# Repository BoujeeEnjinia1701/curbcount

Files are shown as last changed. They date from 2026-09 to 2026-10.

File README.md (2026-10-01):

# CurbCount

     

**Area:** Smart Cities · **TRL:** 3 of 9 (proof of concept on paper) · **Value-engineering target:** about $275 USD · **Difficulty:** 3 of 5

A privacy-safe counter for people, bicycles and vehicles at street level that uses on-device detection and sends only counts, never images.

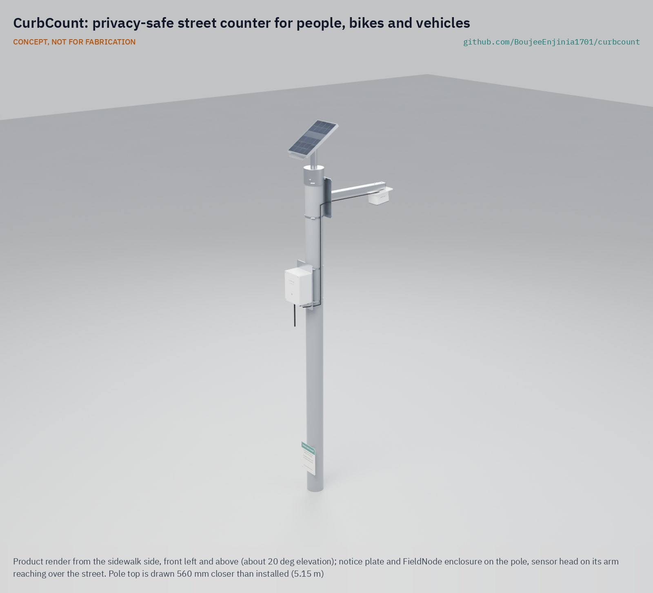
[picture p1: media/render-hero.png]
CurbCount: privacy-safe street counter for people, bikes and vehicles, product render


[Exploded render](media/render-exploded.png) · [Detail render](media/render-detail.png) · [Interactive 3D model](media/viewer.html) · [Concept blueprint (PDF)](media/concept-blueprint.pdf) · [General arrangement (PDF)](cad/drawings/CBC-DWG-001.pdf) · [Prototype build plan](docs/05-build-plan.md) · [Design decisions](docs/06-design-decisions.md) · [Calculations](docs/04-calcs/01-sizing.md) · [Review note](docs/REVIEW.md)

## Concept rationale

Counts without images give planners evidence while respecting residents. CurbCount uses a 32 x 24 pixel thermal array instead of a camera: from 4.3 m up it images a person's head at about 7.6 pixels per meter (8.5 for a 2 m person) and a number plate at under 2 pixels, so the sensor cannot capture a face or a plate even if its firmware were changed. The FieldNode core's own processor turns heat blobs into counts of people, cyclists and vehicles by direction, and only 15-minute counts leave the device.

It is open and garage-buildable because trust is the point. A city, a residents' group or a researcher can read the firmware, inspect the hardware and build their own from off-the-shelf parts, clamped to an existing pole on the lab's shared FieldNode power and radio core.

## Burning platform

Street redesign decisions are contested, and counts of people walking and cycling are usually missing. Road crashes kill about 1.19 million people a year, and more than half are pedestrians, cyclists and motorcyclists; pedestrians alone are 23 % and cyclists 6 % ([WHO, 2023](https://www.who.int/news/item/13-12-2023-despite-notable-progress-road-safety-remains-urgent-global-issue)). WHO also reports that 80 % of the world's roads fail to meet pedestrian safety standards (same source), and 92 % of road deaths occur in low- and middle-income countries ([WHO fact sheet](https://www.who.int/news-room/fact-sheets/detail/road-traffic-injuries)).

Fixing streets for people on foot and on bicycles needs evidence of how many use them, before and after a change. Motor traffic is counted routinely; walking and cycling rarely are, and the camera systems that could count them raise privacy concerns that stall deployment. The global goal of at least halving road deaths and injuries by 2030 ([WHO Global status report on road safety 2023](https://www.who.int/publications/i/item/9789240086517)) leaves little time.

## Where it could be used

### By industry

| Industry | Use |
| --- | --- |
| Municipal transport planning | Before and after counts for new bike lanes, wider sidewalks and school streets |
| Road safety engineering | Pedestrian and cyclist exposure at crossings, to turn crash counts into risk rates (with CrossSafe) |
| Retail and business districts | Footfall by hour and day on high streets and markets |
| Parks, trails and tourism | Use of promenades, greenways and trail heads without cameras |
| Transit operators | Walking and cycling flows on station access routes |
| Research and education | Open, reproducible active travel counts for universities and schools |

### By country or region

| Country or region | Why it matters there |
| --- | --- |
| Sub-Saharan Africa | More than a billion people in Africa walk or cycle every day, about 56 minutes a day against a global average of about 44 minutes, yet most countries lack policies and budgets for them ([UNEP](https://www.unep.org/resources/report/walking-and-cycling-africa-evidence-and-good-practice-inspire-action)) |
| India | Road crashes took about 300,000 lives in 2016, and most of those dying are pedestrians, cyclists and motorcyclists ([WHO India](https://www.who.int/india/health-topics/road-safety)) |
| Latin America and the Caribbean | In the Americas, motorcyclists, pedestrians and cyclists rose from 39 % to 47 % of road deaths between 2009 and 2021 ([PAHO](https://www.paho.org/en/topics/road-safety)) |
| United States | 7,522 pedestrians were killed in 2022, 18 % of all traffic deaths ([NHTSA](https://crashstats.nhtsa.dot.gov/Api/Public/ViewPublication/813590)) |
| England | Walking is 29 % of all trips and cycling 2 % ([Department for Transport, 2024](https://www.gov.uk/government/statistics/walking-and-cycling-statistics-england-2023)); councils need counts to justify active travel schemes |
| European Union | Data protection by design is a legal duty ([Regulation (EU) 2016/679, Article 25](https://eur-lex.europa.eu/eli/reg/2016/679/oj); [text of Article 25](https://gdpr-info.eu/art-25-gdpr/)), which favors counters that cannot capture personal data at all |

## What sparked the idea

The idea traces back to Toronto's Quayside waterfront project. In October 2018 Ann Cavoukian, the former Ontario privacy commissioner who wrote the privacy-by-design framework the project had adopted, resigned as its adviser because the proposed data trust could approve collection of data that was not de-identified at source. In her resignation letter she warned that such data would create "another central database of personal information (controlled by whom?)" ([The Globe and Mail, 2018](https://www.theglobeandmail.com/business/article-privacy-expert-ann-cavoukian-resigns-from-sidewalk-toronto-smart-city/)). CurbCount takes the lesson literally: de-identification at source should be a property of the sensor, not a policy promise, so it uses a sensor too coarse to capture a face in the first place.

## Problem

Cities plan streets with little data on walking and cycling, and camera-based counting raises privacy concerns.

## Concept

A privacy-safe counter for people, bicycles and vehicles at street level that uses on-device detection and sends only counts, never images.

A thermal array on a short arm looks down over the sidewalk, bike lane and nearest traffic lane; a standard FieldNode core (one LiFePO4 cell, 6 W panel) reads the array, tracks heat blobs in fixed-point firmware on its STM32WL, counts them by class and direction, and sends a 10-byte record every 15 minutes over LoRaWAN to TwinKit or any LoRaWAN server. The TRL 3 calculations ([CBC-CAL-001](docs/04-calcs/01-sizing.md)) give 0.10 W average from the cell, 6.2 days of counting without sun, a footprint 12.8 m across the street and 6 to 7 m along it, which covers a 3 m sidewalk, a 2 m bike lane and the nearest lane, 5.3 kg on the pole and an estimated $274.00 in parts against the $275 value-engineering target. No requirement is unmet on paper; three are at risk: counting fast cars (4.2 frames at 50 km/h), people walking close together, and counting on sunlit pavement. The thermal build is for temperate sites; a hot-climate city would use a radar variant. See the [requirements](docs/03-requirements.md) and the [decision record](docs/decisions/0002-recommendations-accepted.md).

Full design precis: [docs/02-concept.md](docs/02-concept.md)

## Key components

- Low-resolution thermal array (32 x 24 px, 110 x 75° lens, wide axis across the street) behind an HDPE window; mmWave radar as the hot-climate variant
- FieldNode power and radio core, standard: one LiFePO4 cell, 6 W panel, STM32WL running the tracker (an ESP32-S3 head is kept on paper as a fallback)
- Aluminum sensor arm, pole-top panel mount and stainless band clamps
- Public notice plate on the pole

The priced bill of materials is in [bom/bom.csv](bom/bom.csv); the parametric model is [cad/src/model.py](cad/src/model.py).

## Building the prototype

The [prototype build plan](docs/05-build-plan.md) shows how to build the first CurbCount, component by component, with a making sketch for each made part and a picture for every assembly step. Nothing is welded: the saddle plates seat on the pole through bent V-saddles and are held by band clamps, the arm and the pole-top mount are bolted from aluminium sheet, angle, bar and tube, and the sensor head and its window frame are 3D printed. The FieldNode core is built to FieldNode's own plan. Decisions still open are listed in the [design decisions register](docs/06-design-decisions.md).

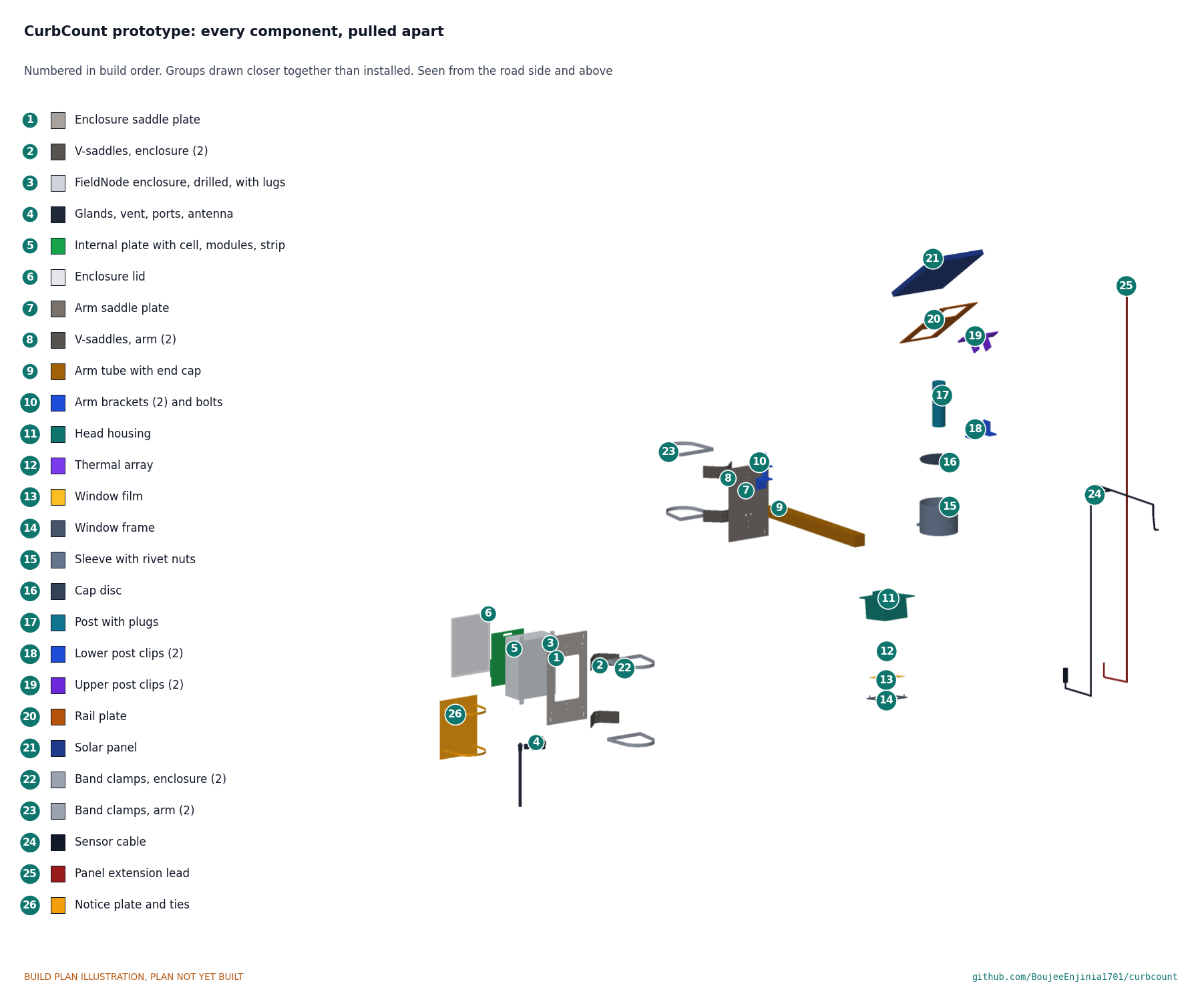
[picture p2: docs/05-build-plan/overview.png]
CurbCount prototype: every component, pulled apart and numbered in build order


## Safety

> Privacy by design: no images, audio recordings or personal identifiers leave the device; only aggregate counts or levels are stored. Check local data protection law before any deployment. Street furniture and pole mounts must be installed only with the asset owner's permission, by trained crews, with fall protection and traffic management as local rules require.
>
> The node contains a LiFePO4 cell: keep it fused and charge only within the cell maker's temperature limits. Fit safety lanyards to the panel and sensor head so nothing can fall on people below.

## Repository layout

| Folder | Contents |
| --- | --- |
| `docs/` | Problem, concept, requirements, calculations and design decisions |
| `cad/src/` | build123d Python source, the source of truth for all geometry |
| `cad/step/`, `cad/stl/` | Exported models for FreeCAD, other CAD tools and printing |
| `cad/drawings/` | 2D sketches and dimensioned drawings |
| `bom/` | Bill of materials |
| `electronics/` | KiCad schematics and PCB layouts |
| `firmware/` | Microcontroller code |
| `media/` | Renders, perspectives and photos |
| `build-log/` | Dated prototyping notes |

## Documentation

Controlled documents follow the portfolio [documentation standard](.kit/STANDARDS.md). Each carries a document ID (CBC-PRC-001 for the precis), a version and a revision history. Branded PDFs are built with `python .kit/render.py` and attached to GitHub Releases when a document is tagged, for example `CBC-PRC-001/v1.0`.

## Credits

Designed by Amish Chadha. See [CONTRIBUTORS.md](CONTRIBUTORS.md) for roles. To cite this design, use [CITATION.cff](CITATION.cff) (GitHub shows it as "Cite this repository").

AI assistance (Claude) was used to accelerate concept renders, prototype documentation and first-pass sizing calculations. Design direction and all decisions are Amish Chadha's, recorded in this repository's decision records (`docs/decisions/`).

## Licenses

- **Hardware** (CAD, drawings, BOM, electronics): [CERN-OHL-S v2](LICENSE)
- **Software** (firmware, scripts, notebooks): [MIT](LICENSE-SOFTWARE)

A project of the [Design Molecule](https://designmolecule.com) lab.

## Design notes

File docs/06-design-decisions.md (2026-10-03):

---
doc_id: CBC-DEC-001
title: CurbCount design decisions register
project: CurbCount
doc_type: Design decisions register
version: "0.4"
status: Draft
date: '2026-10-02'
author: Amish Chadha
license: CERN-OHL-S-2.0
revisions:
- version: "0.1"
  date: '2026-09-30'
  author: Amish Chadha
  change: Register opened with the build plan; open decisions gathered from the review note and the decision records
- version: "0.2"
  date: '2026-10-01'
  author: Amish Chadha
  change: Budget treated as a value-engineering target
- version: "0.3"
  date: '2026-10-02'
  author: Amish Chadha
  change: "Amish approved the recommendations for all nine open decisions on 2026-10-02 (CBC-DDR-003 accepted); moved to decisions made"
- version: "0.4"
  date: '2026-10-02'
  author: Amish Chadha
  change: Decisions 5 to 9 carried into model.py, the appearance model and the BOM
---

# CurbCount design decisions register

Every design decision still to be made, and every decision made, in one place. Each decision is argued in full in its decision record under `docs/decisions/` or in the review note; this register is the index Amish works from. The build plan (`docs/05-build-plan.md`, CBC-BLD-001) describes the design as it stands and does not list open decisions.

## Open decisions

None. All open decisions were decided on 2026-10-02.

## To confirm when parts are bought

*Table 2. Things to check against the real part before it is used.*

| # | What to confirm | Why it matters | Source |
| --- | --- | --- | --- |
| 1 | The solar panel's frame has a flat back lip at least 12 mm wide at its short ends | The rail plate bolts through it; without it the panel cannot be fixed as drawn | CBC-DDR-003, P5 |
| 2 | The enclosure model, its boss spacing (110 x 160 mm assumed) and its lug kit | They set the internal plate holes and the lug screw holes in the saddle plate | FND-DDR-003; CBC-DDR-003, P2 |
| 3 | Band clamps that close on the loop for the site pole: about 470 mm on a 114 mm pole (330 mm on 60 mm, 545 mm on 140 mm) | A worm-drive band has a limited range; the wrong size will not tighten | CBC-DDR-003, P1 |
| 4 | The sleeve tube's bore is at least 122 mm, and the cap disc fits it closely | The sleeve must clear a 114.3 mm pole by 3 to 4 mm all round | CBC-DDR-003, P5 |
| 5 | The band torque that gives 1,000 N of preload | The twist calculation assumes that preload | CBC-CAL-001 [H3] |
| 6 | The sensor cable has five cores of about 0.25 mm², a moulded M12 A-coded plug and an open end | The open end goes through the head gland to the breakout | CBC-DDR-003, P6 |
| 7 | Prices of every BOM line | The estimate is $1.00 under the $275 value-engineering target | CBC-CAL-001 [J1] |

## Value engineering

Value-engineering target: USD 275 (a hypothetical control target, not a limit). Estimated cost of the constructable design: USD 274.00 (USD 1.00 under the target). The estimate rests on indicative prices.

Main cost drivers: the FieldNode share (lines 1 to 3, 14 and part of line 13) at USD 105.00, FieldNode's own panel (line 4) at USD 14, and the parts added for construction together with FieldNode's repricing of its core, which took the total from USD 253.00 to USD 274.00. The ESP32-S3 fallback head would cost about USD 311.00, over the target.

Savings worth trying: leaving port B out of CurbCount's core (about USD 6 less, departing from the standard FieldNode core), and confirming prices when parts are bought.

## Decisions made

*Table 3. Decisions made, with the words recorded.*

| Date | Decision | Decided by | Record |
| --- | --- | --- | --- |
| 2026-09-25 | Batch taken through TRL 3, nothing past it | Amish: "you know the drill, nothing gets past TRL 3" | REVIEW 2026-09-25 (TRL 3) |
| 2026-09-25 | TRL 2 items D1 to D7: $275 value-engineering target, thermal array first with radar as the hot-climate variant, FieldNode high-load variant raised with FieldNode, processor study, 15-minute bins and three classes, jumper-only calibration, public notice plate | Amish: "i accept all your recommendations, go with them across all repos." | CBC-DDR-001, CBC-DDR-002 |
| 2026-09-25 | Tracking on FieldNode's STM32WL as the baseline with the ESP32-S3 head as fallback; one cell and the 6 W panel; R4 restated in px/m; R7 for temperate sites; R11 kept at 6 kg; 10-byte record | Amish, same instruction | CBC-DDR-002, items 3 to 8 |
| 2026-09-30 | Build plan format approved for all repos; outstanding decisions kept out of the build plan, in this register | Amish: "this is the correct build plan ... this is a good quality document format. Extend this across all the other repos" | This register; CBC-BLD-001 |
| 2026-09-30 | Make the design physically buildable while drawing the build plan | Amish: "If you are realising that the design cannot be built as per concept - fix the design assumptions to match and be physically feasible as you draw the illustrations." | CBC-DDR-003 (changes made under this instruction; accepted on 2026-10-02, below) |
| 2026-10-02 | Design for construction accepted as a whole: the changes P1 to P7 of CBC-DDR-003 and their knock-on changes, as made | Amish: "i approve your recommendations for all 555 open decisions." | CBC-DDR-003, A2 |
| 2026-10-02 | First co-design partner: a city transport department that already runs manual or loop counts on a street with a bike lane and poles of 60 to 140 mm, with the first trial in a season with air under 20 °C. First candidate to approach: the City of Toronto's transportation services, which publishes its traffic count data | Amish: "i approve your recommendations for all 555 open decisions." | CBC-DDR-002, O1 |
| 2026-10-02 | Sensor port: CurbCount's position to agree with FieldNode is one common pin order for both ports (supply, ground, I2C data, I2C clock, spare), each port's supply voltage set by a per-project supply module (switched 3.3 V on port A for CurbCount), and the calibration jumper sensed on FieldNode's service header | Amish: "i approve your recommendations for all 555 open decisions." | REVIEW 2026-09-25 cross-repo actions; FND-DDR-001, O2 |
| 2026-10-02 | Pole top drawn 560 mm lower in the photoreal renders accepted as a render-only layout; the caption says it is drawn closer than installed | Amish: "i approve your recommendations for all 555 open decisions." | REVIEW 2026-09-26, item 1 |
| 2026-10-02 | Notice plate rendered at its installed 2.6 m, not 4.15 m | Amish: "i approve your recommendations for all 555 open decisions." | REVIEW 2026-09-26, item 2 |
| 2026-10-02 | Notice plate wording adopted with one fix: "No images are stored or sent; only counts leave the device" replaces "No images are taken or stored"; the rest and the repository link are kept | Amish: "i approve your recommendations for all 555 open decisions." | REVIEW 2026-09-26, item 3 |
| 2026-10-02 | Status light on the sensor head dropped | Amish: "i approve your recommendations for all 555 open decisions." | REVIEW 2026-09-26, item 4 |
| 2026-10-02 | "COUNTS ONLY" plaque embossed into the printed head housing (BOM line 8); the enclosure label is part of BOM line 1 | Amish: "i approve your recommendations for all 555 open decisions." | REVIEW 2026-09-26, item 5 |
| 2026-10-02 | Head window bezel and head bolts of the appearance model closed as superseded by the window frame and M5 bolts of CBC-DDR-003, P4; the appearance model was updated to match on 2026-10-02 | Amish: "i approve your recommendations for all 555 open decisions." | REVIEW 2026-09-26, item 6; CBC-DDR-003, P4 |

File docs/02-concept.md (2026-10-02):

---
doc_id: CBC-PRC-001
title: CurbCount design precis
project: CurbCount
doc_type: Design precis
version: "0.7"
status: Draft
date: '2026-10-02'
author: Amish Chadha
license: CERN-OHL-S-2.0
revisions:
- version: "0.1"
  date: '2026-09-25'
  author: Amish Chadha
  change: Initial scaffold
- version: "0.2"
  date: '2026-09-25'
  author: Amish Chadha
  change: Populate to TRL 2 (architecture, first-order numbers, safety, media)
- version: "0.3"
  date: '2026-09-25'
  author: Amish Chadha
  change: TRL 3 update from CBC-CAL-001 and CBC-DDR-001 (array turned 90 degrees, aluminium panel mount, FieldNode TRL 3 enclosure, notice plate, numbers replaced by calculated values, design choices adopted for TRL 3)
- version: "0.4"
  date: '2026-09-25'
  author: Amish Chadha
  change: Recommendations accepted by Amish (DDR-002)
- version: "0.5"
  date: '2026-09-30'
  author: Amish Chadha
  change: "Design for construction (CBC-DDR-003): saddles, arm brackets, head fixing and a bolted pole-top mount; mass, cost and wind figures from CBC-CAL-001 v0.3"
- version: "0.6"
  date: '2026-10-01'
  author: Amish Chadha
  change: Budget treated as a value-engineering target
- version: "0.7"
  date: '2026-10-02'
  author: Amish Chadha
  change: "Decisions of 2026-10-02: CurbCount's sensor port position for FieldNode, first candidate partner, notice plate privacy wording"
---

# CurbCount design precis

CurbCount is a clamp-on street pole counter. A 32 x 24 pixel thermal array looks down from 4.3 m over the sidewalk, bike lane and nearest traffic lane; FieldNode's STM32WL turns the heat blobs into counts of people, cyclists and vehicles by direction and sends only 15-minute counts over LoRaWAN. The sensor images a person's head at 7.6 px/m (8.5 px/m for a 2.0 m person), far below what is needed to recognize anyone, so privacy does not depend on the firmware. The calculations in CBC-CAL-001 v0.4 show that on standard FieldNode power (one cell, 6 W panel) it can count for 6.2 days without sun and stay energy neutral in winter, weighs 5.26 kg on the pole and costs an estimated $274.00 in parts against the $275 value-engineering target. A thermal-only counter goes blind for much of a hot day, so this build is for temperate sites; hot-climate sites use the radar variant (CBC-DDR-002).

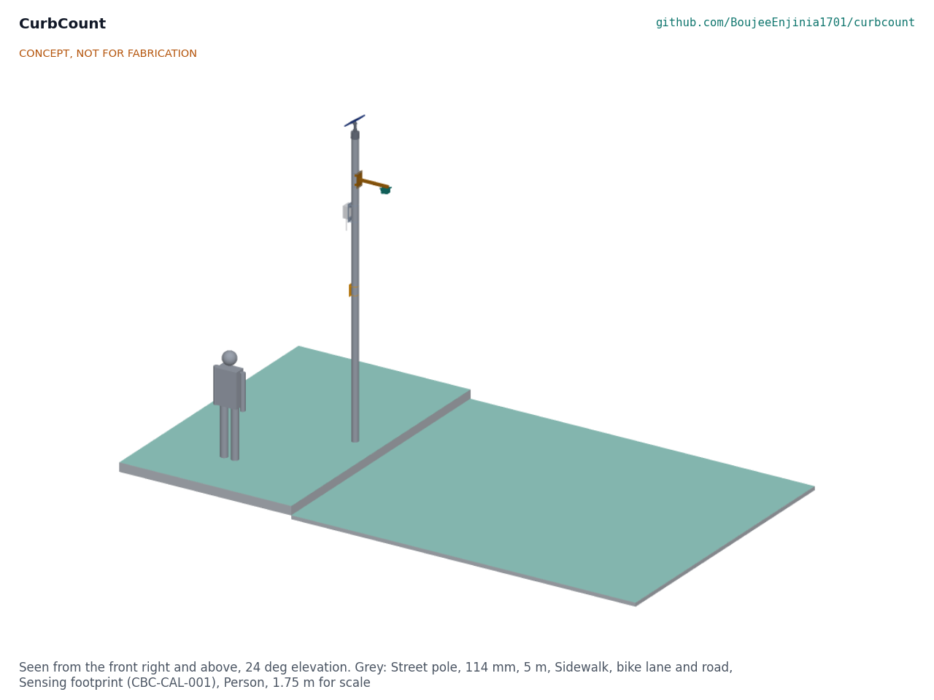
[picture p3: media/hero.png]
Figure 1. CurbCount on a street pole with a 1.75 m person for scale; the teal area is the calculated sensing footprint


## How it works

1. **Sense.** The thermal array reads 32 x 24 temperatures in two chess-pattern subpages, 16 a second, giving 8 full frames a second. Its 110 degree axis spans the street. People, cyclists and engines stand out from the pavement as warm (or, on hot pavement, cool) blobs.
2. **Track.** FieldNode's STM32WL reads the array over I²C through the M12 cable and, in fixed-point firmware, keeps a slowly updated background, subtracts it, finds blobs and follows each blob across frames. Frames live only in RAM and are overwritten every 125 ms.
3. **Classify.** Each finished track is classed as pedestrian, cyclist (including e-scooters and other micromobility) or motor vehicle from its size, speed and zone (sidewalk, bike lane or nearest lane), and given a direction along the street. The far part of the road is masked.
4. **Count.** Tracks increment six counters (three classes by two directions); the track data is then deleted. Every 15 minutes the counters close as one 10-byte record (six 12-bit counters and a status byte), small enough for US915 DR0.
5. **Send.** The FieldNode core sends each record over LoRaWAN to the lab's TwinKit gateway, a city server or The Things Network, with a daily health message (battery, temperature, frame errors).

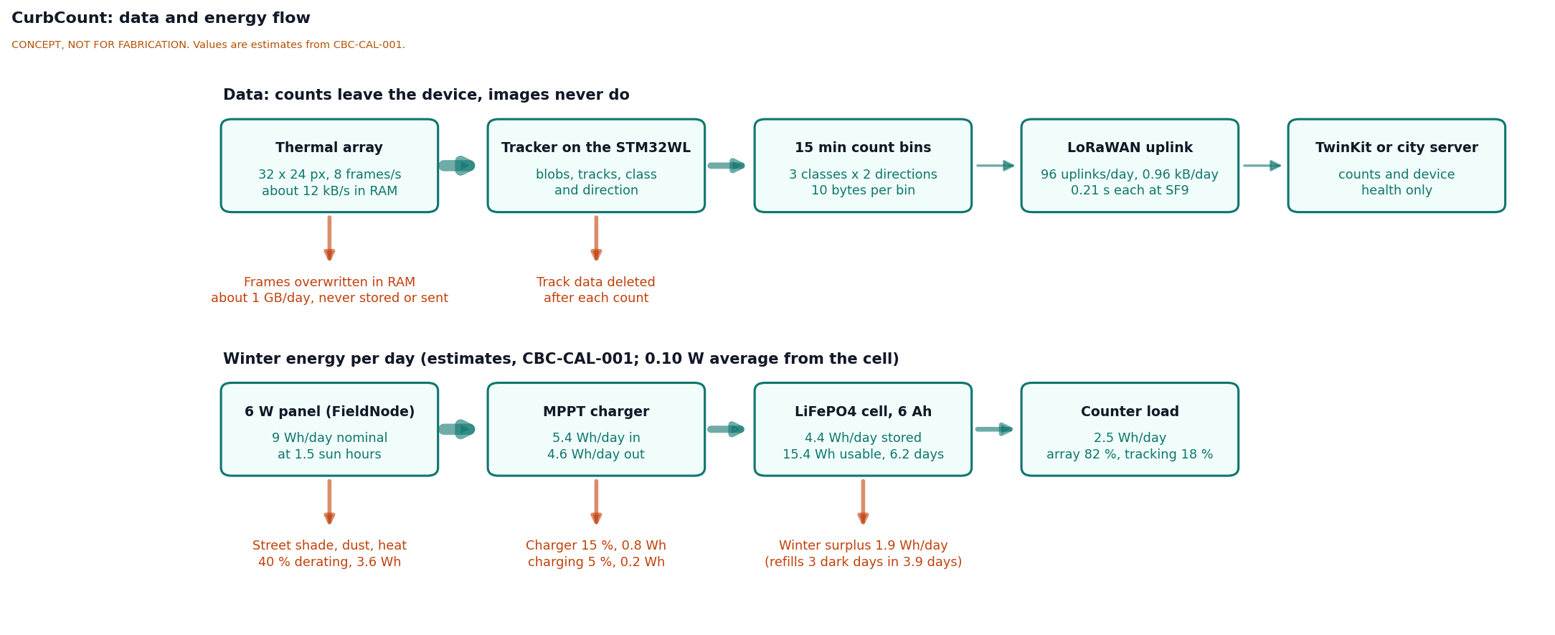
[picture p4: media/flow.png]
Figure 2. Data and energy flow (estimates from CBC-CAL-001)


## Main components

Table 1. Main components. Numbers match the exploded view (Figure 3), `bom/bom.csv` and `cad/src/model.py`.

| # | Component | Choice | Notes |
| --- | --- | --- | --- |
| 1 | FieldNode enclosure with ports and antenna | IP65 polycarbonate, 150 x 90 x 200 mm on four lugs, two M12 5-pin ports, two glands, vent and the whip in two rows on the bottom face | FieldNode's constructable core (FND-DDR-003), unchanged |
| 2 | FieldNode power and radio board | MPPT charger with cold-charge lockout, STM32WL-class LoRaWAN module, switched sensor rails; also runs the tracker | From FieldNode, standard charger setting (DDR-002) |
| 3 | LiFePO4 cell | One 3.2 V 6 Ah cell, FieldNode standard | Standard FieldNode power (DDR-002) |
| 4 | Solar panel | 6 W, 290 x 200 mm, 9 V class, FieldNode standard | Standard FieldNode power (DDR-002) |
| 5 | Panel pole-top mount | Aluminium sleeve with set screws over the pole top, cap disc, 42.4 mm post on angle clips, rail plate 290 x 150 mm at 35 degrees; all bolted | Panel bolted through its frame lip (CBC-DDR-003) |
| 6 | Band clamps and enclosure saddle | Four 12 mm stainless bands through slots in the saddle plates, aluminium saddle plate on two bent V-saddles, for 60 to 140 mm poles | No drilling; FieldNode's V-blocks fit only 40 to 60 mm poles |
| 7 | Sensor arm | 40 x 40 x 2 mm aluminium tube, 498 mm, bolted to a saddle plate on V-saddles by two angle brackets; head 530 mm from the pole axis | Keeps the head clear of the pole |
| 8 | Sensor head housing | 3D-printed ASA, 110 x 90 x 70 mm, with a sun hood | View tilted 7.5 degrees toward the road |
| 9 | Window | 0.5 mm HDPE film, about 0.75 transmission at 8 to 14 µm (estimate) | Far cheaper than germanium; to be measured |
| 10 | Thermal array | MLX90640 class, 32 x 24 px, 110 x 75 degree lens, 110 degree axis across the street; read over I²C by the STM32WL | DDR-001 D2; radar is the hot-climate variant (DDR-002) |
| 11 | Sensor cable | M12 5-pin, about 2 m, to a FieldNode sensor port carrying I²C and 3.3 V | Pinout to agree with FieldNode |
| 12 | Public notice plate | 150 x 200 mm aluminium plate at 2.6 m | DDR-001 D7 |

The separate ESP32-S3 edge processor of v0.3 is removed (DDR-002). It stays on paper as a fallback, with FieldNode's high-load power variant (a second cell and a 20 W panel), if bench profiling at TRL 4 shows the STM32WL cannot run the tracker. The calibration jumper (DDR-001 D6) moves to FieldNode's service header; its link is in the hardware set, BOM line 13.

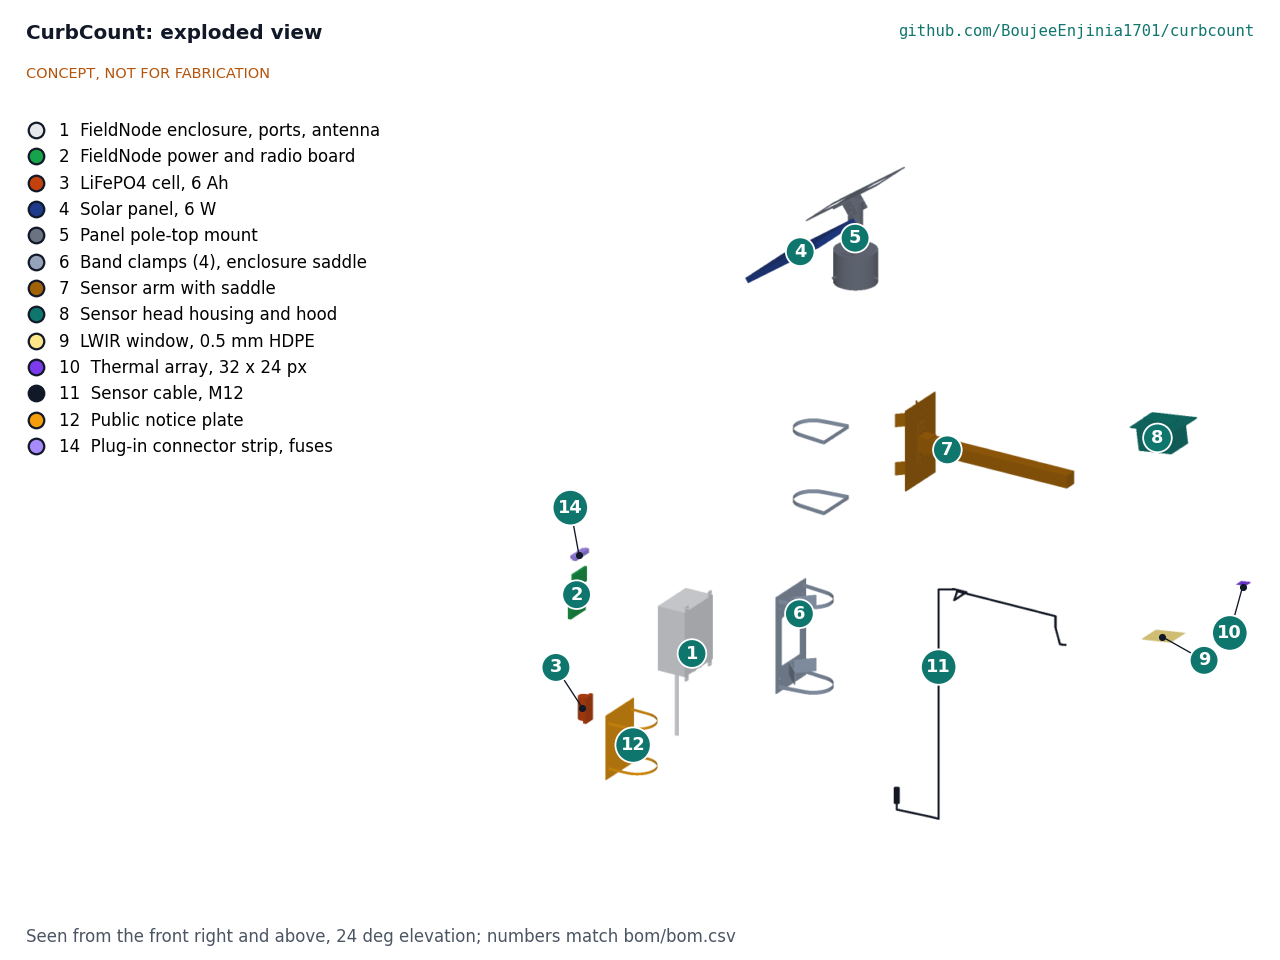
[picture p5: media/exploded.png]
Figure 3. Exploded view with BOM numbers


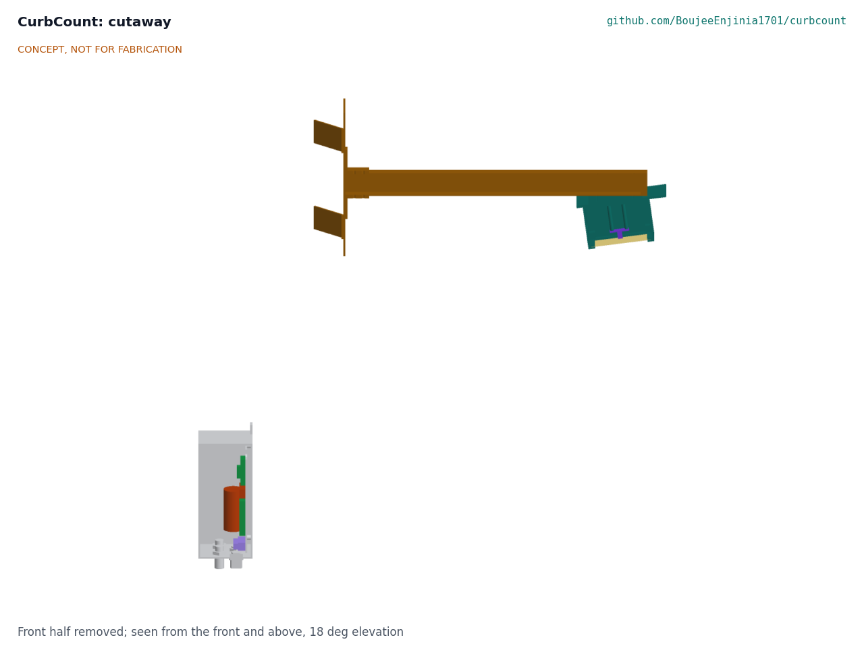
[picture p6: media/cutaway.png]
Figure 4. Cutaway: sensor head with array and window (top right); FieldNode enclosure with cell and board (bottom left)


The parametric model is `cad/src/model.py` (STEP and STL in `cad/step/` and `cad/stl/`), and the general arrangement is drawing [CBC-DWG-001](../cad/drawings/CBC-DWG-001.pdf). Every part can be made in a small workshop and every joint is bolted (design for construction, CBC-DDR-003); the illustrated [prototype build plan](05-build-plan.md) (CBC-BLD-001) shows how, and open decisions are in the [design decisions register](06-design-decisions.md).

## Key numbers

Table 2. Key numbers from CBC-CAL-001 v0.4. Tags refer to lines of `docs/04-calcs/sizing.py` output.

| Quantity | Value | Requirement |
| --- | --- | --- |
| Footprint across the street | 4.45 m behind the curb to 8.34 m into the road [A2] | R6 met on paper |
| Footprint along the street | 5.71 to 7.28 m [A5] | |
| Resolution at head height | 7.6 px/m (1.75 m person), 8.5 px/m (2.0 m) [B2] | R4 met on paper |
| Frames per crossing | 30 for pedestrians, 7.7 for cyclists at 25 km/h, 4.2 for cars at 50 km/h [C1] | R1 at risk |
| Hours below detection contrast, mild day | 10.2 h sunlit, 3.2 h with track averaging, 0 h shaded [D5] | R7 at risk (temperate sites) |
| Load from the cell | 103 mW average, 2.47 Wh/day [E1] | 92 % of FieldNode's proposed 100 mW allowance |
| Autonomy | 6.22 days; 4.36 days at -20 °C [E2] | R8 met on paper |
| Winter harvest, 6 W | 4.4 Wh/day, 1.77 times the draw [E3] | R9 met on paper |
| Uplink | 10 bytes per 15 min; 206 ms at SF9, 0.82 s/h; 371 ms at US915 DR0 [G1, G2] | R5 met; R15 met on paper |
| Wind on panel | 52 N at 35 m/s; post factor 55 [H1] | R12 |
| Mass on the pole | 5.26 kg [H5] | R11 met on paper |
| Parts cost | $274.00 estimated against the $275 value-engineering target [J1] | R13 within the value-engineering target ($1.00 under) |

Counts will still run low where parked vans, trees and awnings hide the footprint, and where people walk side by side.

## Key design choices

All choices below were decided by Amish on 2026-09-25 (CBC-DDR-001 and CBC-DDR-002).

- **Thermal array rather than a camera.** At 32 x 24 pixels the sensor cannot capture an identifiable image at the mounting height used here, so privacy does not depend on trusting the firmware.
- **Thermal build for temperate sites, 60 GHz radar for hot climates.** Without the radar variant the counter does not work in hot weather (CBC-CAL-001 section D). The radar variant is brought forward for any hot partner city; no partner city has been chosen.
- **Array turned so its wide axis spans the street.** It covers the full design case (R6) at the cost of fewer frames per fast vehicle (R1).
- **Frames never leave RAM.** The firmware has no code path that writes or sends a frame. A calibration mode shows frames on a laptop only through a physical jumper on FieldNode's service header, never over the radio.
- **Tracking on FieldNode's STM32WL, on standard FieldNode power.** Fixed-point tracking brings the head to 92 mW, inside FieldNode's allowance, so one cell and the 6 W panel suffice. The ESP32-S3 head on FieldNode's high-load variant is the fallback.
- **15-minute bins, three classes by two directions, in a 10-byte record.**
- **Public notice plate on every pole.**

## Safety

> **Safety:** Installing on a street pole is work at height next to traffic. Install only with the pole owner's permission, by trained crews, with fall protection and traffic management as local rules require. Keep clear of overhead power lines and street-light wiring, and never open a pole's electrical hatch. The pole owner must check that the pole can carry the extra 52 N wind load at 5.3 m.

> **Safety:** The node contains one LiFePO4 cell, about 19 Wh. Keep its fuse, charge only within the cell maker's temperature limits (FieldNode's cold- and hot-charge lockout applies), and do not install a node with a swollen or damaged cell. The ESP32-S3 fallback would add a second cell and a 20 W panel that can deliver 5 A; that variant needs its own fusing and charger setting.

> **Safety:** A falling part from 4 to 5.5 m can injure people below. Use a secondary safety lanyard on the panel and the sensor head, torque the sleeve set screws and bands, and check clamps after the first storm.

**Privacy.** No images, audio recordings or personal identifiers leave the device; only aggregate counts are stored or sent. Any change to a higher-resolution sensor needs a fresh privacy review. Check local data protection law before any deployment, and fit the notice plate saying what is counted, that no images are stored or sent and only counts leave the device, and where the design is documented.

## Open questions

- Measure HDPE window transmission at 8 to 14 µm and the MLX90640 noise at 16 Hz (TRL 4, on hold).
- Profile the fixed-point tracker on the STM32WL and check I²C over the 2 m cable on a street pole (TRL 4, on hold).
- Define the tracker for merged blobs (groups, parents with strollers) and the target accuracy per class.
- Agree the M12 pinout, the calibration jumper and the 60 to 140 mm pole saddle with the FieldNode project. CurbCount's position, decided by Amish on 2026-10-02 (CBC-DEC-001, item 3): one common pin order for both ports (supply, ground, I2C data, I2C clock, spare), each port's supply set by a per-project supply module (switched 3.3 V on port A here), and the jumper sensed on FieldNode's service header.
- Find a side-arm panel mount for poles whose top carries a lantern (suggestion).
- First co-design partner (decided by Amish, 2026-10-02): a city transport department that already runs counts on a street with a bike lane, first trial in a season with air under 20 °C; the first candidate to approach is the City of Toronto's transportation services. A hot partner city or a summer pilot would bring the radar variant forward.

Concept media: [blueprint sheet](../media/concept-blueprint.pdf), [interactive 3D model](../media/viewer.html).

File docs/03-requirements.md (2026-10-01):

---
doc_id: CBC-REQ-001
title: CurbCount requirements
project: CurbCount
doc_type: Requirements
version: "0.6"
status: Draft
date: '2026-10-01'
author: Amish Chadha
license: CERN-OHL-S-2.0
revisions:
- version: "0.1"
  date: '2026-09-25'
  author: Amish Chadha
  change: Initial scaffold
- version: "0.2"
  date: '2026-09-25'
  author: Amish Chadha
  change: Populate to TRL 2 (numbered, measurable requirements with targets and concept status)
- version: "0.3"
  date: '2026-09-25'
  author: Amish Chadha
  change: TRL 3 status from CBC-CAL-001; design case bike lane 2.0 m to match R6; decisions from CBC-DDR-001 reflected; proposed restatements of R4 and R11 noted
- version: "0.4"
  date: '2026-09-25'
  author: Amish Chadha
  change: Recommendations accepted by Amish (DDR-002)
- version: "0.5"
  date: '2026-09-30'
  author: Amish Chadha
  change: Status figures from CBC-CAL-001 v0.3 after the design for construction (CBC-DDR-003); no status changed
- version: "0.6"
  date: '2026-10-01'
  author: Amish Chadha
  change: Budget treated as a value-engineering target
---

# CurbCount requirements

These requirements are targets for concept review and must be revised with a co-design partner before the design is frozen. The design choices behind them (thermal array, tracking on FieldNode's STM32WL with standard FieldNode power, 15-minute bins and three classes in a 10-byte record, jumper-only calibration, public notice) were decided by Amish on 2026-09-25 (CBC-DDR-001 and CBC-DDR-002). Version 0.4 applies his decisions: R4 is restated in pixels per meter at head height, R7 is restated for temperate sites, R13 follows the new $275 value-engineering target, and R11 stays at 6 kg. Version 0.5 takes its figures from CBC-CAL-001 v0.4, after the design for construction (CBC-DDR-003); no status changed. Status is taken from the calculation note CBC-CAL-001 v0.4; "met on paper" means met by calculation only. No requirement is **not met**. Three are at risk (R1, R2, R7) and four cannot be shown at TRL 3 (R3, R10, R12, R14).

Design case: one counter on a 114 mm pole 0.45 m behind the curb, sensor window 4.3 m above the road, a 3 m sidewalk, a 2.0 m bike lane and one 3.5 m traffic lane.

Table 1. Requirements.

| ID | Requirement | Target | Verification | Status (CBC-CAL-001 v0.4) |
| --- | --- | --- | --- | --- |
| R1 | Count pedestrians, cyclists (including micromobility) and motor vehicles in the nearest lane, by direction along the street | 3 classes x 2 directions | Test against manual counts | At risk: 4.2 frames for a car at 50 km/h, 4 assumed needed |
| R2 | Count accuracy for pedestrians and cyclists | Within ±10 % of manual counts per hour at flows up to 600 per hour per direction | Field comparison with manual counts | At risk: random merging alone loses 6.5 %; groups add more |
| R3 | Count accuracy for motor vehicles in the nearest lane | Within ±15 % of manual counts per hour | Field comparison | Not verifiable at TRL 3 (4.2 frames, 3.4 px smear) |
| R4 | Privacy: no image, audio or identifier leaves the device; frames held only in RAM; sensor unable to resolve faces or plates | 8 px/m or less at head height for a 1.75 m person, below the IEC 62676-4 detection level of 25 px/m (restated in v0.4; was a ground pixel of 0.25 m or larger) | Design review, firmware audit, geometry | Met on paper: 7.6 px/m (8.5 px/m for a 2.0 m person) |
| R5 | Output format | 15-minute counts per class and direction in an open, documented 10-byte record (six 12-bit counters and a status byte) over LoRaWAN | Design review | Met by design |
| R6 | Coverage from one pole | Full width of a 3 m sidewalk, a 2 m bike lane and the nearest lane | Geometry, field check | Met on paper with the array turned 90 degrees: -4.45 to 8.34 m across |
| R7 | Operating range | Survive -20 °C to +50 °C; count at temperate sites (design days with air up to 20 °C). Hot-climate sites use the mmWave radar variant (restated in v0.4; was counting with air up to 35 °C) | Thermal chamber, seasonal field test | At risk: on the mild design day sunlit pavement hides pedestrians for 10.2 h with single frames, 3.2 h with track averaging; shaded 0 h |
| R8 | Autonomy without sun | 3 days of continuous counting | Energy budget, bench test | Met on paper: 6.22 days on one cell (4.36 at -20 °C) |
| R9 | Energy neutral in winter | At 1.5 peak sun hours with street shading derating | Energy budget, field log | Met on paper: FieldNode's 6 W panel stores 4.4 Wh/day against 2.47 Wh/day |
| R10 | Ingress protection | IP65 for the enclosure and the sensor head | Spray test | Not verifiable at TRL 3 |
| R11 | Mass on the pole | 6 kg or less | Weighing | Met on paper: 5.26 kg with the parts added for construction (4.44 kg in v0.4; 6.02 kg with the 20 W panel) |
| R12 | Installation | Two trained people, 60 min, no drilling, welding or pole wiring; withstands 35 m/s gusts | Timed trial, bracket calculation | Not verifiable at TRL 3: 59 min estimate; wind and fit met on paper |
| R13 | Parts cost | $275 or less per counter (value-engineering target, `budget_usd`; was $150) | Priced BOM | Within the value-engineering target: $274.00 ($1.00 under) |
| R14 | Service life | 5 years outdoors with one battery change | Design review, UV-stable materials | Not verifiable at TRL 3 |
| R15 | Radio use | Within EU868 1 % duty cycle and the US915 dwell limits | Airtime calculation | Met on paper: 0.82 s/h at SF9; 371 ms at US915 DR0 |

Table 2. Assumptions behind the targets.

| Assumption | Value | Source or basis |
| --- | --- | --- |
| Walking speed | 1.0 to 1.5 m/s | Typical design range (estimate) |
| Cyclist speed | up to 25 km/h | Typical urban maximum (estimate) |
| Vehicle speed in the nearest lane | up to 50 km/h | Common urban limit (estimate) |
| Peak sun hours, winter design case | 1.5 h | Mid-latitude winter (estimate) |
| Street shading and dust derating | 40 % | Estimate, to be checked on real poles |
| Temperate design day | Air 10 to 20 °C | CBC-CAL-001 section D |

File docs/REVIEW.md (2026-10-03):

# Review note: CurbCount

## Session 2026-10-02: open decisions decided by Amish

Amish wrote on 2026-10-02: "i approve your recommendations for all 555 open decisions." Every open decision in this repo's register was decided as recommended and moved to "Decisions made" in `docs/06-design-decisions.md`, dated 2026-10-02.

### Decisions recorded

9 decisions recorded (register items 1 to 9). The register's "Open decisions" section now reads: "None. All open decisions were decided on 2026-10-02."

### Documents changed

- `docs/06-design-decisions.md` v0.3
- `docs/decisions/0003-design-for-construction.md` v0.3
- `docs/decisions/0001-trl2-review-decisions.md` v0.3
- `docs/decisions/0002-recommendations-accepted.md` v0.2
- `docs/01-problem.md` v0.8
- `docs/02-concept.md` v0.7
- `docs/05-build-plan.md` v0.3 (CBC-DDR-003 recorded as accepted)

PDFs re-rendered with `python3 .kit/render.py`. The CAD model, BOM quantities and prices, and pictures were not changed.

### Follow-up actions to carry approved decisions into the design

1. Decision 3 (documents): Raise the common pin order, per-project port supply module and service-header jumper with the FieldNode project so FND-DDR-001 O2 can be decided there; AirStreet needs 5 V on its port A. FieldNode was not edited.
2. Decision 3 (BOM): Once FieldNode agrees the pin order, replace "(to agree with FieldNode)" in the BOM line 11 description with the agreed pin order.
3. Decision 4 (build plan pictures and renders): Check that the hero render caption says the pole top is drawn 560 mm closer than installed (5.15 m).
4. Decision 5 (build plan pictures and renders): Set the notice plate to its installed 2.6 m (`NOTICE_Z`) in `cad/src/product_model.py` and re-render on Amish's Mac.
5. Decision 6 (build plan pictures and renders): Change the plate's raised text in `cad/src/product_model.py` to "No images are stored or sent; only counts leave the device" and re-render; use the same wording on the printed plate face.
6. Decision 7 (build plan pictures and renders): Remove the status light from the sensor head in `cad/src/product_model.py` and re-render.
7. Decision 8 (model): Add the embossed "COUNTS ONLY" plaque to the printed head housing in `cad/src/model.py` and its print file, and note it in the BOM line 8 description (no price change).
8. Decision 9 (build plan pictures and renders): Update the appearance model to the window frame and M5 head bolts of CBC-DDR-003 P4 (with the other P1 to P7 fixings) and regenerate `media/render-*.png`, `media/card.png` and `media/social-preview.png` on Amish's Mac.

### Points found in the review

- Cross-repo conflict: CurbCount's build plan already replaces FieldNode's port A boost converter with a 3.3 V load switch, while AirStreet's build plan uses port A at 5 V for its particle sensor. FieldNode's pinout decision (FND-DDR-001, O2) is still open, so this build plan change runs ahead of FieldNode's agreement.
- The notice plate wording 'No images are taken or stored' is not strictly accurate: the thermal array captures frames that are processed on the device and can be viewed through the calibration jumper.
- Item 1's source is 'CBC-DDR-003, A2', but CBC-DDR-003 Table 3 has no A1; the numbering looks like a leftover.

TRL 4 remains on hold by Amish's instruction.

## Session 2026-09-25: /populate to a strong TRL 2

### What was done

- `docs/01-problem.md` (CBC-PRB-001 v0.2): problem, users, operating context, constraints, prior work with cited sources, out of scope, open questions; co-design checklist kept.
- `docs/02-concept.md` (CBC-PRC-001 v0.2): how it works, 12 numbered components, first-order numbers with assumptions, key design choices, safety and privacy, open questions.
- `docs/03-requirements.md` (CBC-REQ-001 v0.2): 15 measurable requirements (R1 to R15) with targets, verification and concept status, plus a design case and assumptions.
- `cad/src/concept_media.py`: massing model of the counter (FieldNode enclosure, board, cells, 20 W panel and bracket, clamps, arm, sensor head, window, thermal array, processor, cable), each part with a BOM number; street pole, sidewalk, road, sensing footprint and a 1.75 m person as grey context. Also draws a custom two-row data and energy flow diagram, because the kit's flow function takes only numeric losses.
- `media/`: `hero.png`, `concept-blueprint.png`, `.pdf` and `.svg`, `model.glb` and `viewer.html`, `exploded.png` (callouts 1 to 12 match the BOM), `cutaway.png` (enclosure and sensor head sectioned), `flow.png` (estimates labeled). Temporary `media/_views*` folders removed.
- `bom/bom.csv`: 13 lines with indicative USD prices; `bom/bom-notes.md` updated.
- `README.md`: hero image and links line, then the required sections (Concept rationale, Burning platform, Where it could be used with industry and country tables, What sparked the idea) expanded with cited figures; Concept, Key components and Safety updated to match.
- `project.yaml`: unchanged (pitch and problem remain correct).

### Key results (estimates, to be checked at TRL 3)

| Quantity | Estimate | Requirement |
| --- | --- | --- |
| Sensing footprint | about 12 m along x 6.9 m across (2.1 m behind curb to 4.8 m into the road) | R6 not met for a 3 m sidewalk |
| Ground pixel size | about 0.3 to 0.4 m | R4 met by design |
| Continuous load | about 0.30 W, 7.2 Wh/day | 2.4 times FieldNode's sensor budget |
| Autonomy | about 4.3 days (two cells); 2.1 days (one cell) | R8 met only with two cells |
| Winter harvest, 20 W panel | about 16 Wh/day | R9 met; not met with 6 W (about 4.9 Wh/day) |
| Uplink | 14 bytes per 15 min, about 0.8 s/h airtime | R5, R15 met |
| Mass on pole | about 4.2 kg | R11 met |
| Parts cost | about $271 | R13 not met ($150 budget) |

Requirements not met or at risk:

- **R13 (cost) not met:** about $271 against $150.
- **R6 (coverage) not met** for sidewalks wider than about 2 m from a pole at the curb.
- **R8 and R9 not met** with the standard FieldNode power parts (one cell, 6 W panel); met only with the proposed upgrade.
- **R2 (accuracy) at risk:** people walking side by side merge into one blob.
- **R7 (hot weather) at risk:** little thermal contrast when pavement and air are near body temperature.

### Proposed, awaiting Amish (items 1 to 7 now Decided by Amish, 2026-09-25: go with recommendation; item 8 still awaiting Amish; see CBC-DDR-002)

1. **Budget.** Options: (a) raise `budget_usd` to $275; (b) keep $150 and cost the FieldNode core (about $95 of the $271) under FieldNode, leaving about $176 for CurbCount parts, still over; (c) cut cost with an 8 x 8 thermal array and no separate processor, which weakens R1 and R2. Recommendation: (a). Decided by Amish, 2026-09-25: go with recommendation (`budget_usd` now $275, see the TRL 3 session item 2).
2. **Sensor.** Option A: 32 x 24 thermal array (cheap, low power, privacy by physics). Option B: 60 GHz mmWave radar (works in heat and darkness, costs and draws more). Recommendation: A for the first build, B studied as a hot-climate variant. Decided by Amish, 2026-09-25: go with recommendation.
3. **Power.** The counter needs a FieldNode "high-load" variant (20 W panel, second cell). Recommendation: raise this with the FieldNode project rather than changing FieldNode here. Decided by Amish, 2026-09-25: go with recommendation.
4. **Processor.** ESP32-S3 in the sensor head, or tracking on FieldNode's STM32WL alone. Recommendation: ESP32-S3 first; STM32WL-only as a TRL 3 study. Decided by Amish, 2026-09-25: go with recommendation.
5. **Count interval** of 15 minutes, and three classes (pedestrian, cyclist or micromobility, motor vehicle). Recommendation: adopt both. Decided by Amish, 2026-09-25: go with recommendation.
6. **Calibration mode** that shows frames on a laptop through a physical jumper only. Recommendation: allow it, never over the radio. Decided by Amish, 2026-09-25: go with recommendation.
7. **Public notice** on each pole linking to this repository. Recommendation: yes. Decided by Amish, 2026-09-25: go with recommendation.
8. **First partner and street** for co-design. No recommendation; Proposed, awaiting Amish.

### Safety concerns

- Work at height beside traffic when installing; pole owner's permission, trained crews, traffic management.
- Falling parts from 4 to 5 m: safety lanyards on panel and head; about 170 N wind load on the panel to check.
- Two LiFePO4 cells (about 38 Wh): fusing and cold-charge lockout.
- Privacy: the design must stay unable to capture identifiable images; any future sensor change (for example to a higher-resolution array) needs a fresh privacy review.

### Notes and gaps

- The kit's `flow_diagram` accepts only numeric losses, so `flow.png` is drawn by a small function in `concept_media.py` in the kit's style.
- In the exploded view the tiny parts (thermal array, cells) are partly hidden by their callout circles at this scale, and callout 6 sits between the four clamps.
- The split of FieldNode's about $126 cost across BOM lines 1, 2, 3 and 5 is an estimate; the FieldNode BOM is the reference.
- Some candidate sources (Telraam, Eco-Counter product pages, FHWA Traffic Monitoring Guide) could not be fetched and were left out.
- The legacy `cad/src/model.py` placeholder is untouched (TRL 3 work).

### Recommended next step

Review this note and the media, then decide items 1 to 3. If approved, run `/advance-trl3` to check footprint, thermal contrast, window transmission, power and wind load by calculation, and to produce the parametric model and drawing sheet.

## Session 2026-09-25: TRL 3

On 2026-09-25 Amish asked for this batch of repos to be taken through the usual process with the instruction "you know the drill, nothing gets past TRL 3". He has not reviewed this repo's TRL 2 items one by one, so every item that carried a recommendation is adopted as recommended for TRL 3 under Amish's 2026-09-25 instruction, open for his review. This session ran `/advance-trl3` on that basis and stopped at TRL 3.

### What was done

- `docs/decisions/0001-trl2-review-decisions.md` (CBC-DDR-001 v0.1, status proposed): seven items adopted as recommended for TRL 3, open for Amish's review (D1 to D7), and two left open (O1, O2).
- `docs/04-calcs/01-sizing.md` (CBC-CAL-001 v0.1) and `docs/04-calcs/sizing.py`: coverage and occlusion, pixel size and privacy, frames per crossing, merging, window transmission and thermal contrast on three design days, energy and panel sizing, charger current, heat, a processor study (STM32WL alone), radio airtime and US915 limits, wind and mounting, mass, installation time, service life and cost, with a status for every requirement. The script imports the model's parameters and camera model, reads the BOM and `project.yaml`, prints every number the note quotes and writes `docs/04-calcs/results.csv`.
- `cad/src/model.py`: parametric build123d model (FieldNode enclosure with ports and antenna, board, two cells, 20 W panel, aluminium pole-top mount, bands and saddle plates, sensor arm, head with hood, window, array and processor, M12 cable, notice plate) with the sensor's camera model. Exports `cad/step/` and `cad/stl/` for `curbcount-assembly`, `sensor-head` and `power-core`.
- `cad/src/sheets.py` and `cad/drawings/CBC-DWG-001.svg`, `.pdf`, `.png`: general arrangement at Rev P1, 1:20, marked "CONCEPT, NOT FOR FABRICATION" and "PRELIMINARY, NOT FOR FABRICATION". CBC-DWG-001 was free because the concept blueprint is CBC-DWG-010. The sheet shows a pole stub only; heights above the road are labeled.
- `bom/bom.csv` (14 lines, all priced with a supplier or supplier type, $290.00) and `bom/bom-notes.md`. FieldNode lines are repriced to FieldNode's TRL 3 BOM; the public notice plate is new (line 13).
- `cad/src/concept_media.py` now builds from the model; all of `media/` was re-rendered (blueprint now Rev P2) and every image checked; temporary `_views` folders deleted.
- CBC-PRB-001, CBC-PRC-001 and CBC-REQ-001 revised to v0.3; `README.md` (TRL badge and line, links, Concept rationale figure, Concept numbers, key components) and `project.yaml` (`trl: 3`, `trl_target: 3`, evidence list) updated. PDFs rebuilt in `docs/pdf/`.

### Requirement status (CBC-CAL-001, Table 5)

3 not met, 4 at risk, 4 not verifiable at TRL 3, 3 met on paper, 1 met by design.

| ID | Status | Key number |
| --- | --- | --- |
| R13 Cost | **Not met** | $290.00 against $150, and $15 over the recommended $275 |
| R7 Hot weather | **Not met** on paper | Hot design day: pedestrian contrast below the 5.3 K threshold for 14.2 h (sunlit) and 24 h (shaded); 11.2 h even with track averaging |
| R4 Privacy as written | **Not met** as written | Smallest ground pixel 0.22 m against 0.25 m; privacy aim met at 8.5 px/m at head height against 250 px/m to identify |
| R1 Classes and directions | At risk | 4.2 frames for a car at 50 km/h (4 assumed needed) |
| R2 Pedestrian accuracy | At risk | Random merging alone loses 6.5 % at 600/h |
| R11 Mass | At risk | 6.02 kg against 6 kg (TRL 2 said 4.2 kg) |
| R15 Radio | At risk | 0.91 s/h at SF9 is fine; the 14-byte record does not fit US915 DR0 (11 bytes) |
| R3, R10, R12, R14 | Not verifiable at TRL 3 | R12: 59 min install estimate; panel 170 N, post factor 9, twist factor 3.2 |
| R6, R8, R9 | Met on paper | Footprint -4.45 to 8.34 m; 4.78 days without sun; 14.5 Wh/day stored against 6.43 Wh/day |
| R5 | Met by design | 14 bytes per 15 min bin |

Key numbers: 268 mW average from the cells (2.1 times FieldNode's 115 mW allowance); 5.0 A peak charge current from the 20 W panel; HDPE window transmission about 0.75 (estimate).

Design changes made from the calculations, open for Amish's review with the rest (now Decided by Amish, 2026-09-25: go with recommendation, CBC-DDR-002): the array is turned 90 degrees (110 degree axis across the street, 7.5 degree tilt), which moves R6 from not met to met on paper; the pole-top mount is aluminium (the steel one weighed 5.7 kg); the FieldNode enclosure takes its TRL 3 size (150 x 90 x 200 mm) on a CurbCount saddle plate.

### Decisions recorded (CBC-DDR-001)

Adopted as recommended for TRL 3 under Amish's 2026-09-25 instruction, open for his review (now all Decided by Amish, 2026-09-25: go with recommendation, CBC-DDR-002): D1 budget option (a), $275, recorded only, `budget_usd` unchanged at $150; D2 thermal array first, radar as a hot-climate variant; D3 FieldNode high-load variant, raised with FieldNode rather than changed there; D4 ESP32-S3 first, STM32WL-only studied (done, CBC-CAL-001 section F); D5 15-minute bins and three classes; D6 jumper-only calibration mode; D7 public notice plate. No reworded pitch or problem was recommended, so `project.yaml` and `README.md` keep the existing wording.

### Still awaiting Amish (items 2 to 8 now Decided by Amish, 2026-09-25: go with recommendation, CBC-DDR-002; item 1 still awaiting Amish)

1. **O1, first co-design partner and street.** No recommendation was made.
2. **O2, budget.** `budget_usd` stays $150. The recommended $275 is itself $15 short of the $290.00 BOM. Options: (a) $300; (b) $275 with the STM32WL-only variant (about $253); (c) keep $150 and accept R13 not met. Recommendation: (b), if item 3 is accepted; otherwise (a). Decided by Amish, 2026-09-25: go with recommendation: (b).
3. **New, move tracking to the STM32WL.** CBC-CAL-001 section F finds it feasible on paper with a fixed-point tracker (2 % of the core, 44 kB of 64 kB RAM) and it brings the head to 92 mW, inside FieldNode's allowance, so standard FieldNode power (one cell, 6 W) meets R8 and R9 and about 1.5 kg and $37 come off. Risks: I²C over the 2 m cable and the reference driver's floating-point cost. Recommendation: adopt as the baseline for the first build, keep the ESP32-S3 head as the fallback. Decided by Amish, 2026-09-25: go with recommendation.
4. **New, R7 and the sensor for hot climates.** A thermal-only counter goes blind for much of a hot day. Options: (a) restrict the thermal build to temperate sites and state it; (b) bring the radar variant forward as the hot-climate build; (c) a hybrid head. Recommendation: (a) now and (b) for any hot partner city. Decided by Amish, 2026-09-25: go with recommendation.
5. **New, restate R4.** Replace "ground pixel 0.25 m or larger" with "8 px/m or less at head height, below the IEC 62676-4 detection level of 25 px/m", which matches the privacy aim. Recommendation: adopt. Decided by Amish, 2026-09-25: go with recommendation.
6. **New, R11 mass.** 6.02 kg against 6 kg. Recommendation: keep 6 kg and meet it through item 3 (about 4.5 kg). Decided by Amish, 2026-09-25: go with recommendation.
7. **New, payload.** Pack the record into 10 bytes (six 12-bit counters and a status byte) so it fits US915 DR0 (R15). Recommendation: adopt. Decided by Amish, 2026-09-25: go with recommendation.
8. **New, raise with FieldNode (not edited here):** the high-load variant needs a charger set for 5 A and a second fused cell; CurbCount needs a 60 to 140 mm pole saddle; the sensor port pinout needs I²C or UART plus a 3.3 V rail. Decided by Amish, 2026-09-25: go with recommendation; listed under cross-repo actions in the 2026-09-25 recommendations-accepted session.

Suggestion only, not in the repo: a side-arm panel mount for poles whose top carries a lantern.

### Cross-repo consistency

- FieldNode (FND REVIEW, TRL 3): enclosure 150 x 90 x 200 mm, STM32WL-class module, two M12 5-pin ports with one switched rail each, 6 Ah LiFePO4 cell charging 0 to 45 °C, core cost $126.00, 15 min default interval, TwinKit first. CurbCount now uses all of these. Conflicts noted, FieldNode not edited: (1) FieldNode's mount kit seats 40 to 60 mm poles, street poles are about 114 mm, so CurbCount adds its own saddle; (2) FieldNode's charger is sized for a 6 W panel, CurbCount's 20 W panel needs 5 A; (3) FieldNode's proposed 100 mW sensor allowance leaves CurbCount's ESP32-S3 head (241 mW) far out and the STM32WL variant (92 mW) just inside; (4) FieldNode quoted CurbCount's core share as about $95, now $98.00 from FieldNode's own BOM.
- TwinKit: LoRaWAN concentrator and 15 min reporting; a 14-byte uplink at SF9 (226 ms) is within its sizing. No conflict.
- No other shared component (CellGuard, MotionCore, ThermaCart, CalRig) is used.

### Safety concerns

- Work at height next to traffic, as at TRL 2. The counter adds 170 N of wind load at 5.5 m (933 N·m at the pole base) that the pole owner must check; the sleeve bears on the pole top with about 750 N.
- Two LiFePO4 cells, about 38 Wh, and a charge current of up to 5 A: fuse each cell, keep the 0 to 45 °C charge lockout, and never defeat the heat lockout to recover energy in a heatwave (the cells run flat after about 8 hot clear days without a shield).
- Falling parts: lanyards on panel and head; set-screw and band torque to be specified at TRL 4.
- Privacy: 8.5 px/m at head height is the design's privacy guarantee. Any change to a higher-resolution array, or a lower mounting height, needs a fresh privacy review.

### Gaps and notes

- Citations: the TRL 2 note listed no unchecked citations in the docs (the Telraam, Eco-Counter and FHWA pages had been left out). This session quotes the IEC 62676-4 detection and identification levels from the standard; WebFetch could not reach a source (one domain cache-only, one approval timed out), so those figures are flagged here as not checked online. MLX90640, ESP32-S3 and STM32WL figures, the HDPE absorption and all surface temperatures are typical values or assumptions, not checked against datasheets.
- The thermal contrast model (section D) is the weakest part of the note; the hot-weather conclusion holds across the assumptions tried, the mild-day hours do not.
- The kit's cutaway still cuts near the origin, so `concept_media.py` shifts the scene down by the enclosure height (as at TRL 2). The exploded view's callouts 10 and 11 cover their small parts.
- Existing material beyond TRL 3: `build-log/README.md` (scaffold) is present, untouched and not extended. No test, build or firmware material exists or was created.

### Recommended next step

TRL 4 is on hold by Amish's instruction; this repo stops at TRL 3. Amish's review is needed on items 1 to 7 above and the design changes listed under the requirement table; item 8 should go to the FieldNode project. For the record only, TRL 4 would need: a bench build of the sensor head on a FieldNode core; a lab test report (TST, `environment: lab`) covering window transmission, array noise at 16 Hz, tracker CPU and RAM on the STM32WL, I²C over the cable, current draw and charge current; and build log entries. None of this has been started.

## Session 2026-09-25: recommendations accepted

On 2026-09-25 Amish wrote: "i accept all your recommendations, go with them across all repos." Every item in this note and in CBC-DDR-001 that carried a recommendation is now **Decided by Amish, 2026-09-25: go with recommendation**, recorded in `docs/decisions/0002-recommendations-accepted.md` (CBC-DDR-002 v0.1). The repo stays at `trl: 3`, `trl_target: 3`.

### Decisions applied and what changed

| Decision | Before | After |
| --- | --- | --- |
| Budget, option (b) (O2, TRL 3 item 2) | `budget_usd` $150; R13 target $150 | `budget_usd` $275; R13 target $275 |
| Tracking on the STM32WL as baseline, ESP32-S3 as fallback (TRL 3 item 3) | ESP32-S3 head, two cells, 20 W panel; head 241 mW; 6.43 Wh/day | No head processor, one cell, FieldNode's 6 W panel; head 92 mW; 2.47 Wh/day |
| Parts cost (follows the two above) | $290.00, 14 BOM lines | $253.00, 13 lines (line 11 removed, 12 to 14 renumbered 11 to 13) |
| Mass, keep R11 at 6 kg (TRL 3 item 6) | 6.02 kg, at risk | 4.44 kg, met on paper |
| Autonomy and winter harvest (R8, R9) | 4.78 days on two cells; 14.5 Wh/day from 20 W | 6.22 days on one cell; 4.4 Wh/day from 6 W (1.77 times the draw) |
| Payload of 10 bytes (TRL 3 item 7) | 14 bytes; does not fit US915 DR0; SF9 226 ms | 10 bytes; 371 ms at US915 DR0; SF9 206 ms |
| Restate R4 (TRL 3 item 5) | Ground pixel 0.25 m or larger; 0.22 m, not met | 8 px/m or less at head height; 7.6 px/m, met on paper |
| R7 restricted to temperate sites; radar for any hot partner city (TRL 3 item 4) | Counting with air to 35 °C; not met | Count at temperate sites (air to 20 °C); at risk (10.2 h sunlit single-frame, 3.2 h with track averaging on the mild day) |
| Wind on the panel (follows the 6 W panel) | 170 N; 933 N·m at the pole base | 52 N; 283 N·m |
| TRL 2 items D1 to D7 and the three TRL 3 design changes | Adopted for TRL 3, open for review | Decided; no further repo change |

Files changed: `project.yaml` (`budget_usd`, evidence list), `README.md` (budget line, rationale figures, "What sparked the idea" rewritten, Concept, Key components, Safety), `docs/01-problem.md` (CBC-PRB-001 v0.4), `docs/02-concept.md` (CBC-PRC-001 v0.4), `docs/03-requirements.md` (CBC-REQ-001 v0.4), `docs/04-calcs/01-sizing.md` (CBC-CAL-001 v0.2) and `sizing.py` with `results.csv`, `docs/decisions/0001-trl2-review-decisions.md` (CBC-DDR-001 v0.2), the new CBC-DDR-002, `bom/bom.csv` and `bom-notes.md`, `cad/src/model.py` with STEP and STL, `cad/src/sheets.py` and CBC-DWG-001 at Rev P2, `cad/src/concept_media.py` and all of `media/` (blueprint Rev P3). All PDFs were rebuilt; the footers now read designmolecule.com.

### Requirement status (CBC-CAL-001 v0.2)

0 not met, 3 at risk, 4 not verifiable at TRL 3, 7 met on paper, 1 met by design.

| ID | Status | Key number |
| --- | --- | --- |
| R1 Classes and directions | At risk | 4.2 frames for a car at 50 km/h (4 assumed needed) |
| R2 Pedestrian accuracy | At risk | Random merging alone loses 6.5 % at 600/h |
| R7 Operating range (temperate) | At risk | Mild day, sunlit: 10.2 h below single-frame contrast, 3.2 h with track averaging |
| R3, R10, R12, R14 | Not verifiable at TRL 3 | R12: 59 min install; post factor 38, twist factor 3.2 |
| R4, R6, R8, R9, R11, R13, R15 | Met on paper | 7.6 px/m; footprint -4.45 to 8.34 m; 6.22 days; 4.4 Wh/day; 4.44 kg; $253.00; 371 ms at DR0 |
| R5 | Met by design | 10 bytes per 15 min bin |

### Still awaiting Amish

1. **O1, first co-design partner and street.** No recommendation was made. A hot partner city would bring the radar variant forward (decided in principle, no design work until a partner is chosen).

### Cross-repo actions (FieldNode not edited here)

- FieldNode: CurbCount's baseline now fits FieldNode's standard power (one cell, 6 W panel, 1.5 A charger) and the proposed 100 mW sensor allowance (92 mW). The high-load variant (20 W panel, 5 A charger, second fused cell) is needed only by the ESP32-S3 fallback.
- FieldNode: the sensor port pinout needs I²C plus a 3.3 V switched rail, and the STM32WL firmware must host a fixed-point tracker (about 2 % of the core, 44 kB of 64 kB RAM estimated).
- FieldNode: a jumper-sense pin on the service header for CurbCount's calibration mode (frames to a laptop over the wired service port only).
- FieldNode: its mount kit seats 40 to 60 mm poles; CurbCount keeps its own 60 to 140 mm saddle. FieldNode may want a street-pole saddle option.

### Other changes

- README "What sparked the idea" rewritten: the new starting point is Ann Cavoukian's October 2018 resignation from the Sidewalk Labs Quayside project in Toronto over data not de-identified at source (cited to Engadget and Global News). The earlier text about a portfolio review was removed. No such text was found in `docs/01-problem.md`.
- Superseded PDFs in `docs/pdf` that still showed the old footer were deleted.

### Safety

- Lower loads on the pole: 52 N of panel wind load at 5.4 m instead of 170 N; the pole owner must still check it.
- One LiFePO4 cell (about 19 Wh) at FieldNode's standard 1.5 A charge; the ESP32-S3 fallback would reintroduce two cells and 5 A and needs its own fusing and charger setting.
- Privacy: 7.6 px/m at head height (8.5 px/m for a 2.0 m person) is the design's privacy guarantee. Any higher-resolution array or lower mounting height needs a fresh privacy review.

### TRL 4

TRL 4 remains on hold by Amish's instruction. Decided but on hold: profiling the fixed-point tracker on the STM32WL, I²C over the 2 m cable on a street pole, window transmission and array noise measurements, and any radar build or test. Nothing past TRL 3 was created.

## Session 2026-09-26: sources strengthened

Every link in the README's rationale, burning platform, use tables and inspiration was fetched and checked against its claim.

| Where | Old source | New source |
| --- | --- | --- |
| README, What sparked the idea (Cavoukian resignation, Quayside) | Engadget (2018) and Global News (2018) | The Globe and Mail (2018), which reports the resignation and quotes the letter |
| README, European Union row; `docs/01-problem.md` (GDPR) | gdpr-info.eu alone | Regulation (EU) 2016/679 on EUR-Lex, with gdpr-info.eu kept for the article text |
| `docs/01-problem.md` (AI Act Article 5) | artificialintelligenceact.eu alone | Regulation (EU) 2024/1689 on EUR-Lex, with artificialintelligenceact.eu kept for the article text |
| README, Sub-Saharan Africa row | "43.9-minute global average" | "about 44 minutes", as the UNEP page states it |

No country rows were replaced; all six are supported by their cited primary sources. `docs/01-problem.md` is now CBC-PRB-001 v0.5 ("Stronger sources").

## Session 2026-09-26: product appearance model and photoreal renders

Amish chose this repo for the first batch of product renders on 2026-09-26.

### What was done

- `cad/src/product_model.py` (new): a product appearance model for photoreal renders. `product_parts()` returns 60 parts (45 shell, 14 internal, 1 context), each with a colour, a render material, its BOM line and an exploded offset. `TITLE` and three `RENDER_VIEWS` are defined: `hero` (sidewalk side, front left, about 20 deg elevation, with a short pole section), `exploded` (same side, about 28 deg) and `detail` (street side, front right, about 14 deg, without the pole). Every dimension and interface comes from `PARAMS`, `derived()` and `build_parts()` in `cad/src/model.py`, which was not edited.
- What the appearance model adds over the massing model:
  - Sensor head: filleted ASA housing with a parting step to a dark window bezel and gasket, the HDPE window in its slot, the thermal array breakout, can and lens visible through the window, a filleted sun hood, a teal "COUNTS ONLY" plaque and a lit status light.
  - Arm: rounded 40 x 40 mm tube with a black end cap, filleted saddle plate, two bolts to the head.
  - Band clamps: stainless bands with worm-drive housings and screws; the arm bands pass over the saddle face.
  - FieldNode enclosure: filleted body with a lid parting step, lid with a shallow panel, four screws, a "CurbCount / FieldNode core" label and a lit status light; knurled M12 ports, a blanking cap, an M16 gland, an ePTFE vent and the whip antenna on its base.
  - Internals: power and radio board with components, controller with its STM32WL module shield, the LiFePO4 cell in a fused holder.
  - Solar panel with aluminium frame, cell grid, glass and junction box; pole-top sleeve with three set screws, post and hinge plate.
  - Sensor cable on the model.py route with rounded bends.
  - Public notice plate with a teal header and raised text: "PRIVACY-SAFE COUNTER", "Counts people, bikes and vehicles on the device.", "No images are taken or stored.", "Only counts are sent." and the repository link.
- `README.md`: hero image now points to `media/render-hero.png`, and the links line starts with the exploded render. The render files are produced separately by the orchestrator.
- Matplotlib self-check previews were made outside the repo (clear parts left out).

### Where the appearance model differs from model.py (Proposed, awaiting Amish)

1. **Pole top drawn 560 mm lower in the renders.** The sleeve, post, hinge plate and 6 W panel are moved down by `TOP_DROP` = 560 mm so the device fills the frame; installed, the pole top is at 5.15 m above the road. The hero caption says the pole top is drawn closer than installed. Recommendation: accept as a render-only layout; model.py, the drawing and the calculations keep the installed height.
2. **Notice plate drawn at 4.15 m instead of 2.6 m.** It sits between the enclosure saddle and the arm clamps (`NOTICE_Z`) so it appears in the product shot. Recommendation: accept for renders only; keep the installed height at eye level (2.6 m) as model.py gives.
3. **Notice plate wording and fixing.** The raised wording above is a proposal that meets BOM line 12 (what is counted, no images kept, repository link). The plate is shown riveted at its corners; model.py does not define the fixing. Recommendation: adopt the wording; decide the fixing (bands or rivets to a strap) at TRL 4.
4. **Status light on the sensor head.** Not in the BOM or the power budget. Options: drop it (the enclosure light already shows the device is running), or keep it as a public "counting" cue at about 1 mW average with a low duty cycle. Recommendation: drop it from the design and remove it from the appearance model unless Amish wants the public cue.
5. **Head "COUNTS ONLY" plaque and enclosure label.** Not separate BOM items. Recommendation: print or emboss the head plaque into the ASA housing (BOM line 8) and treat the enclosure label as part of BOM line 1.
6. **Window bezel and head bolts.** The massing model shows the housing open underneath with no clamp frame and does not define how the head fixes to the arm. The appearance model shows a 6 mm bezel frame taken from the 70 mm housing height (overall height unchanged) and two bolts through the arm into the hood. Recommendation: accept both as appearance intent; detail them at TRL 4.

### TRL

This is an appearance model only: no tolerances, no fabrication detail, no PCB layout. `trl` stays 3 in `project.yaml`. TRL 4 remains on hold by Amish's instruction, and nothing past TRL 3 was created.

## Session 2026-09-27: kit 1.5.0 and image quality

- Kit 1.5.0 synced: STANDARDS v1.5 (sections 12 to 15: product renders, storefront images and image quality, public release, authorship and signing), `.kit/cards.py`, `.kit/image_qc.py`, `.kit/release_gate.py`, issue templates, and the `/render-product` and `/release` commands. `CLAUDE.md` now matches `.kit/CLAUDE.md`.
- Every `media/render-*.png` recaptioned from its original render with the new layout: the title, concept label and repository sit in a band above the render and the view note in a band below it, each line wrapped to the image width, so no text overlaps other text or the render or runs off the image. `media/card.png` and `media/social-preview.png` regenerated with the same rules.
- `python .kit/image_qc.py` and `python .kit/release_gate.py` pass. trl stays 3.

## Session 2026-09-30: build plan and design for construction (kit 1.7.0)

On 2026-09-30 Amish approved the illustrated build plan format ("this is the correct build plan ... this is a good quality document format. Extend this across all the other repos"), asked that outstanding decisions go in a separate design decisions register, and wrote: "If you are realising that the design cannot be built as per concept - fix the design assumptions to match and be physically feasible as you draw the illustrations." This session applied that to CurbCount. The repo stays at `trl: 3`; nothing past TRL 3 was created.

### What was done

- Kit 1.7.0 installed (`.kit/`, `.claude/commands/`); `CLAUDE.md` now matches `.kit/CLAUDE.md`.
- `cad/src/model.py` rewritten as a constructable model (every component with its fixings) with 106 build123d constructability checks (`python cad/src/model.py --check`); all pass. STEP and STL regenerated in `cad/step/` and `cad/stl/`.
- `docs/decisions/0003-design-for-construction.md` (CBC-DDR-003 v0.1, Draft): every change below, with the reason; made under Amish's 2026-09-30 instruction to make the design physically buildable; open for his review.
- `cad/src/build_plan_media.py` (new): overview, 16 making sketches (`cad/drawings/CBC-DWG-101` to `116`, SVG, PDF, PNG), three hole layouts, 13 joint close-ups, 17 assembly step pictures and a wiring diagram, all in `docs/05-build-plan/`.
- `docs/05-build-plan.md` (CBC-BLD-001 v0.1): the illustrated prototype build plan, components in build order, no open decisions.
- `docs/06-design-decisions.md` (CBC-DEC-001 v0.1): the design decisions register.
- `bom/bom.csv` (14 lines, line 14 added) and `bom/bom-notes.md`; `docs/04-calcs/sizing.py` and `01-sizing.md` (CBC-CAL-001 v0.3); CBC-PRB-001 v0.6, CBC-PRC-001 v0.5, CBC-REQ-001 v0.5; `cad/src/sheets.py` and CBC-DWG-001 Rev P4; concept media re-rendered from the new model (blueprint CBC-DWG-010 Rev P4).
- `project.yaml`: `design_state: constructable`; the decision record, build plan, register, overview picture and picture script added to `trl_evidence`. `README.md`: links line and a "Building the prototype" section.

### Design changes made for construction (CBC-DDR-003)

1. **Saddle plates (enclosure and arm).** Flat plates on a round pole, held by bands drawn as rings, became 3 mm plates (160 x 300 and 160 x 250 mm) seated on two bent 90° V-saddles each, with the bands passing through slots in the plate and across its front. Fits 60 to 140 mm poles. The enclosure plate gets a 100 x 150 mm lightening window.
2. **FieldNode core.** The floating enclosure and internals became FieldNode's constructable core (FND-DDR-003): four lugs on M5 screws, internal plate on bosses, two-row bottom face, connector strip and rail fuses (BOM line 14). Port A takes the sensor cable through a 3.3 V load switch in place of FieldNode's port A boost converter.
3. **Arm joint.** "Welded or bolted" became two 40 x 40 x 4 mm angle brackets, four M6 bolts through the plate and two through the tube on crush spacers. Arm 498 mm (was 512 mm); reach unchanged.
4. **Sensor head.** A printed wedge pad with two M5 heat-set inserts hangs the head from the arm at its 7.5° tilt; an 8 mm inner ledge and a printed window frame clamp the film with four M3 screws; four standoffs carry the array; an M16 gland under the hood takes the cable. Arm axis 8.5 mm higher; window height and field of view unchanged.
5. **Pole-top mount.** The welded sleeve, cap and post, floating hinge plate and floating panel became an all-bolted mount: 128 x 3 mm sleeve, 100 mm, with three M8 rivet-nut set screws; 8 mm cap disc on radial screws; post on two lower clips with plugs and M8 cross bolts; 290 x 150 x 3 mm rail plate at 35° on two upper clips; panel bolted through its frame lip. Panel now centred over the post; top 5.43 m (was about 5.50 m).
6. **Cables.** The sensor cable (single-ended, 1.48 m route) and a new 1.5 m panel extension lead are tied to the pole over the bands, never under them; the sensor cable runs beside the arm into the head gland.
7. **Notice plate.** 2 mm plate (model had 1.5 mm) with four slots and two stainless ties.

### Key results (CBC-CAL-001 v0.3)

| Quantity | Before | After |
| --- | --- | --- |
| Mass on the pole (R11, 6 kg) | 4.44 kg | 5.26 kg, met on paper |
| Parts cost (R13, value-engineering target $275) | $253.00 | $274.00 estimated, within the target ($1.00 under) |
| Panel post factor; pole base moment | 38; 283 N·m | 55; 279 N·m |
| Twist factor of the bands | 3.2 | 3.3 |
| Constructability checks | none | 106 of 106 pass |

No requirement changed status: 0 not met, 3 at risk (R1, R2, R7), 7 met on paper, 1 met by design, 4 not verifiable at TRL 3.

### Proposed, awaiting Amish (in CBC-DEC-001)

1. Accept the design for construction (CBC-DDR-003). Recommendation: accept.
2. Still open from earlier sessions: first co-design partner and street; port pinout, port A supply and calibration jumper with FieldNode; the six appearance items of 2026-09-26 (item 6 superseded by the design for construction).

### Safety

- The build plan adds stops for the stub stand (5.3 kg at 2 m with the panel on top must not tip), for frames viewed only through the calibration jumper, and repeats the site installation stop (work at height beside traffic; 52 N at 5.3 m, 279 N·m at the pole base for the pole owner to check). FieldNode's cell stops apply in full.
- Cables now pass over the bands, so no band can crush a cable.

### Stale media (made on Amish's Mac, not regenerated here)

The photoreal renders (`media/render-*.png`), `media/card.png`, `media/social-preview.png` and the appearance model `cad/src/product_model.py` show the concept saddles, arm joint, head fixing, pole-top mount and panel position; they are stale and need re-rendering with `/render-product`.

### Recommended next step

Amish reviews CBC-DDR-003 and the register. TRL 4 (building and testing to the plan) stays on hold by his instruction.

## Session 2026-10-02: approved follow-ups carried out

Amish approved on 2026-10-02 that every follow-up action from the open-decision sign-off be carried out. Results for the 8 follow-ups listed above:

1. Decision 3, raise the pin order, supply module and service-header jumper with FieldNode: not done here, it lives in the FieldNode project (see Cross-repo actions).
2. Decision 3, BOM line 11 pin order: not done, it waits for FieldNode to agree the pin order; the "(to agree with FieldNode)" wording stays until then.
3. Decision 4, hero caption: done. The hero view note in `cad/src/product_model.py` now says the pole top is drawn 560 mm closer than installed (5.15 m).
4. Decision 5, notice plate height: done. `NOTICE_Z` is now the installed 2.6 m (taken from `notice_z` in `model.py`) and the context pole section starts below the plate.
5. Decision 6, notice wording: done in the appearance model, the BOM line 12 description and the notice plate making sketch and build plan: "No images are stored or sent; only counts leave the device".
6. Decision 7, head status light: done. Removed from the sensor head in the appearance model (the enclosure status light stays).
7. Decision 8, embossed plaque: done. A raised "COUNTS ONLY" plaque (pad 64 x 16 mm, 0.8 mm relief, letters 0.4 mm higher) is part of the head housing in `cad/src/model.py`, so it is in `cad/step` and `cad/stl` (the print file); BOM line 8 states it, no price change. A check for the relief was added; all 107 constructability checks pass.
8. Decision 9, appearance model: done for the model. The bezel is replaced by the printed window frame (110 x 90 x 3 mm, film under it) with four M3 screws, and the head bolts are the two M5 bolts at the model's positions. Photoreal renders, `media/card.png` and `media/social-preview.png` are made on Amish's Mac and are not done here. The render scenes are exported to `/home/claude/renders/curbcount`.

Requirement status changes: none. Cost stays USD 274.00 against `budget_usd` 275 and mass 5.26 kg (the plaque adds about 1 g); `results.csv` is unchanged.

Pictures regenerated: general arrangement CBC-DWG-001 (Rev P5), all making sketches CBC-DWG-101 to 116 (dated 2026-10-02; 107 shows the plaque, 116 the notice wording) and the concept media. `drawing.py --check-text` reports no hits. Build plan joint and step pictures are unchanged because the plaque is 1.2 mm relief on a face none of them shows.

Documents changed: CBC-BLD-001 v0.4, CBC-DEC-001 v0.4, `bom/bom.csv`, `cad/src/model.py`, `cad/src/product_model.py`.

### Cross-repo actions

- FieldNode: publish the common pin order (supply, ground, I2C data, I2C clock, spare), per-project port supply modules (switched 3.3 V on port A for CurbCount, 5 V on port A for AirStreet) and the calibration jumper on the service header, so FND-DDR-001 O2 can be decided there. Then CurbCount BOM line 11 states the agreed pin order.

## 2026-10-02: photoreal renders redone on the constructable design

Rendered with Blender Cycles on Amish's Mac from the updated appearance model; captioned with `.kit/photo_caption.py`; `media/card.png` and `media/social-preview.png` regenerated with `.kit/cards.py`. Views: hero, exploded, detail. image_qc passes. Appearance deviations are those logged above as proposed, awaiting Amish.

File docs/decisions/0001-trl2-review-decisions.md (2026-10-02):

---
doc_id: CBC-DDR-001
title: CurbCount TRL 2 review decisions
project: CurbCount
doc_type: Design decision record
version: "0.3"
status: Draft
date: '2026-10-02'
author: Amish Chadha
license: CERN-OHL-S-2.0
revisions:
- version: "0.1"
  date: '2026-09-25'
  author: Amish Chadha
  change: Record the TRL 2 review items adopted as recommended for TRL 3 under Amish's 2026-09-25 instruction, and the items that remain open
- version: "0.2"
  date: '2026-09-25'
  author: Amish Chadha
  change: Recommendations accepted by Amish (DDR-002)
- version: "0.3"
  date: '2026-10-02'
  author: Amish Chadha
  change: "O1 decided by Amish on 2026-10-02 (CBC-DEC-001, item 2)"
---

# 0001: TRL 2 review decisions

- **Date:** 2026-09-25
- **Status:** accepted (v0.2). On 2026-09-25 Amish wrote "i accept all your recommendations, go with them across all repos." Items D1 to D7 and O2 are now decided as recommended; O1 had no recommendation and remains "Proposed, awaiting Amish". CBC-DDR-002 records what changed in the repo. O1 was decided by Amish on 2026-10-02 as recommended in the design decisions register (CBC-DEC-001, item 2): "i approve your recommendations for all 555 open decisions."

## Context

The TRL 2 review note (`docs/REVIEW.md`, session 2026-09-25, /populate) listed eight items as "Proposed, awaiting Amish", each with options and, for seven of them, a recommendation. On 2026-09-25 Amish asked for this batch of repos to be taken through the usual process with the instruction "you know the drill, nothing gets past TRL 3". He has not reviewed the CurbCount items one by one. Every item that carries a recommendation is therefore adopted as recommended for TRL 3 under Amish's 2026-09-25 instruction, open for his review. Items without a recommendation stay open. No item is recorded as decided or approved by Amish.

## Options considered

The options for each item are those listed in `docs/REVIEW.md` (session 2026-09-25, /populate) and in CBC-PRC-001 v0.2, Key design choices.

## Decision

*Table 1. Items decided (adopted for TRL 3 in v0.1, decided by Amish in v0.2).*

| # | Item | Recommendation adopted | Status |
| --- | --- | --- | --- |
| D1 | Budget | Option (a): raise `budget_usd` to $275. Applied in v0.2: `budget_usd` is now $275 (see O2 and CBC-DDR-002). | Decided by Amish, 2026-09-25: go with recommendation |
| D2 | Sensor | Option A, the 32 x 24 thermal array, for the first build; 60 GHz mmWave radar studied as a hot-climate variant. | Decided by Amish, 2026-09-25: go with recommendation |
| D3 | Power | A FieldNode "high-load" variant (20 W panel, second 6 Ah cell), raised with the FieldNode project rather than changing FieldNode here. Since CBC-DDR-002 it applies only to the ESP32-S3 fallback; the baseline uses standard FieldNode power. | Decided by Amish, 2026-09-25: go with recommendation |
| D4 | Processor | ESP32-S3 in the sensor head first; tracking on FieldNode's STM32WL alone studied at TRL 3 (CBC-CAL-001, section F). The study was done, and CBC-DDR-002 makes the STM32WL the baseline, with the ESP32-S3 as fallback. | Decided by Amish, 2026-09-25: go with recommendation |
| D5 | Count interval and classes | 15-minute bins; three classes (pedestrian, cyclist or micromobility, motor vehicle), each by two directions. | Decided by Amish, 2026-09-25: go with recommendation |
| D6 | Calibration mode | Frames may be shown on a laptop only through a physical jumper in the sensor head, never over the radio. | Decided by Amish, 2026-09-25: go with recommendation |
| D7 | Public notice | A notice plate on each pole saying what is counted and linking to this repository (BOM line 13). | Decided by Amish, 2026-09-25: go with recommendation |

*Table 2. Items that were open in v0.1.*

| # | Item | Status |
| --- | --- | --- |
| O1 | First co-design partner and street (city transport department, residents' group or university). No recommendation was made. | Decided by Amish, 2026-10-02 (CBC-DEC-001, item 2): a city transport department that already runs manual or loop counts on a street with a bike lane and 60 to 140 mm poles, first trial in a season with air under 20 °C; first candidate to approach, the City of Toronto's transportation services. Nothing is agreed with any partner. |
| O2 | The budget figure (D1). The TRL 3 review recommended option (b): $275 with the STM32WL-only design (about $253). `budget_usd` is now $275. | Decided by Amish, 2026-09-25: go with recommendation |

No reworded pitch or problem line was recommended at TRL 2, so `project.yaml` and `README.md` keep the existing wording.

## Consequences

- CBC-PRB-001, CBC-PRC-001 and CBC-REQ-001 move to v0.3. The design choices above are described as "adopted for TRL 3, open for Amish's review" instead of "proposed". The street design case in CBC-REQ-001 now uses a 2.0 m bike lane, to match the R6 target.
- CBC-CAL-001 led to three design changes within these decisions, all at massing level and all open for Amish's review: (1) the thermal array is turned 90 degrees so that its 110 degree axis spans the street, with the view tilted 7.5 degrees toward the road instead of 10 degrees, which makes R6 (coverage) met on paper; (2) the panel mount becomes aluminium and the saddle plates thinner, because the steel mount alone came to 5.7 kg; (3) the FieldNode enclosure takes its TRL 3 size (150 x 90 x 200 mm) and a CurbCount saddle plate, since FieldNode's V-block kit seats only 40 to 60 mm poles.
- CBC-CAL-001 shows that R13 (cost) is not met even against the recommended $275 ($290.00), that R7 (counting in hot weather) is not met on paper, and that R4 is not met as written although its privacy aim is. The follow-up proposals are in `docs/REVIEW.md` and await Amish; this record does not decide them.
- v0.2: the three CBC-CAL-001 design changes above, and the follow-up proposals from the TRL 3 review, were accepted by Amish on 2026-09-25 with the rest of the recommendations; see CBC-DDR-002.
- TRL 4 is on hold by Amish's instruction. Nothing in this record authorizes building or testing.

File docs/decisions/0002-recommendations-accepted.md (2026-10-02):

---
doc_id: CBC-DDR-002
title: CurbCount recommendations accepted
project: CurbCount
doc_type: Design decision record
version: "0.2"
status: Draft
date: '2026-10-02'
author: Amish Chadha
license: CERN-OHL-S-2.0
revisions:
- version: "0.1"
  date: '2026-09-25'
  author: Amish Chadha
  change: Record the recommendations accepted by Amish on 2026-09-25 and what changed in the repo
- version: "0.2"
  date: '2026-10-02'
  author: Amish Chadha
  change: "O1 decided by Amish on 2026-10-02 (CBC-DEC-001, item 2)"
---

# 0002: Recommendations accepted

- **Date:** 2026-09-25
- **Status:** accepted. Amish accepted every recommendation in `docs/REVIEW.md` and CBC-DDR-001 on 2026-09-25. Items with no recommendation stayed open at this record; O1 was decided by Amish on 2026-10-02 (CBC-DEC-001, item 2): "i approve your recommendations for all 555 open decisions."

## Context

The TRL 2 and TRL 3 review notes (`docs/REVIEW.md`, both sessions of 2026-09-25) and CBC-DDR-001 left items marked "Proposed, awaiting Amish" or "Adopted as recommended for TRL 3 under Amish's 2026-09-25 instruction, open for his review". On 2026-09-25 Amish wrote: "i accept all your recommendations, go with them across all repos." Every item that carried a recommendation is therefore decided as recommended; where a recommendation named one of several options, that option is the decision. TRL 4 remains on hold by Amish's instruction, and the repo stays at `trl: 3`.

## Options considered

The options for each item are those listed in `docs/REVIEW.md` and CBC-DDR-001. They are not repeated here.

## Decision

*Table 1. Items decided by Amish, 2026-09-25: go with recommendation.*

| # | Item (source) | Decision | What changed in the repo |
| --- | --- | --- | --- |
| 1 | D1 to D7 (CBC-DDR-001) | Decided as recommended: $275 budget, thermal array first with radar as hot-climate variant, FieldNode high-load variant raised with FieldNode, ESP32-S3 first with the STM32WL study, 15-minute bins and three classes, jumper-only calibration, public notice plate | CBC-DDR-001 v0.2 statuses updated; D3 and D4 are refined by items 3 and 4 below |
| 2 | Three CBC-CAL-001 v0.1 design changes (REVIEW, TRL 3): array turned 90 degrees, aluminium pole-top mount, FieldNode TRL 3 enclosure on a CurbCount saddle | Decided as made | No further change |
| 3 | O2 and REVIEW TRL 3 item 2, budget | Option (b): $275 with the STM32WL-only design | `budget_usd` $150 to $275 in `project.yaml`; R13 target $150 to $275 (budget); BOM $290.00 to $253.00, R13 not met to met on paper |
| 4 | REVIEW TRL 3 item 3, move tracking to the STM32WL | Baseline for the first build; ESP32-S3 head as fallback | BOM line 11 (ESP32-S3, $12) removed and lines 12 to 14 renumbered 11 to 13; one cell instead of two ($9 off); FieldNode's 6 W panel ($14) instead of the 20 W panel ($30); pole-top mount hinge plate 140 x 180 to 140 x 160 mm; `cad/src/model.py` (no processor part, one cell, 290 x 200 x 17 mm panel), STEP and STL re-exported; CBC-DWG-001 Rev P1 to P2; concept media re-rendered (blueprint CBC-DWG-010 Rev P2 to P3); head load 241 to 92 mW, draw 6.43 to 2.47 Wh/day, autonomy 4.78 days on two cells to 6.22 days on one |
| 5 | REVIEW TRL 3 item 4, R7 and the sensor for hot climates | Option (a) now: the thermal build is for temperate sites, stated in R7; option (b), bring the radar variant forward, applies to any hot partner city | R7 restated (survive -20 to +50 °C; count at temperate sites, air up to 20 °C; hot sites use radar); status not met to at risk. Radar design work waits for a partner city (O1) |
| 6 | REVIEW TRL 3 item 5, restate R4 | Adopt: 8 px/m or less at head height, below the IEC 62676-4 detection level of 25 px/m | R4 restated; not met as written (0.22 m ground pixel against 0.25 m) to met on paper (7.6 px/m for a 1.75 m person; 8.5 px/m for a 2.0 m person) |
| 7 | REVIEW TRL 3 item 6, R11 mass | Keep 6 kg and meet it through item 4 | R11 unchanged at 6 kg; mass 6.02 to 4.44 kg, at risk to met on paper |
| 8 | REVIEW TRL 3 item 7, payload | Pack the record into 10 bytes (six 12-bit counters and a status byte) | R5 target states the 10-byte record; payload 14 to 10 bytes; SF9 uplink 226 to 206 ms; US915 DR0 uplink fits (371 ms, 10 of 11 bytes); R15 at risk to met on paper |
| 9 | REVIEW TRL 3 item 8, raise with FieldNode | Decided; recorded as cross-repo actions in `docs/REVIEW.md`, FieldNode not edited | None in this repo |

Pitch and problem: no rewording was recommended, so `project.yaml` and `README.md` keep the existing pitch and problem lines.

*Table 2. Items still open.*

| # | Item | Status |
| --- | --- | --- |
| O1 | First co-design partner and street (city transport department, residents' group or university). No recommendation was made. | Decided by Amish, 2026-10-02 (CBC-DEC-001, item 2): a city transport department that already runs manual or loop counts on a street with a bike lane and 60 to 140 mm poles, first trial in a season with air under 20 °C; first candidate to approach, the City of Toronto's transportation services. Nothing is agreed with any partner. |

The side-arm panel mount for poles with a lantern on top was a suggestion, not a recommendation, and is not applied.

## Consequences

- Controlled documents revised: CBC-PRB-001 v0.4, CBC-PRC-001 v0.4, CBC-REQ-001 v0.4, CBC-CAL-001 v0.2, CBC-DDR-001 v0.2; CBC-DWG-001 Rev P2.
- Requirement status (CBC-CAL-001 v0.2): 0 not met (was 3), 3 at risk (R1, R2, R7), 4 not verifiable at TRL 3, 7 met on paper, 1 met by design.
- Pole loading from the panel falls from 170 N to 52 N at 35 m/s, and the moment at the pole base from 933 N·m to 283 N·m.
- The calibration jumper (DDR-001 D6) moves from the head to FieldNode's service header, because the head no longer has a processor.
- Deferred as TRL 4 work, on hold by Amish's instruction: profiling the fixed-point tracker on the STM32WL, I²C over the 2 m cable on a pole, window and array noise measurements, and any radar build. None has been started.

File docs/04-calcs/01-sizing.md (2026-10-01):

---
doc_id: CBC-CAL-001
title: CurbCount sizing calculations
project: CurbCount
doc_type: Calculation
version: "0.4"
status: Draft
date: '2026-10-01'
author: Amish Chadha
license: CERN-OHL-S-2.0
revisions:
- version: "0.1"
  date: '2026-09-25'
  author: Amish Chadha
  change: First issue for TRL 3 (coverage, pixel size and privacy, frames per crossing, merging, thermal contrast and window, energy, processor study, radio, wind and mounting, mass, installation, service life, cost)
- version: "0.2"
  date: '2026-09-25'
  author: Amish Chadha
  change: Recommendations accepted by Amish (DDR-002)
- version: "0.3"
  date: '2026-09-30'
  author: Amish Chadha
  change: Design for construction (CBC-DDR-003); wind, arm, mass, installation and cost figures recalculated from the constructable model; no requirement changed status
- version: "0.4"
  date: '2026-10-01'
  author: Amish Chadha
  change: Budget treated as a value-engineering target
---

# CurbCount sizing calculations

With the decisions Amish accepted on 2026-09-25 (CBC-DDR-002) applied, CurbCount meets eight of its fifteen requirements on paper (seven by calculation, one by design), has three at risk, cannot show four at TRL 3 and misses none. The largest change is where the tracking runs: it moves from a separate ESP32-S3 in the sensor head to FieldNode's STM32WL, in fixed point. That cuts the head load from 241 mW to 92 mW, so the counter runs on standard FieldNode power (one cell and the 6 W panel) and still counts for 6.2 days without sun; parts fall from $290.00 to $253.00 against the new $275 value-engineering target; and the mass falls from 6.02 kg to 4.44 kg. Version 0.3 recalculates the mounting, mass and cost figures for the constructable design of CBC-DDR-003 (saddles, brackets, a bolted pole-top mount and their fixings): the counter now weighs 5.26 kg and costs $274.00, and no requirement changes status. The record is packed into 10 bytes so it fits US915 DR0; R4 is restated in pixels per meter at head height, which the sensor meets at 7.6 px/m; and R7 is restated for temperate sites, where it remains at risk because sunlit sidewalks need track averaging. The three at-risk requirements are R1 (4.2 frames for a car at 50 km/h), R2 (merging) and R7. Every number in this note is printed by `docs/04-calcs/sizing.py`; the tag in brackets, for example [E2], is the line of that script's output that carries it.

> **Safety:** These are first-principles estimates for a paper proof of concept. They do not show that the mount is safe on a particular pole, that the cell is safe in a particular climate or that the device complies with data protection law where it is installed. Pole loading must be checked by the pole owner. See CBC-PRC-001, Safety.

## Scope and method

The note checks every requirement in CBC-REQ-001 v0.4 against the design in CBC-PRC-001 v0.4 and the parametric model `cad/src/model.py`. The script imports the model's `PARAMS`, `derived()` and its camera model, so the head height, tilt, arm, enclosure, panel and footprint used here are those in the STEP files, in drawing CBC-DWG-001 and in the concept media. It also reads `bom/bom.csv` and `budget_usd` in `project.yaml`, and writes `docs/04-calcs/results.csv`. Run it from the repo root with `python docs/04-calcs/sizing.py`.

The design case is one counter on a 114 mm street pole 0.45 m behind the curb, the sensor window 4.3 m above the road, a 3 m sidewalk (0.15 m above the road), a 2.0 m bike lane and one 3.5 m traffic lane.

Changes from v0.1: the baseline processor is the STM32WL (the ESP32-S3 head is a fallback on paper); one cell and FieldNode's 6 W panel replace two cells and a 20 W panel; the payload is 10 bytes; R4, R7 and R13 are checked against their restated targets; `budget_usd`, the value-engineering target, is $275.

## Assumptions

*Table 1. Main assumptions.*

| Area | Assumption | Basis |
| --- | --- | --- |
| Lens | Separable equiangular model: 110 / 32 = 3.44 degrees per pixel across, 75 / 24 = 3.13 degrees along; flat ground; the sidewalk 150 mm above the road | Simplification of the MLX90640 wide lens; real distortion to be measured |
| Sensor | 16 Hz chess-mode subpages, so 8 full frames a second; noise 0.10 K rms at 1 Hz, scaling with the square root of the rate, times 1.25 at the lens edge; 23 mA at 3.3 V | Typical MLX90640 class values, to confirm from the datasheet of the chosen part |
| Detection | Single-frame threshold 4 times the noise; a person's plan area 0.099 m² (0.45 x 0.28 m ellipse); half the signal in the brightest pixel; a track needs 4 frames for class and direction | Engineering judgment |
| Window | 0.5 mm HDPE, refractive index 1.53, band-averaged absorption 4 /cm over 8 to 14 µm | Assumption, to be measured |
| Surface temperatures | Air as a daily cosine (minimum 03:00, maximum 15:00); sunlit concrete 3 K above air at night plus up to 15 K in sun; shaded concrete 1 K above air; a person seen from above halfway between air and 34 °C, plus up to 5 K in sun | Screening model; the largest uncertainty in this note |
| Speeds and flows | Walking 1.25 m/s mean, 1.5 m/s maximum; cyclists 25 km/h; cars 50 km/h; 600 people per hour per direction | CBC-REQ-001 Table 2 |
| Electronics | STM32WL run mode 5 mA at 3.3 V for tracking (baseline); ESP32-S3 50 mA at 3.3 V (fallback only); rails 90 % efficient; FieldNode core 4.0 mWh/day | Typical values; FND-CAL-001 [A1] |
| Energy | One 3.2 V 6 Ah LiFePO4 cell, 80 % usable, 70 % at -20 °C, 80 % at end of life; FieldNode's 6 W panel; winter 1.5 peak sun hours with 40 % derating for street shade, dust and heat; charger 85 %, charging 95 % | CBC-REQ-001 R8 and R9; FieldNode efficiencies |
| Radio | 10-byte payload (six 12-bit counters and a status byte) plus 13 bytes of LoRaWAN overhead, 125 kHz, coding rate 4/5, 8-symbol preamble, 96 uplinks a day | As FND-CAL-001; payload per CBC-DDR-002 |
| Wind and mounting | 35 m/s gust, 1.225 kg/m³; force coefficients 1.2 (panel), 1.3 (boxes), 2.0 (square tube); band preload 1,000 N, friction 0.2 (as FND-CAL-001); 6063 aluminium, yield 150 MPa | Screening values, not a code check |
| Masses | FieldNode core 1.02 kg (FND-CAL-001 [F1] less its panel, bracket and mount); 6 W panel 0.55 kg (FND-CAL-001); made parts from model volumes | Typical catalog masses |

## A. Coverage (R6)

- **Orientation.** The TRL 2 concept put the 75 degree axis across the street, tilted 10 degrees. That covers the sidewalk only to 2.08 m behind the curb, 69 % of the 3 m sidewalk [A4]. The design case spans 36.6 degrees behind and 51.6 degrees ahead of the vertical, 88.2 degrees in all [A3], which only the 110 degree axis can reach.
- **Chosen layout.** With the array turned 90 degrees and the view tilted 7.5 degrees toward the road, the footprint runs from 4.45 m behind the curb to 8.34 m into the road, 12.79 m across [A2], with 10.9 degrees of margin at both edges [A3]. Along the street it covers 5.71 m at the sidewalk back to 7.28 m at mid lane [A5]. The far part of the road is masked in firmware; only the nearest lane is counted.
- **Shadow.** The pole and the enclosure hide a strip up to 0.73 m wide at the back of the sidewalk, 13 % of the field along the street there [A6]. The tracker must join tracks across it.

R6 is **met on paper**.

## B. Pixel size and privacy (R4)

- **Ground pixel.** Below the head a pixel covers 0.251 x 0.233 m; at the curb edge of the sidewalk 0.251 x 0.224 m; at the back of the sidewalk 0.376 x 0.203 m; at mid lane 0.442 x 0.259 m [B1]. The smallest is 0.224 m, along the street near the head [B1b]. This was the v0.1 measure of R4 and is no longer the requirement.
- **What the sensor can resolve.** Privacy depends on resolution at the subject, not on the ground. A 1.75 m person directly below is 2.40 m from the sensor and is imaged at 7.6 px/m; a 2.0 m person at 8.5 px/m [B2]. The IEC 62676-4 levels for video surveillance are 25 px/m to detect, 125 px/m to recognize and 250 px/m to identify a person (values quoted from the standard, not checked online). A number plate at mid lane spans 1.8 pixels [B3].

R4, restated by CBC-DDR-002 as 8 px/m or less at head height for the 1.75 m design person, is **met on paper** at 7.6 px/m. A 2.0 m person is imaged at 8.5 px/m, still a third of the detection level and about 30 times below identification.

## C. Counting (R1, R2, R3)

*Table 2. Frames per crossing at 8 frames per second [C1].*

| Road user | Field along the street | Speed | Time in view | Frames |
| --- | --- | --- | --- | --- |
| Pedestrian, sidewalk back | 5.71 m | 5 km/h | 3.80 s | 30.4 |
| Pedestrian, mid-sidewalk | 6.00 m | 5 km/h | 4.00 s | 32.0 |
| Cyclist, mid bike lane | 6.73 m | 25 km/h | 0.97 s | 7.7 |
| Car, mid lane | 7.28 m | 50 km/h | 0.52 s | 4.2 |

- **R1.** A car at 50 km/h gives 4.2 frames, just above the 4 assumed necessary; above 52 km/h it gives fewer [C2]. Turning the array halved the frames for cars. R1 is **at risk** for fast vehicles.
- **Smear.** At 50 km/h a car moves 0.87 m (3.4 pixels) during one 62.5 ms subpage [C2], which distorts its blob in the chess readout. R3 (vehicle accuracy) is **not verifiable at TRL 3**.
- **Merging (R2).** At 600 people per hour per direction, random arrivals alone put a following walker within 0.50 m of another for 6.5 % of people [C3]; each such merge loses a count. People walking side by side add to this unless the tracker splits blobs by area. R2 is **at risk** and not verifiable at TRL 3.

## D. Thermal contrast and window (R7)

- **Window.** A 0.5 mm HDPE film passes about 0.75 of the long-wave signal; 0.25 mm passes 0.83 and 1.0 mm 0.61 [D1]. The thinner film helps little and is more fragile.
- **Threshold.** With 0.50 K rms of noise per pixel at the lens edge and half the person's signal in one pixel, a single frame needs at least 5.3 K between a person and the pavement [D2, D3]. Averaging 8 frames along a track could lower this to about 1.9 K [D3], but only if the tracker can follow a target it cannot yet see in one frame.

*Table 3. Hours a day with pedestrian contrast below the threshold [D4].*

| Design day | Sunlit sidewalk, 5.3 K | Shaded sidewalk, 5.3 K | Sunlit, 1.9 K with track averaging |
| --- | --- | --- | --- |
| Hot, air 25 to 35 °C | 14.2 h | 24.0 h | 11.2 h |
| Mild, air 10 to 20 °C | 10.2 h | 0.0 h | 3.2 h |
| Cold, air -10 to 0 °C | 3.2 h | 0.0 h | 0.0 h |

On a hot day a clothed person is within a few kelvin of the pavement at night and all day in shade, so a thermal-only counter goes blind for much of the day. On sunlit pavement the contrast crosses zero as the pavement heats, and the model puts that crossing band at several hours even on mild days. The surface temperature model is crude and these hours are the least certain figures in the note, but the conclusion for hot weather holds across the assumptions tried. Under Amish's decision of 2026-09-25 (CBC-DDR-002), R7 is restated: the thermal build is for temperate sites, taken here as design days with air up to 20 °C, and hot-climate sites use the radar variant. On the mild design day a shaded sidewalk never drops below the threshold, but a sunlit one does for 10.2 h with single frames and 3.2 h if track averaging reaches 1.9 K [D5]. The restated R7 is therefore **at risk**: it depends on track averaging that can only be shown on a bench at TRL 4. The hot-day figures stand as the reason for the scope limit. The electronics temperature part of R7 inherits FieldNode's R2 and R3 (see section E).

## E. Energy (R8, R9)

- **Load.** With tracking on the STM32WL, the head carries only the array: 76 mW, plus 16.5 mW for the STM32WL running the tracker, 92 mW delivered. With 90 % rail efficiency and the FieldNode core, the counter takes 2.47 Wh/day from the cell, 103 mW on average, 92 % of FieldNode's proposed 100 mW sensor allowance [E1]. The ESP32-S3 fallback would draw 241 mW and 6.43 Wh/day, 2.1 times FieldNode's current 115 mW allowance [E1b].
- **Autonomy (R8).** One cell holds 19.2 Wh, 15.4 Wh usable: 6.22 days without sun, 4.36 days at -20 °C and 4.98 days at end of life [E2]. R8 (3 days) is **met on paper** with one cell.
- **Winter harvest (R9).** *Table 4. Panel size in the winter design case [E3].*

| Panel | Stored per day | Ratio to 2.47 Wh drawn | Refill after 3 sunless days |
| --- | --- | --- | --- |
| 6 W (FieldNode standard) | 4.4 Wh | 1.77 | 3.9 days |
| 10 W | 7.3 Wh | 2.94 | 1.5 days |
| 20 W | 14.5 Wh | 5.89 | 0.6 days |

  The smallest energy-neutral panel is 3.4 W; the fallback would need 8.8 W, which is why v0.1 used a 20 W panel [E4]. R9 is **met on paper** with FieldNode's 6 W panel.
- **Charger.** At full sun the 6 W panel pushes 1.5 A into the cell (0.25 C), FieldNode's standard setting; the 20 W panel of the fallback would push 5.0 A [E5]. The baseline needs no charger change in FieldNode.
- **Heat.** FieldNode's calculation shows that on a hot clear day its cell sits above the 45 °C charge limit for most of the sun hours. With FieldNode's 6 W figures, CurbCount would store 0.8 Wh against 2.47 Wh drawn without a sun shield and run flat after 9.2 days of such weather; with FieldNode's proposed shield it stores 13.1 Wh [E6]. The CurbCount enclosure is not under its panel, so these shares are probably optimistic; the thermal build is for temperate sites in any case (R7).

## F. Tracking on the STM32WL (baseline, CBC-DDR-002)

- **Bus.** Reading one subpage takes 37.6 ms at 400 kHz I²C (60 % of the bus at 16 Hz) or 15.0 ms at 1 MHz (24 %) [F1]. Over the 2 m M12 cable (about 220 pF) the pull-ups must be 1.6 kΩ or less at 400 kHz and 644 Ω or less at 1 MHz, sinking 2.1 and 5.1 mA [F2]. Both fit I²C limits on paper; noise pickup on a cable up a street pole is a TRL 4 question.
- **Compute.** The STM32WL's Cortex-M4 core runs at 48 MHz and is taken here as having no floating-point unit (to confirm). The reference temperature conversion, at an estimated 2,000 to 4,000 cycles a pixel in software, would take 26 to 51 % of the core at 8 frames a second; a fixed-point pipeline on the raw data, at about 150 cycles a pixel, takes 2 % [F3]. RAM is estimated at 44 kB of 64 kB, most of it the LoRaWAN stack [F4].
- **Change from v0.1.** Head load 241 to 92 mW, draw 6.43 to 2.47 Wh/day, two cells and a 20 W panel to one cell and 6 W [F5].

The STM32WL baseline is feasible on paper only if the tracker is written in fixed point. The ESP32-S3 head on the high-load power variant stays as the fallback if bench profiling (TRL 4, on hold) shows otherwise. The calibration jumper moves from the head to FieldNode's service header, so frames can still reach a laptop only through a physical link (DDR-001 D6).

## G. Radio and data (R5, R15)

- **Airtime.** A 10-byte uplink takes 61.7 ms at SF7, 205.8 ms at SF9, 370.7 ms at SF10 and 1,482.8 ms at SF12. At SF9 that is 19.8 s a day and 0.82 s an hour, against 36 s an hour for the EU868 1 % duty cycle and 30 s a day for The Things Network's fair use; at SF10 and slower the fair-use limit is exceeded [G1].
- **US915.** At SF9 an uplink takes 206 ms against the 400 ms dwell limit. At DR0 (SF10) the payload limit is 11 bytes; the 10-byte record takes 371 ms there, within both limits, where the 14-byte v0.1 record could not be sent at all [G2].
- **Data.** 96 records of 10 bytes are 0.96 kB a day; the frames, 12.3 kB/s or 1.06 GB a day, stay in RAM [G3].

R5 is **met by design** and R15 is **met on paper**.

## H. Wind, mounting and mass (R11, R12)

- **Panel.** A 35 m/s gust gives 750 Pa and 52 N normal to the 6 W panel. The panel now sits centred over the post on its rail plate (CBC-DDR-003), so the lever to the post base is 0.180 m (0.256 m in v0.2) and the moment 9 N·m, which stresses the 42.4 x 3.0 mm aluminium post to 3 MPa (factor 55 on yield) [H1]. The 100 mm sleeve bears on the pole top with about 169 N. The pole itself carries the 52 N at 5.3 m, 279 N·m at its base, which the pole owner must check [H2]. The v0.1 figures with the 20 W panel were 170 N and 933 N·m.
- **Arm.** The arm is now 498 mm long, butted to its saddle plate. Wind along the street loads the arm with 30 N and the head with 8 N, twisting the arm about the pole by 14.0 N·m against 45.7 N·m of saddle friction from two bands (factor 3.3) [H3]. The arm bends to 3.1 MPa and its tip moves 0.16 mm, 0.018 degrees of aim [H4].
- **Mass (R11).** Masses of made parts come from the volumes of the constructable model. The FieldNode core is 1.04 kg with its connector strip; made parts are the arm with its saddle plate, V-saddles and brackets 0.89 kg, the pole-top mount 1.29 kg, the enclosure saddle plate with its V-saddles 0.36 kg, the printed head with its wedge pad and window frame 0.26 kg and the notice plate 0.16 kg; bought parts add 1.26 kg, 0.55 kg of it the panel. The total is 5.26 kg (4.44 kg in v0.2, before the saddles, brackets, clips, plugs and fixings were added); the ESP32-S3 fallback would be about 6.81 kg [H5]. R11 (6 kg) is **met on paper**, kept at 6 kg as Amish decided.
- **Installation (R12).** The task list comes to 59 min for two people with a mobile platform [H6], at the 60 min limit. Wind and fit are met on paper, but the time is **not verifiable at TRL 3**. The pole-top mount fits only poles with a free top.

## I. Sealing and service life (R10, R14)

- A winter night of 16 h discharges the cell by 9 %, and five years is 1,825 such cycles [I1], well within LiFePO4 cycle life at that depth. Calendar ageing in hot enclosures (see FND-CAL-001) and ultraviolet ageing of the HDPE window are unknown. R14 is **not verifiable at TRL 3**.
- The FieldNode enclosure is IP65 by design and the head's film window is clamped to a ledge by a printed frame; R10 is **not verifiable at TRL 3**.

## J. Cost (R13)

The BOM has 14 lines, all priced; the estimated total is $274.00 against the $275 value-engineering target (`budget_usd`, a hypothetical control target, not a limit), $1.00 under [J1] ($253.00 in v0.2). The rise comes from the parts added for construction (CBC-DDR-003) and from FieldNode's repricing of its core, which now includes the connector strip: the FieldNode share (lines 1 to 3, 14 and part of 13) is $105.00, and line 4 is FieldNode's own $14 panel. The ESP32-S3 fallback would cost about $311.00, over the target [J2]. R13 is **within the value-engineering target**, by a thin margin that rests on indicative prices (cost drivers and savings are in CBC-DEC-001).
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

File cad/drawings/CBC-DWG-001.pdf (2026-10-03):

CONCEPT, NOT FOR FABRICATION | CurbCount · github.com/BoujeeEnjinia1701/curbcount

FRONT VIEW
Scale 1:20; looking at the front (along +Y)

TOP VIEW
Scale 1:20; looking down (along -Z)

RIGHT VIEW
Scale 1:20; looking at the right side (along -X)

777

200 1928

PRELIMINARY, NOT FOR FABRICATION

POLE CONTINUES TO SIDEWALK

200

553

530 reach

WINDOW 4300 ABOVE ROAD,
TILT 7.5 DEG

ARM AXIS 4,403 ABOVE ROAD

PANEL TOP 5,428 ABOVE ROAD

M12 PORTS, ANTENNA DOWN

200

ARRAY: 110 DEG ACROSS,
75 DEG ALONG THE STREET

ISOMETRIC VIEW
Not to scale; seen from the front right and above, about 30 deg elevation

MAIN DIMENSIONS AND INTERFACES (MM)
Pole 114.3 OD, 450 behind the curb (site supplied, not in BOM) Head 110 x 90 x 70, window 4300 above road, tilt 7.5 deg Arm 40 x 40 x 2 Al, 498 long; reach 530 from pole axis
FieldNode enclosure 150 x 90 x 200, center 3850
Panel 6 W (FieldNode) 290 x 200, tilt 35 deg on a 100 sleeve
Saddle plates on bent V-saddles; four 12 mm bands through slots; no drilling M12 5-pin cable, enclosure port to head (FieldNode pinout)
Footprint -4.4 to 8.3 m across the street (CBC-CAL-001)
Notice plate 150 x 200 at 2600 (not drawn); lanyards on panel and head
REV | DESCRIPTION | DATE | BY
P1 | Preliminary GA for TRL 3 (from cad/src/model.py) | 2026-09-25 | AC
P2 | DDR-002: 6 W panel, one cell, no head processor | 2026-09-25 | AC
P3 | Layout and labels tidied | 2026-09-25 | AC
P4 | DDR-003: design for construction (saddles, brackets, bolted mount) | 2026-09-30 | AC
P5 | Embossed COUNTS ONLY plaque on the head housing | 2026-10-02 | AC
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

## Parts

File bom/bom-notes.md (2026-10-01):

# BOM notes

Costs are indicative (September 2026 estimates) until suppliers are selected. Line numbers match the callouts in `media/exploded.png` and the part keys in `cad/src/model.py`; line 13 has no callout.

- Total parts cost is $274.00 (checked by `docs/04-calcs/sizing.py`, CBC-CAL-001 [J1]), against a `budget_usd` of $275 in `project.yaml`, set by Amish's decision of 2026-09-25 (CBC-DDR-002). The margin is $1.00, which rests on indicative prices (CBC-DEC-001).
- Baseline since CBC-DDR-002: tracking runs on FieldNode's STM32WL, so the separate ESP32-S3 edge processor (TRL 3 line 11, $12) is gone, and the counter runs on standard FieldNode power: one cell and FieldNode's 6 W panel ($14) in place of the second cell ($9) and the 20 W panel ($30). The saving is $37.00 against the $290.00 TRL 3 BOM.
- Lines 1, 2, 3, 14 and $6 of line 13 are the FieldNode core, $105.00, priced from the FieldNode constructable BOM (FND-DDR-003). Line 4 is FieldNode's own 6 W panel, mounted on CurbCount's pole-top mount (line 5).
- ESP32-S3 fallback (kept on paper only, CBC-DDR-002): add the processor ($12), a second cell ($9) and a 20 W panel ($30 in place of $14), about $311.00 in all, above the budget.
- Line 5 is aluminium and all bolted (CBC-DDR-003): sleeve with rivet-nut set screws, cap disc, post on angle clips with plugs, and a 290 x 150 x 3 mm rail plate that the panel bolts to through its frame lip.
- Line 13 includes the calibration jumper link: frames can be shown on a laptop only with the link fitted on the FieldNode service header, never over the radio (DDR-001 D6).
- The street pole is not part of the BOM.

- Design for construction (CBC-DDR-003, 2026-09-30): lines 1, 5, 6, 7, 8, 9, 11, 12 and 13 respecified for the constructable design; line 14 (plug-in connector strip and rail fuses, $5, FieldNode BOM line 15) added; line 1 repriced to FieldNode's $49 core. The total rose from $253.00 to $274.00.

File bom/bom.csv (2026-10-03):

item | qty | spec | supplier | unit_cost_usd | make_buy | notes
1 FieldNode enclosure with ports and antenna | 1 | FieldNode constructable core (FND-DDR-003): light grey polycarbonate enclosure 150 x 90 x 200 mm with gasketed lid, four moulded bosses inside the back wall and the maker's kit of four external lugs (IP65); bottom face drilled in two rows for two M16 glands, an M12 ePTFE vent, two M12 5-pin sensor ports and the sub-GHz whip antenna bulkhead; printed ASA internal plate 130 x 180 x 3 mm on the bosses (FieldNode BOM lines 1 to 3 and 9 to 11) | FieldNode project; enclosure from a Fibox, Hammond or Bud class maker via an electrical distributor; connectors from an industrial connector distributor | 49.00 | buy | Indicative; sum of the FieldNode BOM lines it replaces ($20 + $0 + $3 + $10 + $12 + $4); port A takes the sensor cable, port B and gland 2 are capped; lugs and two-row drilling from FND-DDR-003
2 FieldNode power and radio board | 1 | FieldNode power board (1S LiFePO4 MPPT charger with NTC lockout, protection, fuel gauge, switched rails) and STM32WL-class LoRaWAN controller (FieldNode BOM lines 7 and 8); standard 6 W charger setting; also runs the fixed-point tracker (CBC-DDR-002) | FieldNode project; ICs from an electronics distributor (DigiKey or Mouser class); module from RAKwireless or Seeed Studio | 36.00 | make | Indicative; FieldNode $22 + $14
3 LiFePO4 cell with fused holder | 1 | 32700 LiFePO4, 3.2 V, 6 Ah (about 19 Wh), charge 0 to 45 C; holder with 5 A fuse and 10 k NTC, as FieldNode BOM line 6 | Battery distributor (cell maker that publishes a datasheet) | 9.00 | buy | Indicative; FieldNode standard single cell (CBC-DDR-002; the second cell belongs to the ESP32-S3 fallback only)
4 Solar panel | 1 | 6 W monocrystalline, 9 V class (Vmp about 9 V at 25 C), about 290 x 200 x 17 mm, aluminium frame with a flat back lip at least 12 mm wide, with 1 m lead (FieldNode BOM line 4) | Solar or electronics distributor | 14.00 | buy | Indicative; FieldNode standard panel (CBC-DDR-002); bolted through its frame lip to the rail plate (CBC-DDR-003); extension lead in line 13
5 Panel pole-top mount | 1 | All bolted, no welding (CBC-DDR-003): aluminium sleeve, round tube about 128 mm outside x 3 mm wall (bore at least 122 mm), 100 mm long, with three M8 stainless rivet nuts and cup-point set screws; cap disc 8 mm aluminium plate, 122 mm diameter, on four M4 countersunk radial screws; post 42.4 x 3.0 mm tube 150 mm with a 36 mm round bar plug 40 mm long in each end; four post clips cut from 50 x 50 x 5 mm angle (two lower 35 mm long, two upper 35 mm long); rail plate 290 x 150 x 3 mm at 35 degrees with two lightening windows; four M8 cross bolts | Local fabricator from aluminium stockist tube and plate | 15.00 | make | Indicative material cost; fits poles with a free top only; redesigned for construction (CBC-DDR-003)
6 Band clamps and enclosure saddle | 1 | Set: four 12 mm stainless worm-drive band clamps (two for the enclosure, two for the arm), each closing on a loop of about 470 mm on a 114 mm pole (about 330 mm on a 60 mm pole, 545 mm on a 140 mm pole); enclosure saddle plate 160 x 300 x 3 mm aluminium with a 100 x 150 mm window and four band slots; two bent V-saddles of 3 mm aluminium sheet (20 mm flat, two 65 mm wings at 90 degrees, 40 mm tall) on M4 countersunk screws | Hardware supplier (bands) and local make (plate) | 18.00 | make | Indicative; V-saddles seat 60 to 140 mm poles on their faces; bands pass through slots in the plate (CBC-DDR-003)
7 Sensor arm with saddle | 1 | 40 x 40 x 2 mm 6063 aluminium square tube about 498 mm, butted to an arm saddle plate 160 x 250 x 3 mm aluminium with four band slots, held by two angle brackets cut from 40 x 40 x 4 mm angle (40 mm long) and two M6 through-bolts with crush spacers; two bent V-saddles as line 6; plastic end cap | Local make from metal stockist tube and plate | 16.00 | make | Indicative material cost; welded-or-bolted joint replaced by bolted brackets (CBC-DDR-003)
8 Sensor head housing | 1 | 3D-printed ASA housing 110 x 90 x 70 mm with 150 x 120 mm sun hood, window ledge, four corner bosses for M3 heat-set inserts, four standoffs for the array breakout, wedge pad for the arm with two M5 heat-set inserts and an M16 gland hole in the end wall; printed ASA window frame 110 x 90 x 3 mm; tilted 7.5 degrees toward the road; embossed "COUNTS ONLY" plaque (64 x 16 mm pad, 0.8 mm relief, letters 0.4 mm) on the road-side wall, printed with the housing | Local print (ASA filament from a 3D printing supplier) | 9.00 | make | Indicative material cost; UV-stable plastic; frame, wedge pad, standoffs and gland hole added for construction (CBC-DDR-003)
9 LWIR window | 1 | 0.5 mm HDPE film, 100 x 80 mm, unpigmented, with four 3.5 mm holes; clamped between the housing ledge and the window frame | Plastics supplier | 2.00 | buy | Indicative; transmission estimated at 0.75 in CBC-CAL-001 D1 and to be measured
10 Thermal array | 1 | MLX90640 class, 32 x 24 px, 110 x 75 degree lens (BAB type), on an I2C breakout; mounted with its 110 degree axis across the street | Electronics distributor or maker-board retailer (Adafruit or SparkFun class) | 65.00 | buy | Indicative; read over I2C by the FieldNode STM32WL (CBC-DDR-002); mmWave radar kept as the hot-climate variant (DDR-001 D2, DDR-002)
11 Sensor cable | 1 | M12 5-pin A-coded moulded cable, single-ended (plug one end, open wires the other), about 2 m, PUR, IP67, 6 mm; FieldNode sensor port pinout with I2C and 3.3 V (to agree with FieldNode); open end through the head's M16 gland to the array breakout | Industrial connector distributor | 10.00 | buy | Indicative; the modelled route from port A to the head gland is 1.48 m (CBC-DDR-003)
12 Public notice plate | 1 | Aluminium plate 150 x 200 x 2 mm with four tie slots, UV-stable print: what is counted, "No images are stored or sent; only counts leave the device", and a link to this repository; two stainless steel cable ties 8 mm wide | Local sign maker | 6.00 | buy | Indicative; public notice adopted for TRL 3 (DDR-001 D7); tied to the pole through slots (CBC-DDR-003)
13 Hardware and consumables | 1 | FieldNode hardware set (standoffs, screws, wire, ferrules, two blanking plugs, desiccant) plus stainless fasteners (M4 countersunk screws for the V-saddles and cap disc; M6 bolts and nuts for the arm brackets with two crush spacers; two M5 bolts and crush spacers for the head; four M3 screws and four M3 and two M5 heat-set inserts; four M8 bolts with nyloc nuts for the post clips; eight M5 screws for the clips; four M4 bolts for the panel lip), M16 gland for the head, panel extension lead 1.5 m (2 x 0.75 mm2 UV-rated with a sealed inline connector), two stainless wire-rope safety lanyards, UV-stable cable ties and tape; calibration jumper link for the FieldNode service header | Hardware shop | 20.00 | buy | Indicative; FieldNode $6 plus $14 for the mount fixings, gland, lead and lanyards; no exploded-view callout
14 Plug-in connector strip and rail fuses | 1 | Pluggable terminal block strip (5.08 mm pitch, plug and header, about 12 ways) on the internal plate, and two resettable fuses (about 0.5 A hold) on the switched sensor rails, as FieldNode BOM line 15 | Electronics distributor | 5.00 | buy | Indicative; part of the FieldNode constructable core (FND-DDR-003)

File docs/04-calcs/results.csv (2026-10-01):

id | value | target | status
R1 | 4.2 frames minimum (car at 50 km/h); at least 4 assumed needed | 3 classes x 2 directions | At risk
R2 | Random merges alone 6.5 % undercount at 600/h; groups extra | Within 10 % of manual counts per hour | At risk (not verifiable at TRL 3)
R3 | 4.2 frames per car; 3.4 px smear per subpage | Within 15 % of manual counts per hour | Not verifiable at TRL 3
R4 | 7.6 px/m at head height for a 1.75 m person (8.5 for 2.0 m); detect needs 25, identify 250 | 8 px/m or less at head height (1.75 m person), below the IEC 62676-4 detection level of 25 px/m | Met on paper
R5 | 10 bytes per 15 min bin, six 12-bit counters and a status byte | 15-minute counts per class and direction, open format | Met by design
R6 | Footprint -4.45 to 8.34 m across; margins 10.9 deg; shadow 0.71 m wide behind the pole | 3 m sidewalk, 2 m bike lane and nearest lane from one pole | Met on paper (array turned 90 deg)
R7 | Mild design day: 10.2 h sunlit below single-frame contrast, 3.2 h with track averaging, 0.0 h shaded | -20 to +50 C survival; counting at temperate sites (air up to 20 C); hot sites use the radar variant | At risk (sunlit sidewalks need track averaging)
R8 | 6.22 d (one cell); 4.36 d at -20 C; 4.98 d at end of life | 3 days of continuous counting | Met on paper (one cell)
R9 | 4.4 Wh/day stored against 2.47 Wh/day (6 W) | Energy neutral at 1.5 peak sun hours, 40 % derating | Met on paper (6 W)
R10 | IP65 enclosure (FieldNode), gasketed head with film window | IP65 | Not verifiable at TRL 3
R11 | 5.26 kg | 6 kg or less | Met on paper
R12 | Install estimate 59 min; panel 52 N, post factor 55, twist factor 3.3 | Two people, 60 min, no drilling; 35 m/s gusts | Not verifiable at TRL 3 (wind and fit met on paper)
R13 | $274.00 | $275 or less (budget_usd) | Met on paper
R14 | Nightly depth of discharge 9 %; window UV and cell heat unknown | 5 years, one battery change | Not verifiable at TRL 3
R15 | 0.82 s/h at SF9 (limit 36 s/h); 371 ms at US915 DR0 against 400 ms dwell; 10 of 11 bytes | EU868 1 % duty cycle and US915 dwell limits | Met on paper

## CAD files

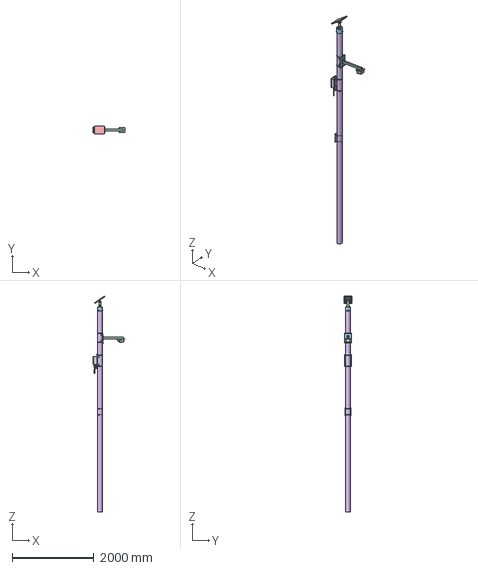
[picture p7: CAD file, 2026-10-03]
cad/step/curbcount-assembly.step
776.5 x 200.0 x 5277.6 mm

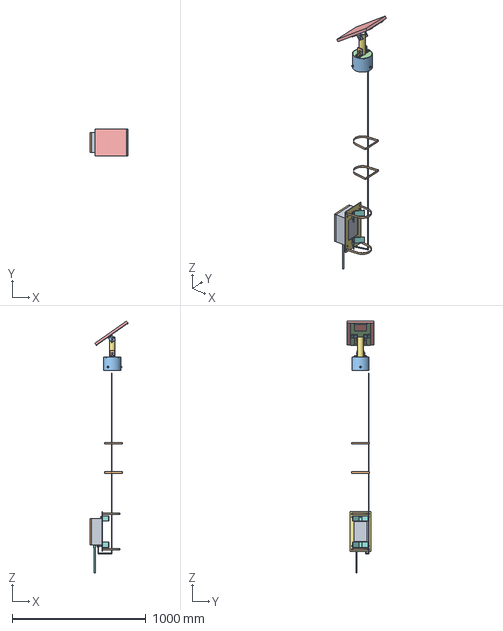
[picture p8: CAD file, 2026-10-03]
cad/step/power-core.step
285.6 x 200.0 x 1887.6 mm

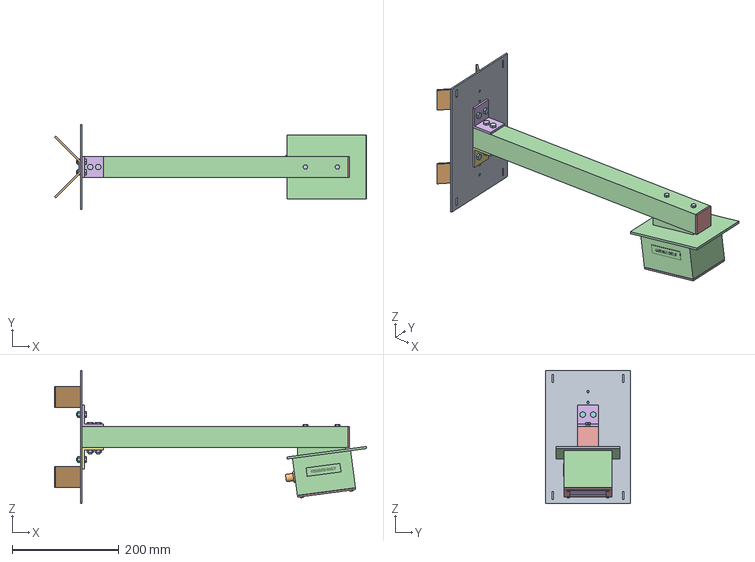
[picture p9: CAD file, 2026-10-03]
cad/step/sensor-head.step
584.8 x 160.0 x 250.0 mm

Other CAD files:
cad/stl/curbcount-assembly.stl
cad/stl/power-core.stl
cad/stl/sensor-head.stl

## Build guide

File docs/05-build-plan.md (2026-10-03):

---
doc_id: CBC-BLD-001
title: CurbCount prototype build plan
project: CurbCount
doc_type: Build plan
version: "0.4"
status: Draft
date: '2026-10-02'
author: Amish Chadha
license: CERN-OHL-S-2.0
revisions:
  - version: "0.1"
    date: '2026-09-30'
    author: Amish Chadha
    change: First build plan, with pictures by component and step; design made constructable (CBC-DDR-003)
  - version: "0.2"
    date: '2026-10-01'
    author: Amish Chadha
    change: Budget treated as a value-engineering target; cross-references updated
  - version: "0.3"
    date: '2026-10-02'
    author: Amish Chadha
    change: "CBC-DDR-003 recorded as accepted by Amish on 2026-10-02"
  - version: "0.4"
    date: '2026-10-02'
    author: Amish Chadha
    change: Embossed COUNTS ONLY plaque on the head housing; notice plate wording; making sketches CBC-DWG-107 and CBC-DWG-116 redrawn
---

# CurbCount prototype build plan

**Plan, not yet built.** How to build the first proof-of-concept prototype, component by component. Building and testing to it is TRL 4 work. Decisions still to be made are kept in the design decisions register ([docs/06-design-decisions.md](06-design-decisions.md)), not here.

## 1. What you are building

Figure 1. Every component, pulled apart and numbered in build order

*Figure 1. Every component pulled apart and numbered in build order. The three groups (enclosure, arm and head, pole-top mount) are drawn closer together than they sit on the pole.*

The prototype is one CurbCount counter built on a 2 m length of street pole in the workshop. It has three groups that each clamp to the pole without drilling it: a FieldNode enclosure on an aluminium saddle plate on the sidewalk side; an aluminium arm on a second saddle plate on the road side, carrying a printed sensor head with the thermal array looking down through a plastic film window; and a 6 W solar panel on a bolted pole-top mount. Two cables join them, tied to the pole, and a small notice plate tells the public what is counted. Figure 1 shows the 26 components in the order you make or fit them. Sixteen are made in a small workshop by sawing, drilling, filing, tapping and bending aluminium sheet, angle, bar and tube, and by 3D printing three parts; the FieldNode enclosure is bought and drilled; the rest is bought. Nothing is welded. The parts cost about $274 from the bill of materials.

> **Safety:** The prototype holds a lithium iron phosphate cell of about 19 Wh; follow the cell stops in section 6 and FieldNode's build plan, never charge it below 0 °C or above 45 °C, and never leave a first build charging unattended. Cut aluminium edges are sharp: deburr everything and wear gloves. Printing ASA gives off fumes; print in a ventilated space. A heat-set insert iron runs at over 200 °C. The finished prototype weighs about 5.3 kg with the panel at the top of a 2 m stub: the stub must stand in a base that cannot tip (stop S4). Installing on a real street pole is work at height beside traffic and is outside this plan (stop S6).

## 2. What changed to make it buildable

The concept showed what the counter does; some of its parts could not be made or fixed as drawn. Each change below keeps what the counter does, and all of them are recorded in decision record CBC-DDR-003, accepted by Amish on 2026-10-02.

*Table 1. Changes from the concept.*

| Component | The concept had | The buildable design has | Why |
| --- | --- | --- | --- |
| Saddle plates | Flat plates against the round pole; bands drawn as rings that held nothing | Bent V-saddles on the back of each plate, and bands that pass through slots in the plate and across its front (Figures 4 and 5) | The pole seats on the faces of a 90° V; the band pulls the plate onto the pole |
| Enclosure | No fixing to its plate; parts floating inside | FieldNode's buildable core: four lugs on M5 screws, internal plate on bosses, two rows of holes in the bottom (Figures 7 to 10) | CurbCount uses FieldNode's core unchanged |
| Arm | Butted to its plate, "welded or bolted" | Two angle brackets, four M6 bolts through the plate and two down through the tube on crush spacers (Figure 15) | Bolted, no welding; the tube walls cannot crush |
| Sensor head | Floating under the arm; film loose in a larger opening; no cable entry | Printed wedge pad with two M5 bolts into inserts; film clamped to an inner ledge by a printed frame; array on standoffs; a gland under the hood (Figures 17 to 20) | Every part held; window height and tilt unchanged |
| Pole-top mount | Welded cap and post; hinge plate and panel floating | Sleeve with rivet-nut set screws, a cap disc on radial screws, post on angle clips with plugs, a tilted rail plate, panel bolted through its frame lip (Figures 21 to 31) | All bolted; the frame lip is the only part of a panel that takes a bolt |
| Cables | Sensor cable off the pole and under the bands; no panel lead | Both cables tied to the pole and over the bands; sensor cable beside the arm into the head gland; a 1.5 m panel extension lead (Figure 34) | Nothing clamps a cable; the panel's own lead is too short |
| Notice plate | No fixing | Two stainless ties through four slots (Figures 32 and 33) | Nothing drilled |

The changes add about 0.8 kg: the counter weighs 5.26 kg on the pole, within the 6 kg limit.

## 3. Making the components

Make and check each component before the assembly step that needs it. Sizes are in millimetres. "Road side" and "sidewalk side" are as the counter stands at the site: the arm points to the road, the enclosure faces the sidewalk. Workshop tolerance is 0.5 mm unless a step says otherwise; drawings do not carry tolerances before TRL 4.

### 3.1 Enclosure saddle plate

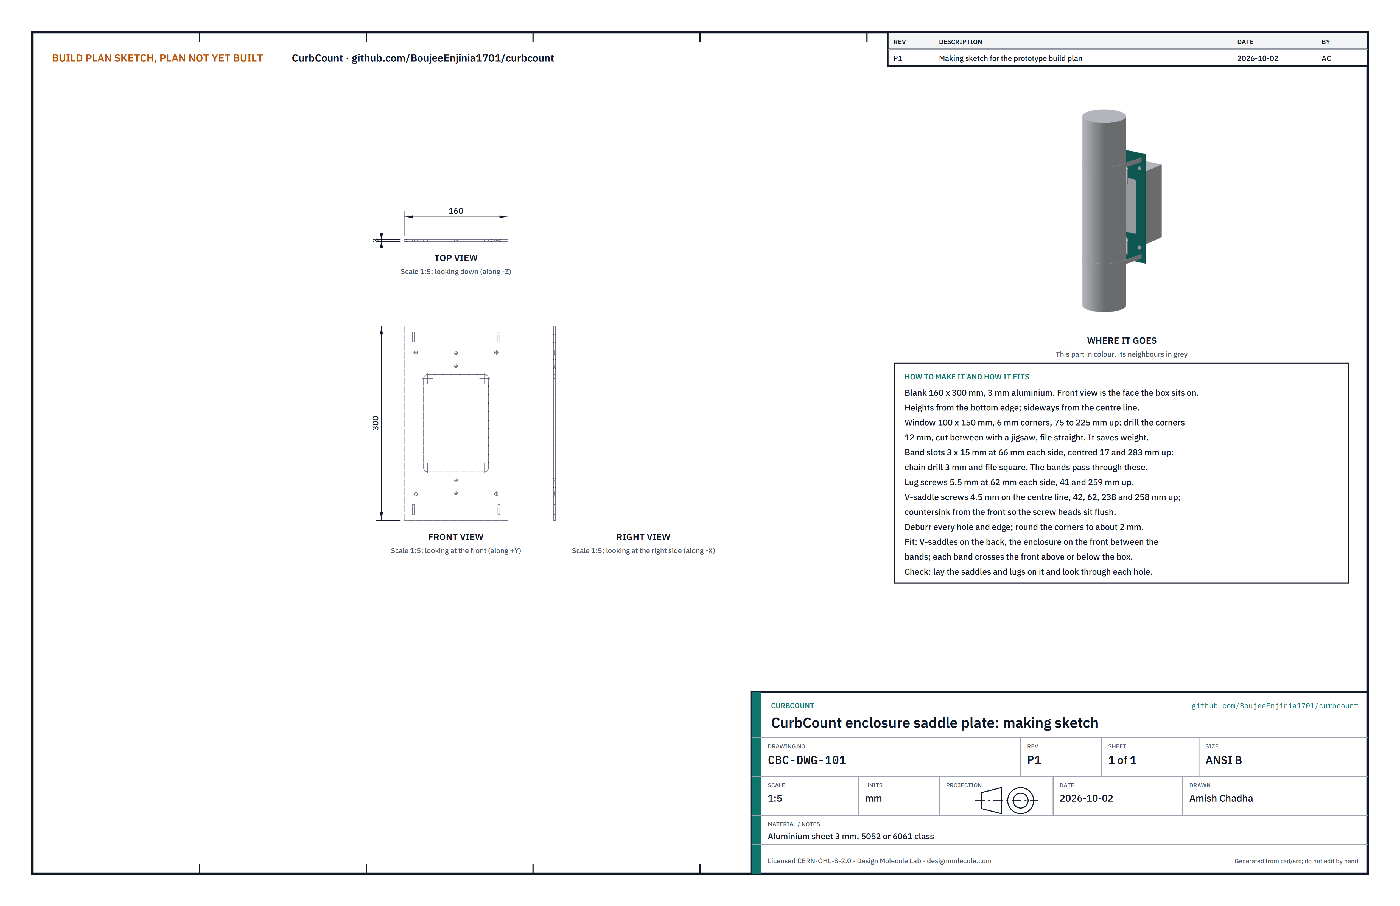
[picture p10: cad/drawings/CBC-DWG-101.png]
Figure 2. Making sketch of the enclosure saddle plate


*Figure 2. Enclosure saddle plate making sketch (CBC-DWG-101).*

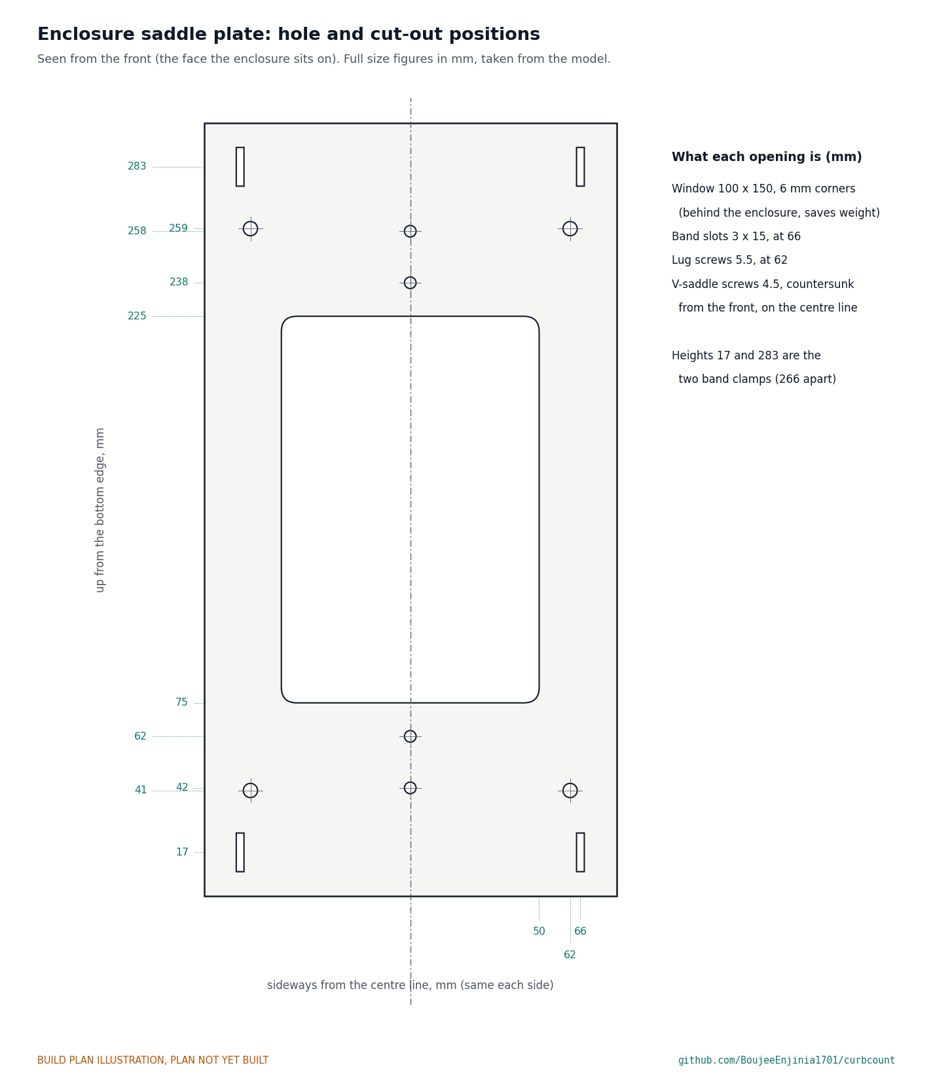
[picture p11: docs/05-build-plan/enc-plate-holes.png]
Figure 3. Hole and cut-out positions on the enclosure saddle plate


*Figure 3. Every hole, slot and cut-out, full size figures, measured up from the bottom edge and sideways from the centre line.*

**What it is and what it is made from.** The plate the FieldNode enclosure hangs on, clamped to the sidewalk side of the pole. Aluminium sheet 3 mm thick, 5052 or 6061 class, cut to 160 x 300 mm.

**How to make it.**

1. Cut the blank to 160 x 300 mm, square. File the edges and round the corners to about 2 mm.
2. Scribe a centre line down the long side. Mark one face as the front (the enclosure side).
3. Mark every hole from Figure 3: heights up from the bottom edge, sideways from the centre line.
4. Band slots: four slots 3 wide and 15 tall, 66 each side of centre, centred 17 and 283 up. Chain drill with a 3 mm drill and file square.
5. Lug screw holes: four 5.5 mm holes, 62 each side of centre, 41 and 259 up.
6. V-saddle screw holes: four 4.5 mm holes on the centre line, 42, 62, 238 and 258 up. Countersink them from the front so M4 countersunk screws sit flush.
7. Window: 100 wide and 150 tall, centred, from 75 to 225 up. Drill a 12 mm hole in each corner, cut between the holes with a jigsaw and a metal blade, and file straight.
8. Deburr every hole on both faces.

**How it fits the parts next to it.**

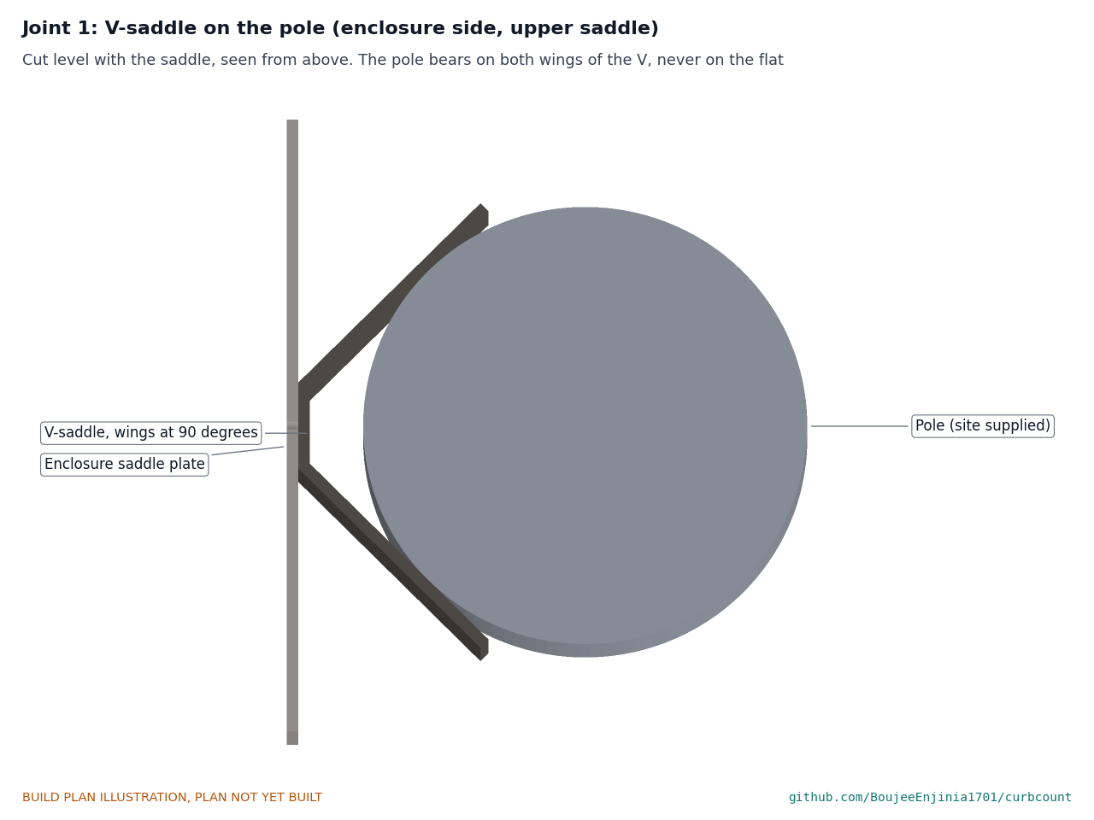
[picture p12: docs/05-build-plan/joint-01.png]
Figure 4. Joint 1: V-saddle on the pole


*Figure 4. Seen from above at the upper saddle: the pole touches both wings of the V and never the flat.*

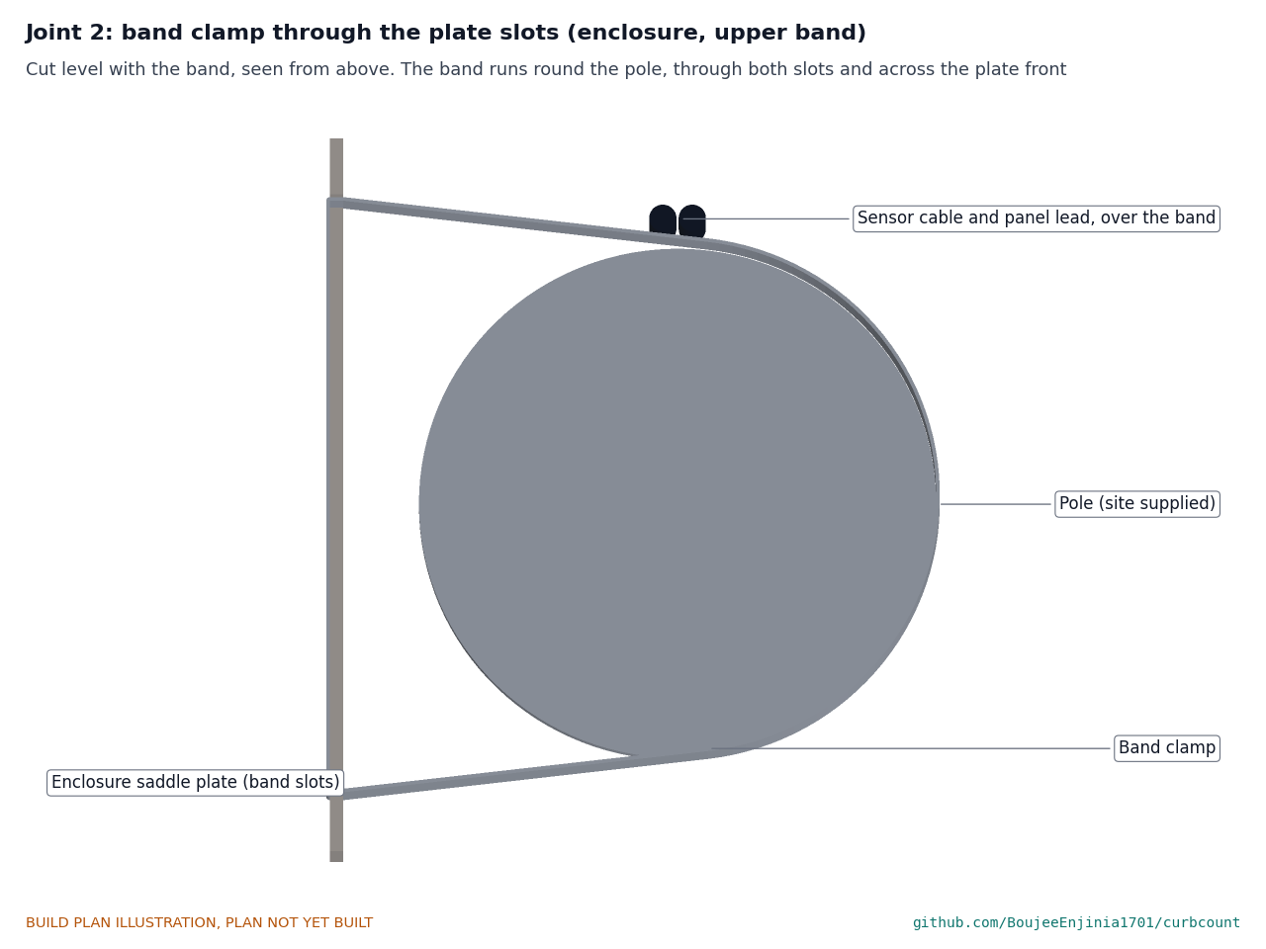
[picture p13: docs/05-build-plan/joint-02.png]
Figure 5. Joint 2: band clamp through the slots


*Figure 5. Seen from above at the upper band: the band goes round the road side of the pole, through both slots and across the front of the plate; the two cables pass over it.*

The two V-saddles sit flat on the back, their flats over the screw holes (Figure 4). The enclosure's back sits flat on the front, centred, between the band slots, held by its four lugs (section 3.3). Each band passes round the pole, through the slots on both sides and across the front, 33 mm above the box's top or below its bottom. The saddles sit 35 mm in from the bands, so the bands never touch the saddle wings on any pole from 60 to 140 mm.

**Check before moving on.** Lay the saddles and the enclosure's lugs on the plate and look through each hole: the holes must line up without forcing a screw.

### 3.2 V-saddles (make 4)

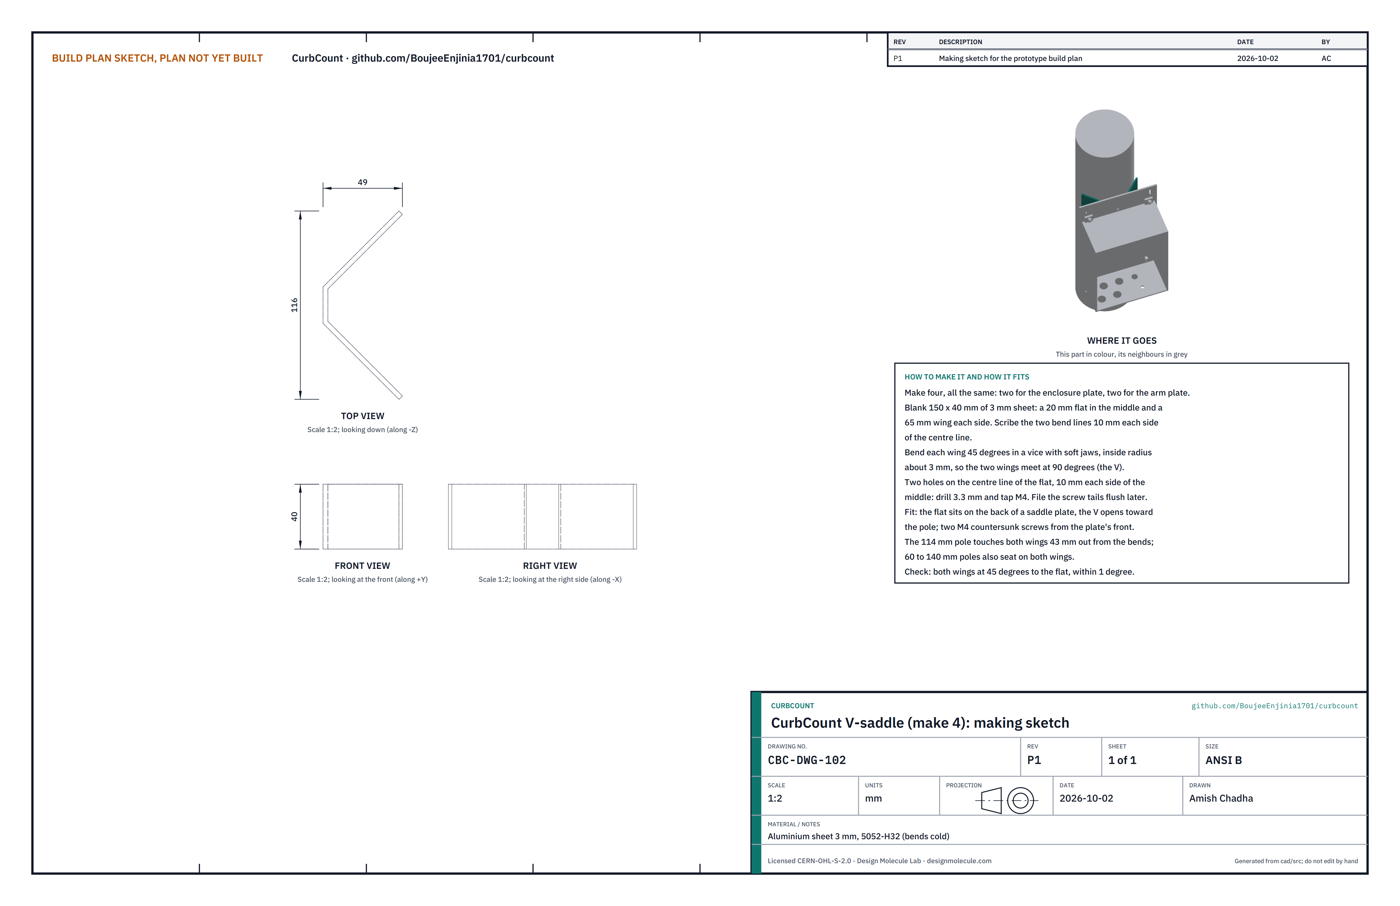
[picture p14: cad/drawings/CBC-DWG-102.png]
Figure 6. Making sketch of the V-saddle


*Figure 6. V-saddle making sketch (CBC-DWG-102).*

**What it is and what it is made from.** A bent strip with a V that seats a saddle plate on the round pole. Four are needed, all the same: two for the enclosure plate, two for the arm plate. Aluminium sheet 3 mm, 5052-H32, which bends cold without cracking.

**How to make it.**

1. Cut four blanks 150 x 40 mm. Deburr.
2. Scribe two bend lines across each blank, 10 mm each side of the centre: a 20 mm flat in the middle and a 65 mm wing each side.
3. Clamp the blank in a vice with soft jaws on a bend line and bend the wing 45°, inside radius about 3 mm. Repeat for the other wing, bending the same way, so the wings meet at 90°.
4. On the centre line of the flat, 10 mm each side of the middle, drill 3.3 mm and tap M4.

**How it fits the parts next to it.** The flat sits on the back of a saddle plate, the V opening toward the pole, held by two M4 countersunk screws put in from the plate's front with a drop of medium threadlocker; file the screw tails flush with the flat. The 114 mm design pole touches both wings 43 mm out from the bends (Figure 4); poles from 60 to 140 mm also seat on both wings, and a 60 mm pole still clears the flat by 2 mm.

**Check before moving on.** Each wing is at 45° to the flat, within 1°: check with a protractor or the 45° face of a combination square.

### 3.3 FieldNode enclosure, drilled, with its glands, ports, vent, antenna and lugs

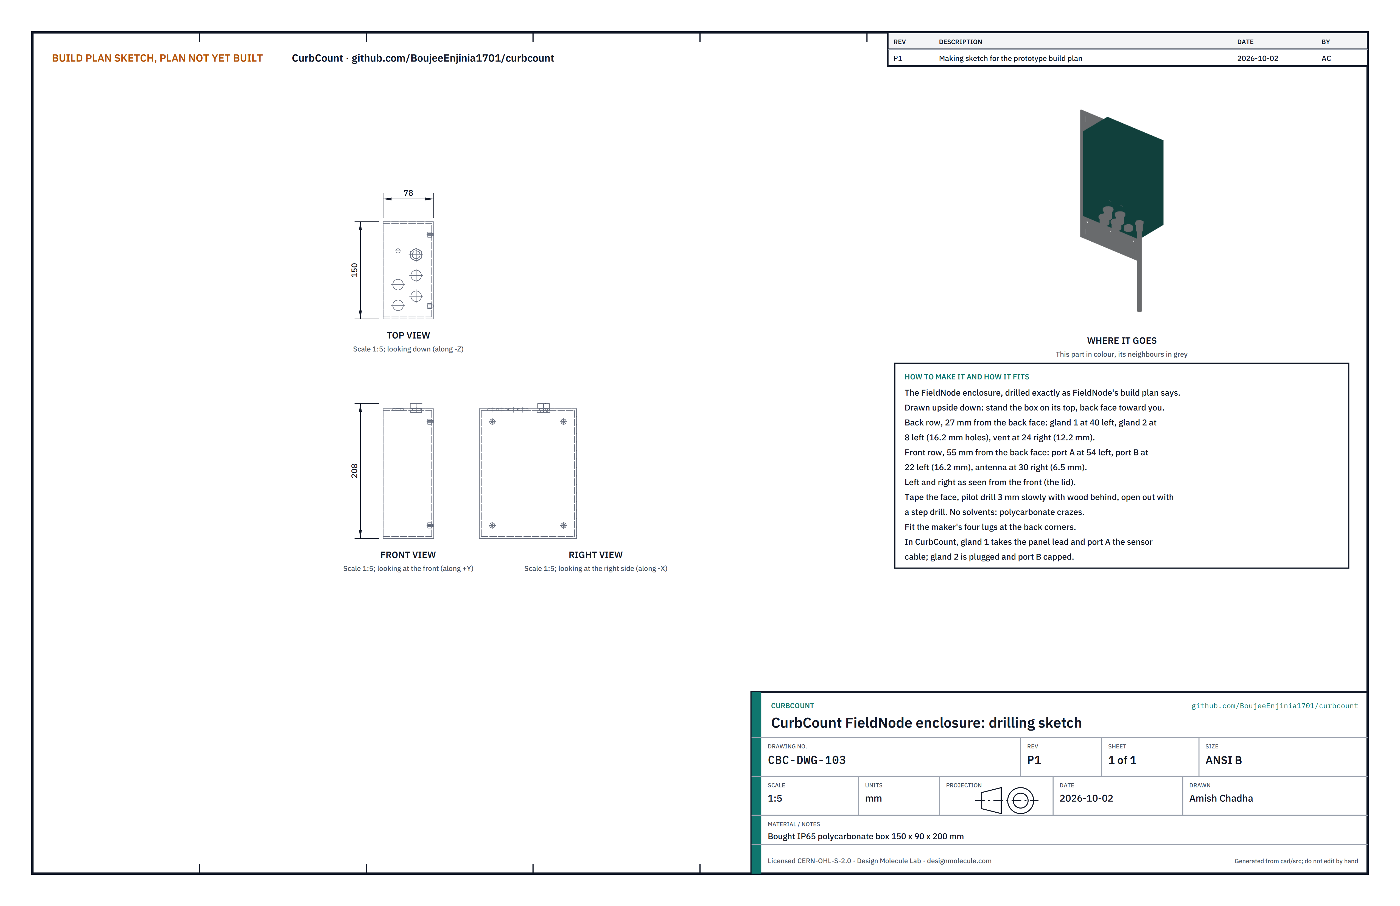
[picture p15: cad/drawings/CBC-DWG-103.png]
Figure 7. Drilling sketch of the FieldNode enclosure


*Figure 7. FieldNode enclosure drilling sketch (CBC-DWG-103), drawn upside down so the top view shows the bottom face.*

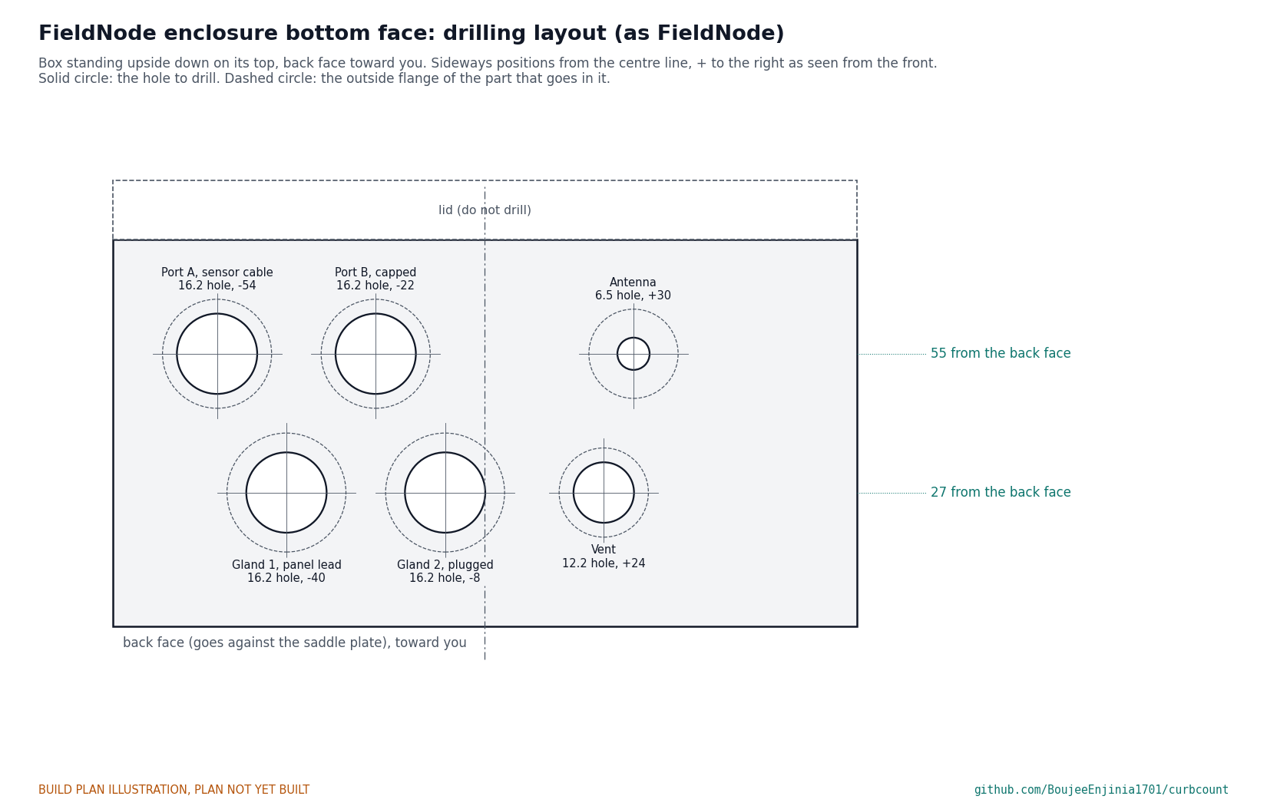
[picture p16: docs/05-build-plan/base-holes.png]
Figure 8. Bottom face drilling layout


*Figure 8. Drilling layout, with the box standing upside down on its top and its back face toward you.*

**What it is and what it is made from.** CurbCount's power, radio and processor: the standard FieldNode core, a bought grey polycarbonate box 150 x 90 x 200 mm (IP65) with a gasketed lid, four moulded bosses inside its back wall and the maker's kit of four external lugs, holding the internal plate with the cell, charger and protection modules, the STM32WL controller and a plug-in connector strip. It is made exactly as FieldNode's build plan (FND-BLD-001) says, in its sections 3.3 and 3.4 and steps 2, 4, 5 and 6; this section lists only what is particular to CurbCount.

**How to make it.**

1. Drill the bottom face as Figure 8 shows: back row, 27 from the back face: gland 1 at 40 left, gland 2 at 8 left (16.2 mm holes), vent at 24 right (12.2 mm); front row, 55 from the back face: port A at 54 left, port B at 22 left (16.2 mm), antenna at 30 right (6.5 mm). Left and right are as seen from the front (the lid). Pilot 3 mm slowly with wood behind, open out with a step drill, no solvents.
2. Fit the four lugs to the box's back corners as the lug kit's maker describes.
3. Fit the glands, vent, ports and antenna from below, sealing washers outside, nuts inside. In CurbCount gland 1 takes the panel lead and port A the sensor cable; put the blanking plug in gland 2 and the cap on port B.
4. Build and wire the internal plate as FieldNode's build plan says, with the cell out and the fuse out, with one difference: the array runs on 3.3 V, so in place of FieldNode's boost converter for port A fit a 3.3 V load switch module fed from the 3.3 V converter and enabled by the same controller pin, still through its resettable fuse. Port A's signal pins go to the controller's I²C pins (Figure 11).

**How it fits the parts next to it.**

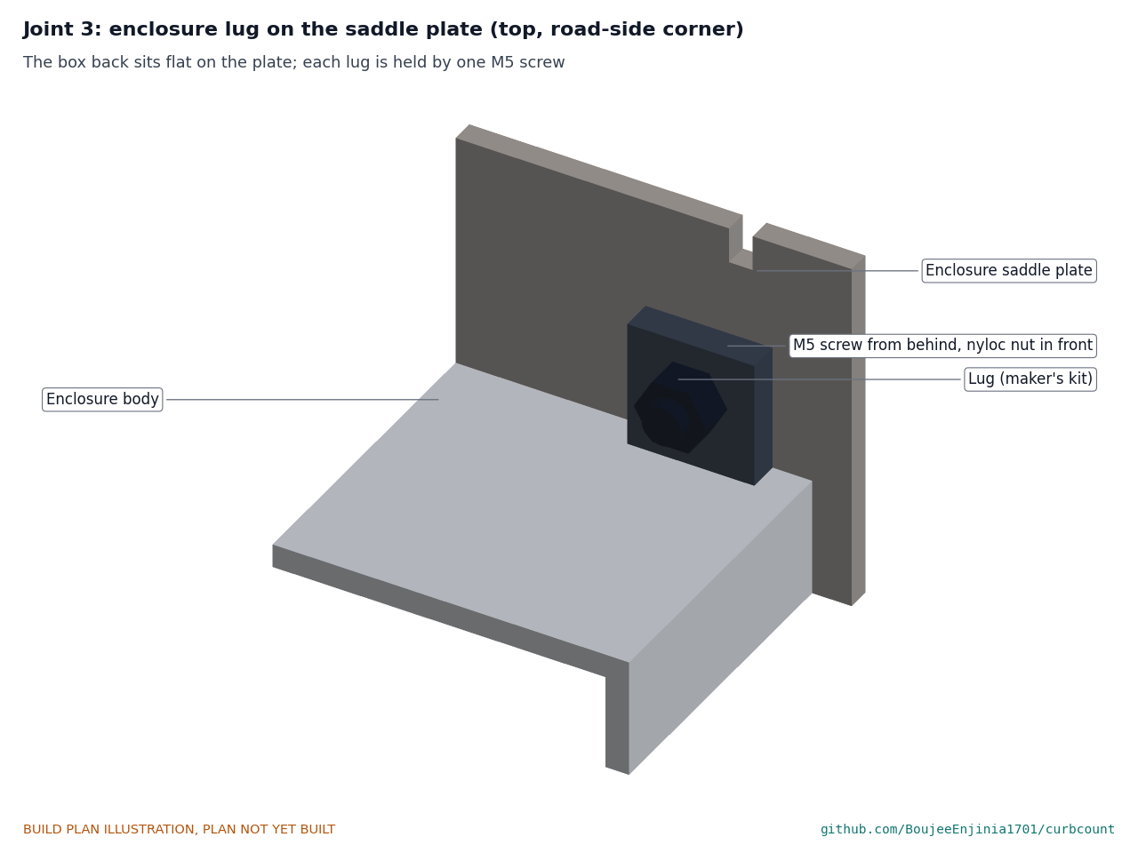
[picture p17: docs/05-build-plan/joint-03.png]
Figure 9. Joint 3: enclosure lug on the saddle plate


*Figure 9. Each lug lies flat on the plate beside the box and is held by one M5 button-head screw from behind the plate, nyloc nut in front.*

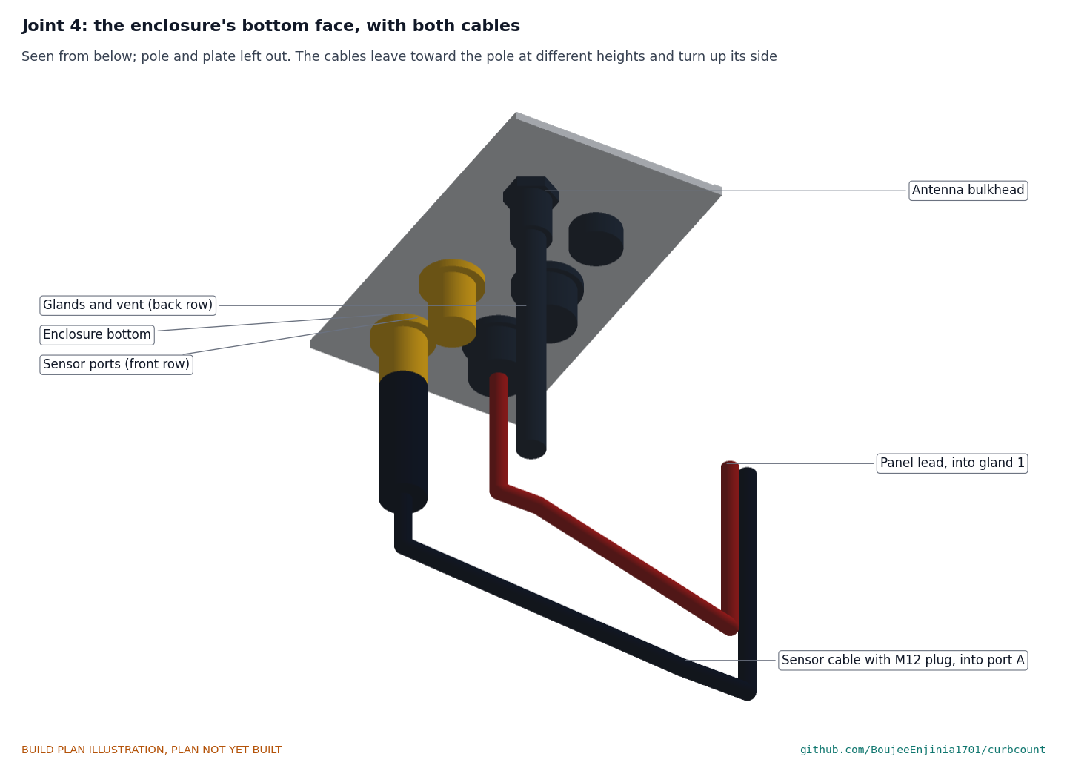
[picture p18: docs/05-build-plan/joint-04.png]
Figure 10. Joint 4: the enclosure's bottom face with both cables


*Figure 10. The sensor cable's M12 plug on port A and the panel lead in gland 1; both cables run to the pole below the plate's bottom edge.*

The box's back sits flat on the saddle plate's front, over the window, centred between the band slots; the lid faces away from the pole. The four lug screws can all be reached with the lid shut. The cables leave from the bottom face (Figure 10).

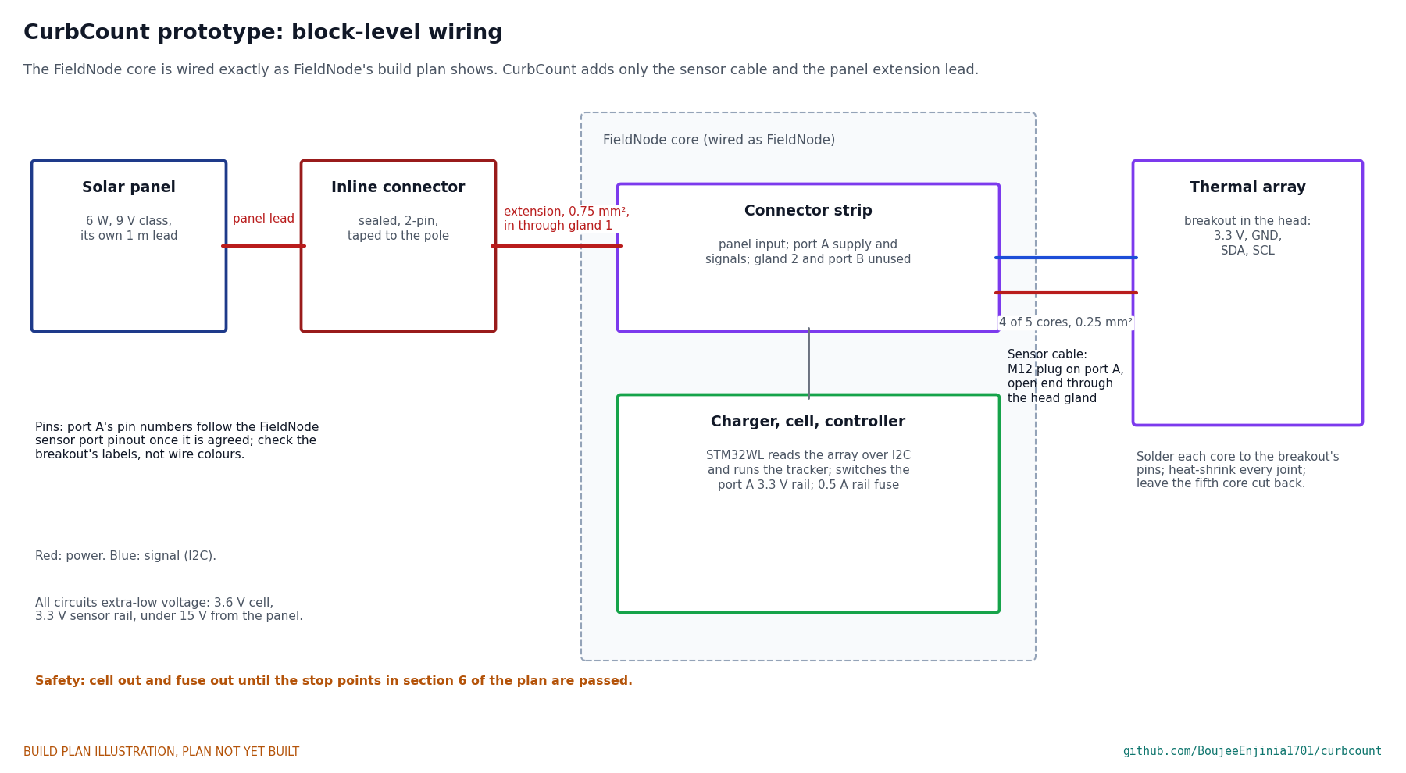
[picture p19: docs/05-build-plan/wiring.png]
Figure 11. Block-level wiring


*Figure 11. What CurbCount adds to FieldNode's wiring: the sensor cable to the array and the panel extension lead. No circuit board is laid out at this stage.*

**Check before moving on.** FieldNode's checks for the core all pass (its section 3.4): every wire continues end to end; with the cell out and the fuse out, the pack terminals and every rail read open to ground.

### 3.4 Arm saddle plate

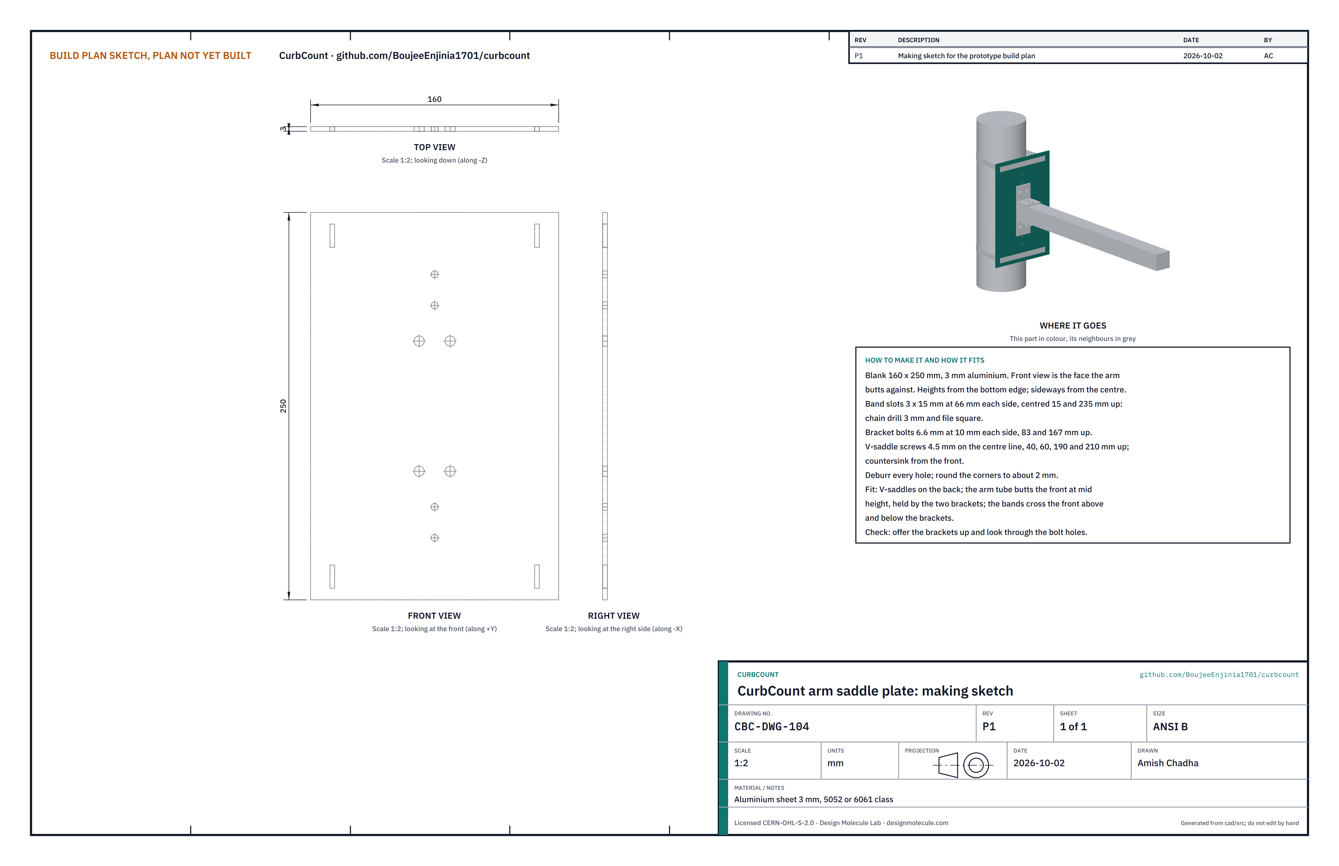
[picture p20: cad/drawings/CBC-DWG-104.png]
Figure 12. Making sketch of the arm saddle plate


*Figure 12. Arm saddle plate making sketch (CBC-DWG-104).*

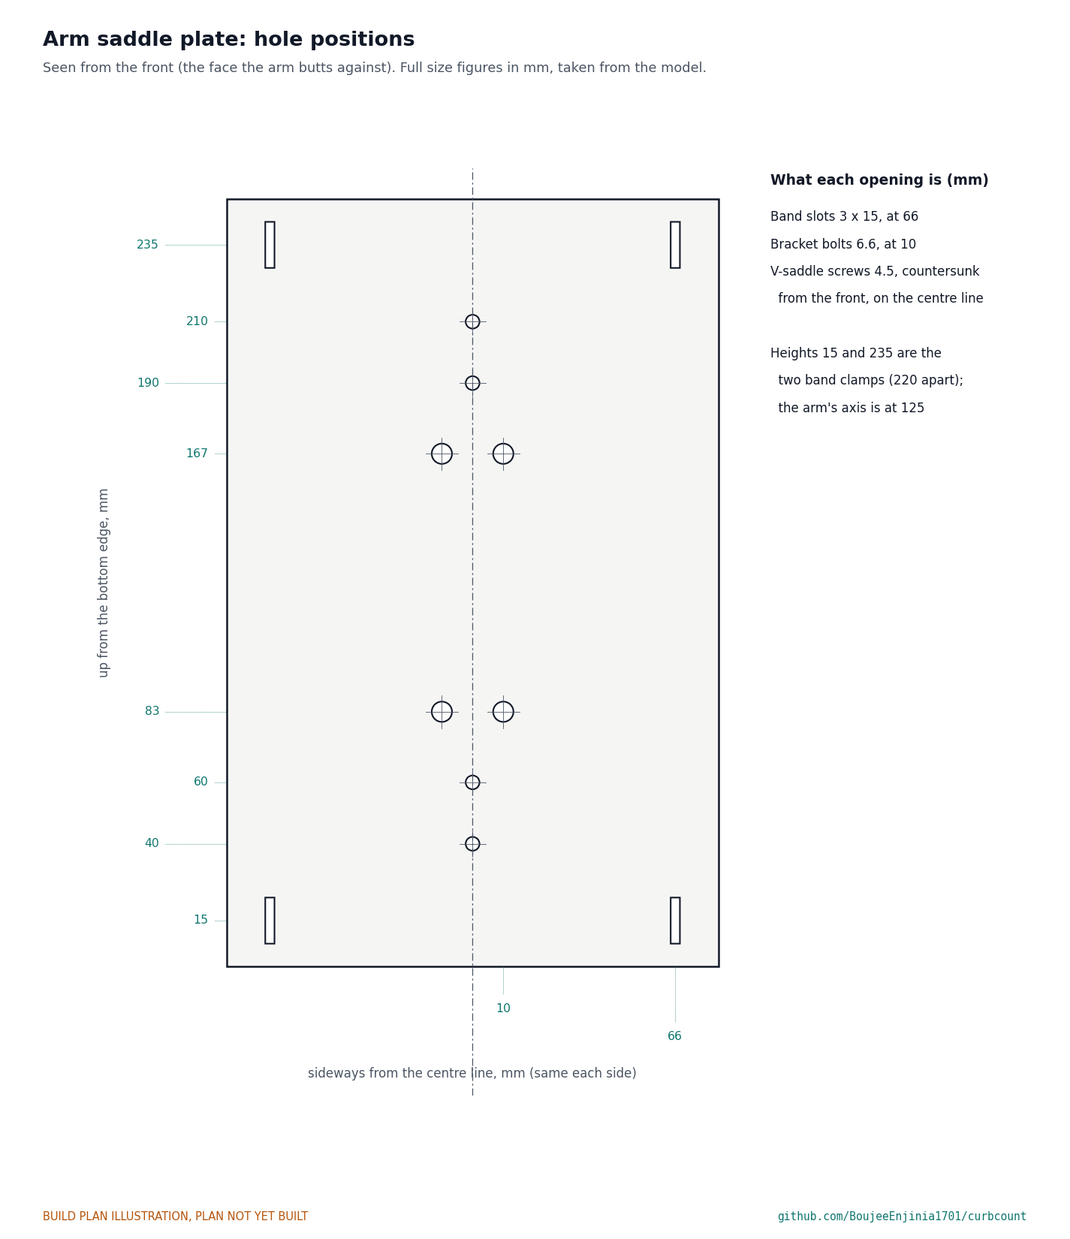
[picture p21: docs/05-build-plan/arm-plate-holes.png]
Figure 13. Hole positions on the arm saddle plate


*Figure 13. Every hole and slot, measured up from the bottom edge and sideways from the centre line.*

**What it is and what it is made from.** The plate the arm butts against, clamped to the road side of the pole. Aluminium sheet 3 mm, 5052 or 6061 class, cut to 160 x 250 mm.

**How to make it.**

1. Cut the blank to 160 x 250 mm, square; file the edges and round the corners to about 2 mm. Scribe the centre line; mark the front.
2. Band slots: four slots 3 x 15 mm, 66 each side of centre, centred 15 and 235 up. Chain drill and file square.
3. Bracket bolt holes: four 6.6 mm holes, 10 each side of centre, 83 and 167 up.
4. V-saddle screw holes: four 4.5 mm holes on the centre line, 40, 60, 190 and 210 up, countersunk from the front.
5. Deburr every hole on both faces.

**How it fits the parts next to it.** Two V-saddles on the back, exactly as on the enclosure plate (Figure 4). The arm tube butts the front at mid height (125 up), held by the two brackets (Figure 14). The bands cross the front 15 mm from each end, clear of the brackets by 44 mm.

**Check before moving on.** Offer the brackets up to the front and look through the bolt holes.

### 3.5 Arm brackets (make 2)

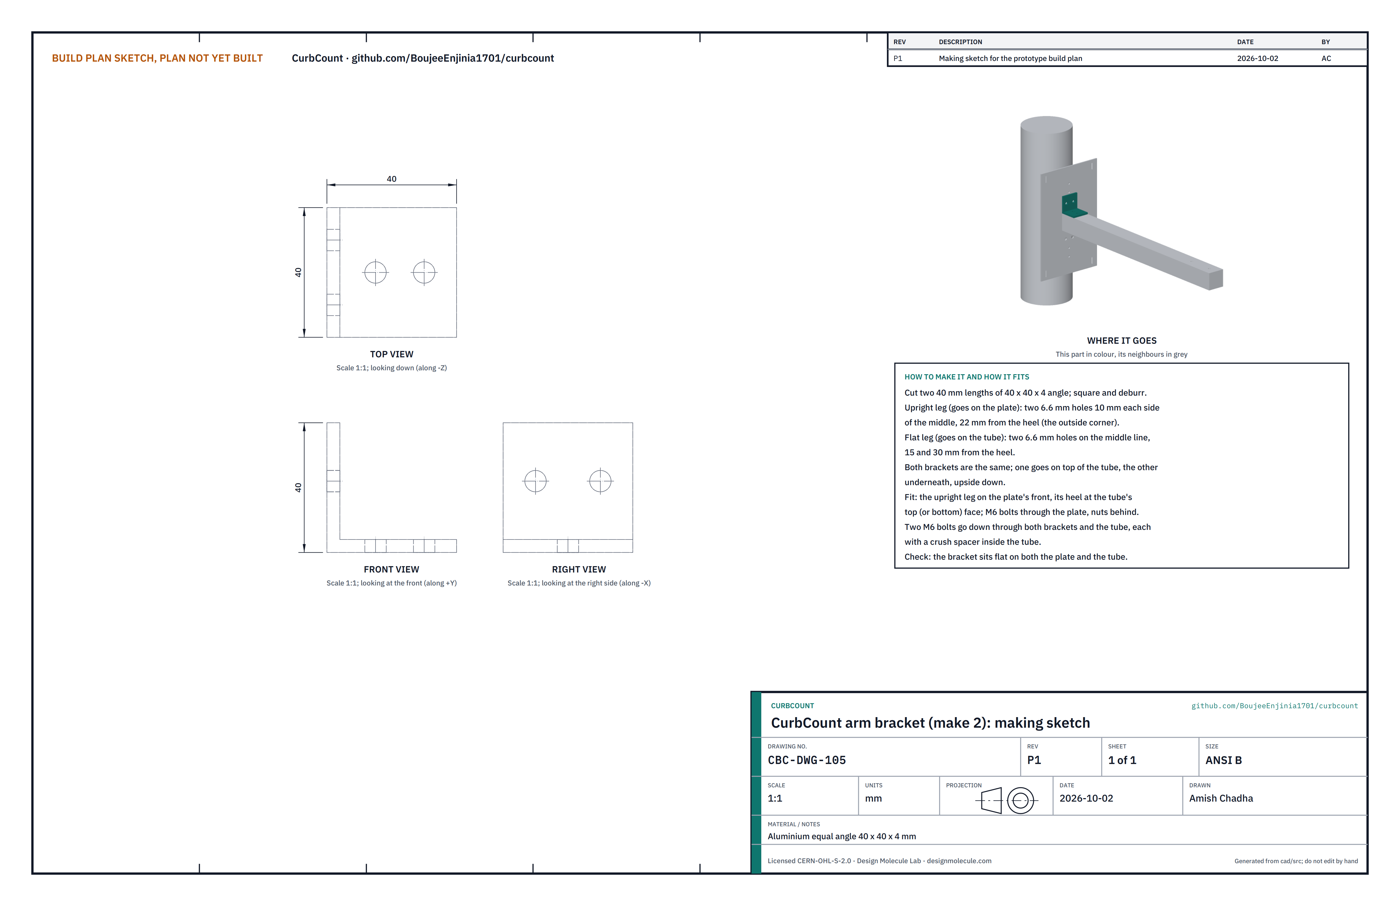
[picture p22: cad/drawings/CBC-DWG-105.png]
Figure 14. Making sketch of the arm bracket


*Figure 14. Arm bracket making sketch (CBC-DWG-105).*

**What it is and what it is made from.** A short angle that joins the arm tube to its plate; one goes on top of the tube and one underneath. Aluminium equal angle 40 x 40 x 4 mm.

**How to make it.**

1. Cut two 40 mm lengths; square and deburr the ends.
2. Upright leg (on the plate): two 6.6 mm holes 10 each side of the middle, 22 from the heel (the outside corner).
3. Flat leg (on the tube): two 6.6 mm holes on the middle line, 15 and 30 from the heel.
4. Both brackets are the same: drill them clamped together.

**How it fits the parts next to it.**

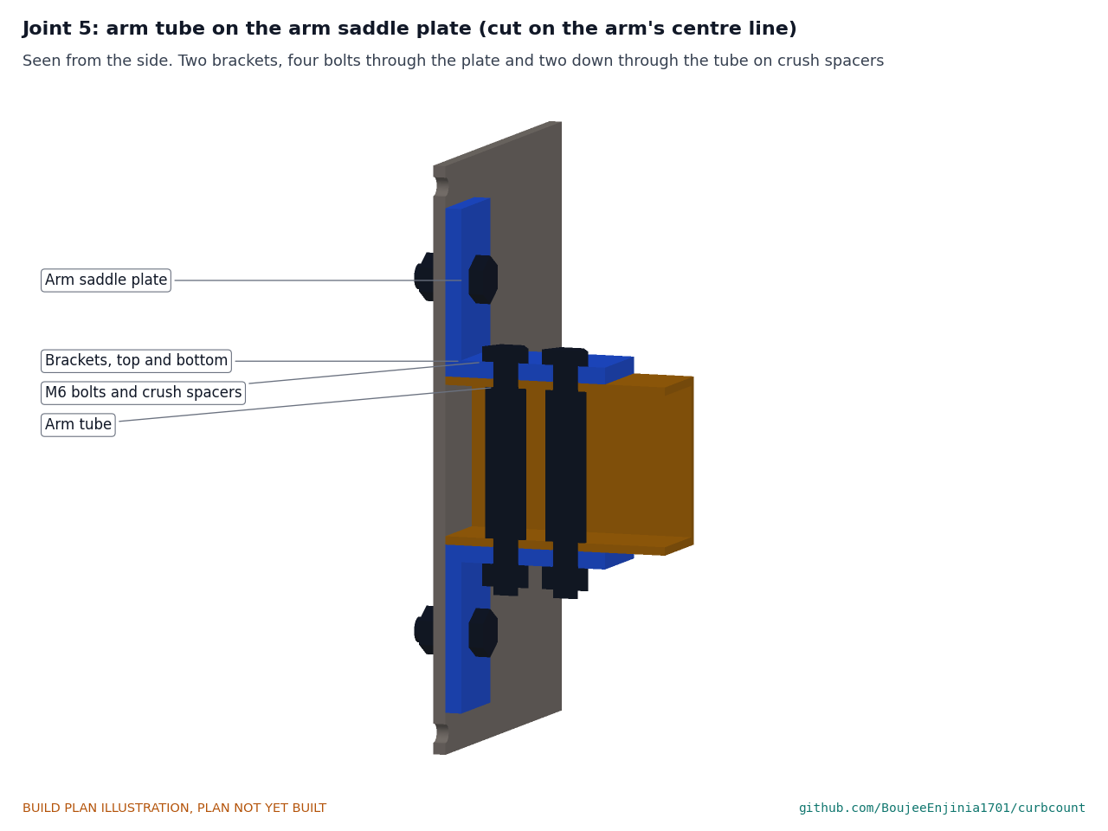
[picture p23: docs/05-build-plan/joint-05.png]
Figure 15. Joint 5: arm tube on the arm saddle plate


*Figure 15. Cut on the arm's centre line: one bracket above and one below the tube; M6 bolts through each upright leg and the plate, nuts behind the plate; two M6 bolts down through both flat legs and the tube, each on a crush spacer inside the tube.*

The heel of each bracket sits in the corner between the plate and the tube: the upright leg flat on the plate's front, the flat leg flat on the tube's top (or bottom) face. The nuts behind the plate clear a 114 mm pole by 10 mm.

**Check before moving on.** Each bracket sits flat on both the plate and the tube with no rocking.

### 3.6 Arm tube

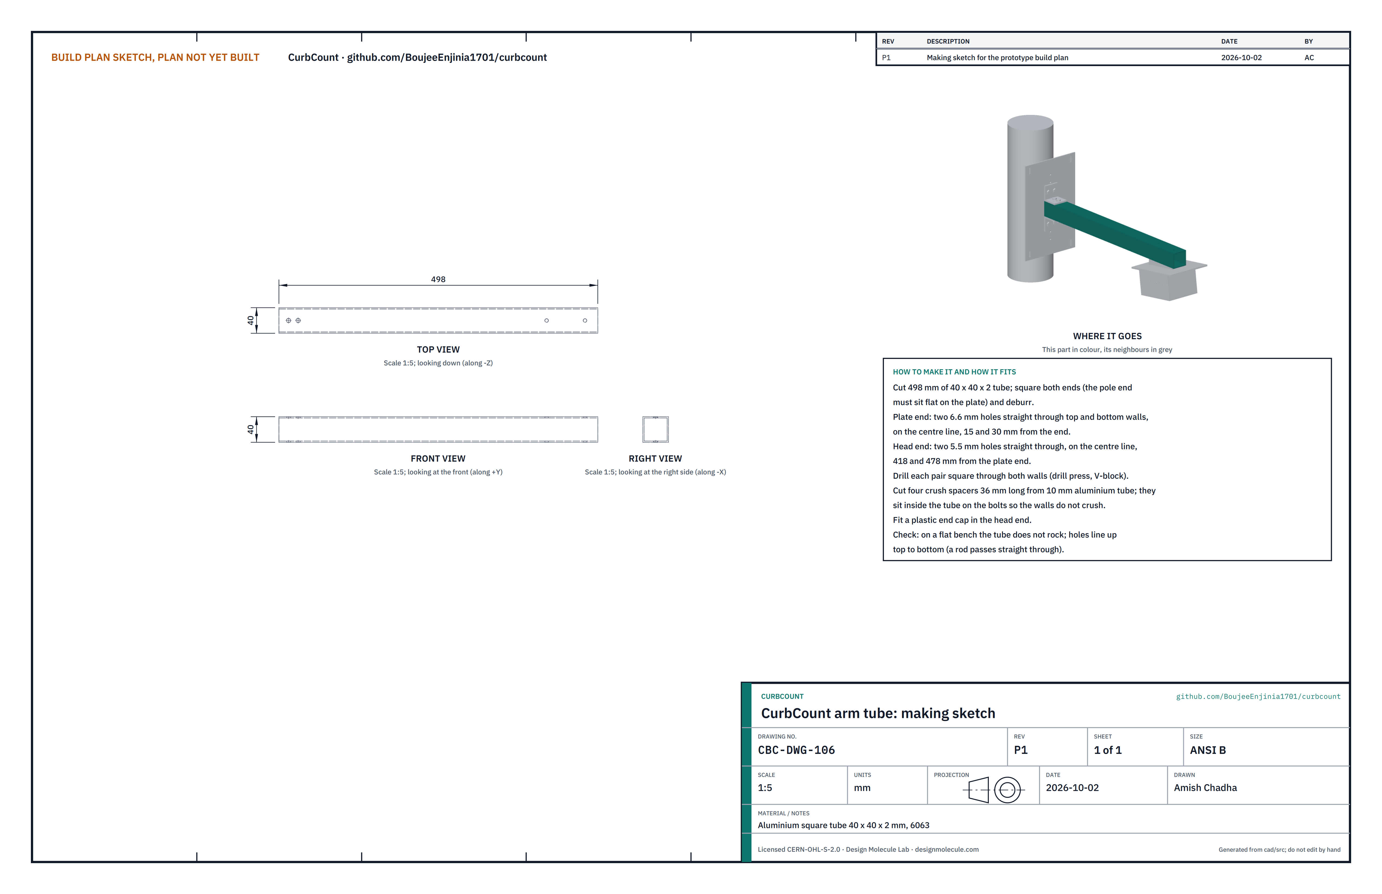
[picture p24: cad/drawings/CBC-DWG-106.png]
Figure 16. Making sketch of the arm tube


*Figure 16. Arm tube making sketch (CBC-DWG-106).*

**What it is and what it is made from.** The arm that holds the sensor head out over the curb, 530 mm from the pole's centre. Aluminium square tube 40 x 40 x 2 mm, 6063 class, 498 mm long.

**How to make it.**

1. Cut 498 mm and square both ends; the plate end must sit flat. Deburr.
2. Plate end: two 6.6 mm holes straight down through the top and bottom walls on the centre line, 15 and 30 from the end.
3. Head end: two 5.5 mm holes straight through on the centre line, 418 and 478 from the plate end.
4. Drill each hole through both walls in one pass, with the tube in a V-block on a drill press.
5. Cut four crush spacers 36 mm long from 10 mm aluminium tube (6 mm bore).
6. Push a plastic end cap into the head end.

**How it fits the parts next to it.** The plate end butts the arm saddle plate between the brackets (Figure 15). The head hangs under the far end on two M5 bolts (Figure 18). The sensor cable runs along the tube's side, tied to it (Figure 34).

**Check before moving on.** On a flat bench the tube does not rock, and a rod passes straight down through each pair of holes.

### 3.7 Head housing

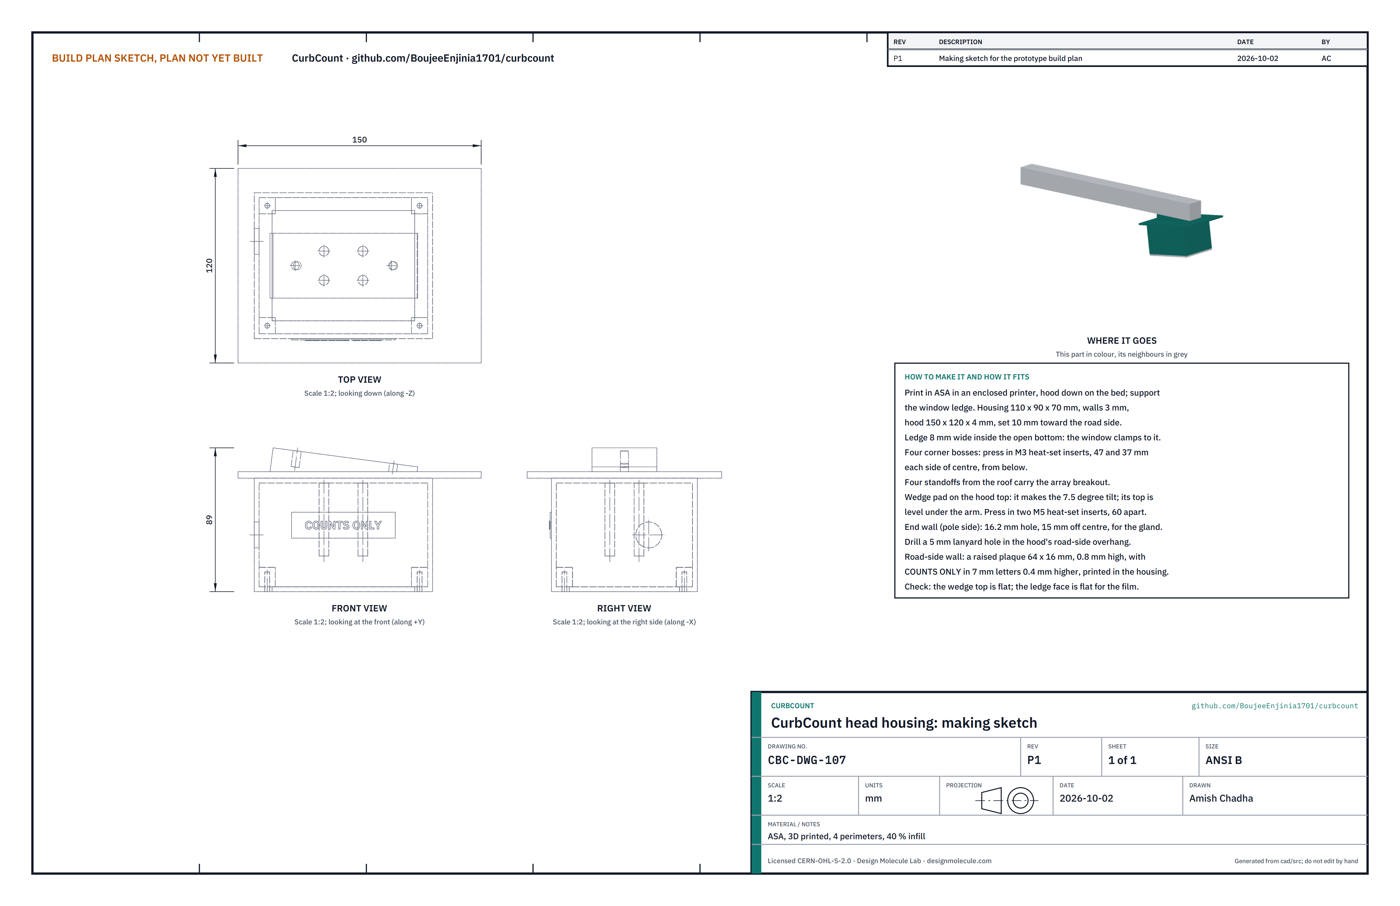
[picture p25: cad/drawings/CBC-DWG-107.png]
Figure 17. Making sketch of the head housing


*Figure 17. Head housing making sketch (CBC-DWG-107), drawn level; it hangs tilted 7.5° toward the road.*

**What it is and what it is made from.** The box that holds the thermal array, open underneath for the window, with a sun hood on top and a wedge pad that sets the tilt. ASA, printed in one piece: housing 110 x 90 x 70 mm, walls 3 mm, hood 150 x 120 x 4 mm, with a raised "COUNTS ONLY" plaque on the road-side wall (a pad 64 x 16 mm and 0.8 mm high, with 7 mm letters standing 0.4 mm higher) printed as part of the housing.

**How to make it.**

1. Print in ASA in an enclosed printer, hood down on the bed, four perimeters, 40 % infill. Support the 8 mm window ledge inside the open bottom. Let it cool on the bed.
2. Clean up the ledge's underside so it is flat: the film seals against it.
3. With a heat-set insert tool, press an M3 insert into each of the four corner bosses from below (47 and 37 mm each side of centre), and an M5 insert into each of the two holes in the wedge pad (60 apart).
4. Ream the 16.2 mm gland hole in the pole-side end wall, 15 mm off centre.
5. Drill a 5 mm lanyard hole through the hood's road-side overhang, 10 mm in from its edge.
6. Check the raised plaque on the road-side wall: the letters must be crisp and the pad flat. Do not sand it.

**How it fits the parts next to it.**

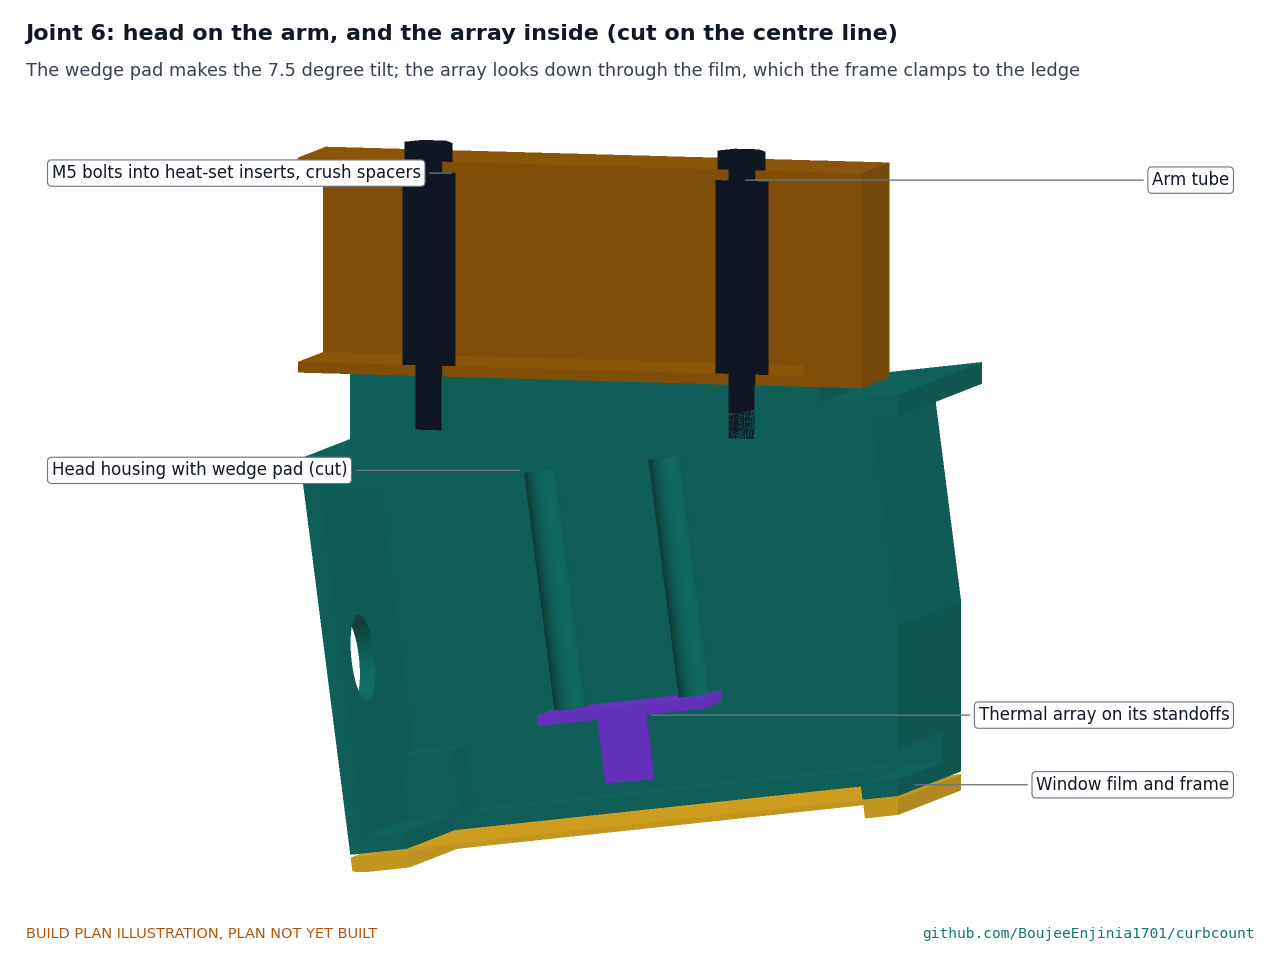
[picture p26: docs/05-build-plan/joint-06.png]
Figure 18. Joint 6: head on the arm


*Figure 18. Cut on the centre line: the wedge pad's level top sits against the arm's underside; two M5 bolts come down through the arm on crush spacers into the inserts; the array hangs from its standoffs above the window.*

The wedge pad's top is level when the housing hangs at 7.5°, and sits flat against the underside of the arm's far end. The arm's end cap stops 2 mm short of the hood. The array breakout sits on the four standoffs from the roof on M2.5 screws, its lens looking straight down 8 mm above the film.

**Check before moving on.** The wedge top and the ledge face are flat (a steel rule shows no light); the inserts are square and flush.

### 3.8 Window frame and film

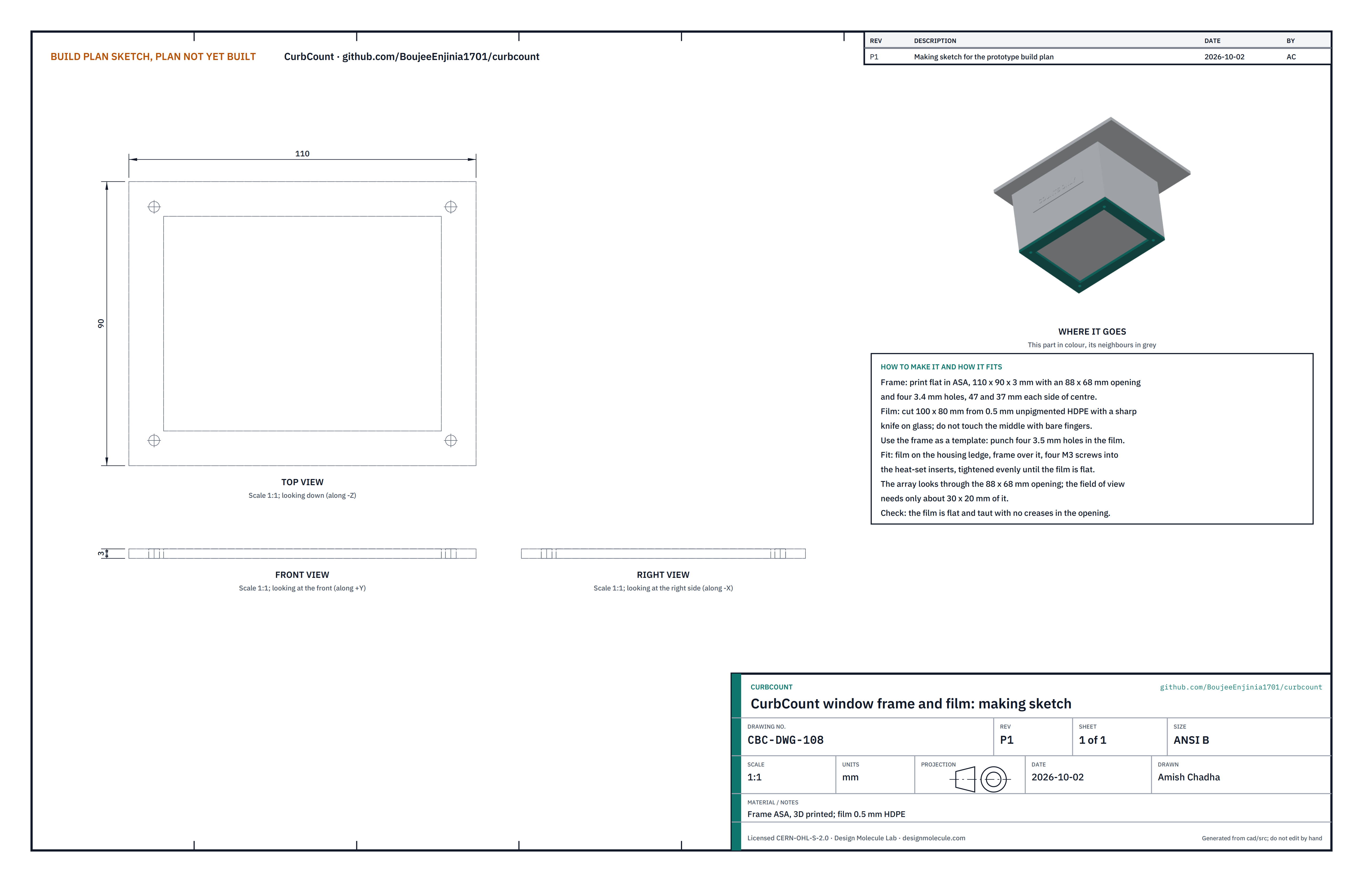
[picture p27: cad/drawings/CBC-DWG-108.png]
Figure 19. Making sketch of the window frame


*Figure 19. Window frame and film making sketch (CBC-DWG-108).*

**What it is and what it is made from.** The window the array looks through: a 0.5 mm unpigmented HDPE film, 100 x 80 mm, clamped to the housing's ledge by a printed ASA frame 110 x 90 x 3 mm with an 88 x 68 mm opening.

**How to make it.**

1. Print the frame flat in ASA with its four 3.4 mm screw holes, 47 and 37 mm each side of centre.
2. Cut the film 100 x 80 mm with a sharp knife on a sheet of glass. Handle it by the edges; keep fingerprints off the middle.
3. Lay the frame on the film as a template and punch four 3.5 mm holes through the film at the screw holes.

**How it fits the parts next to it.**

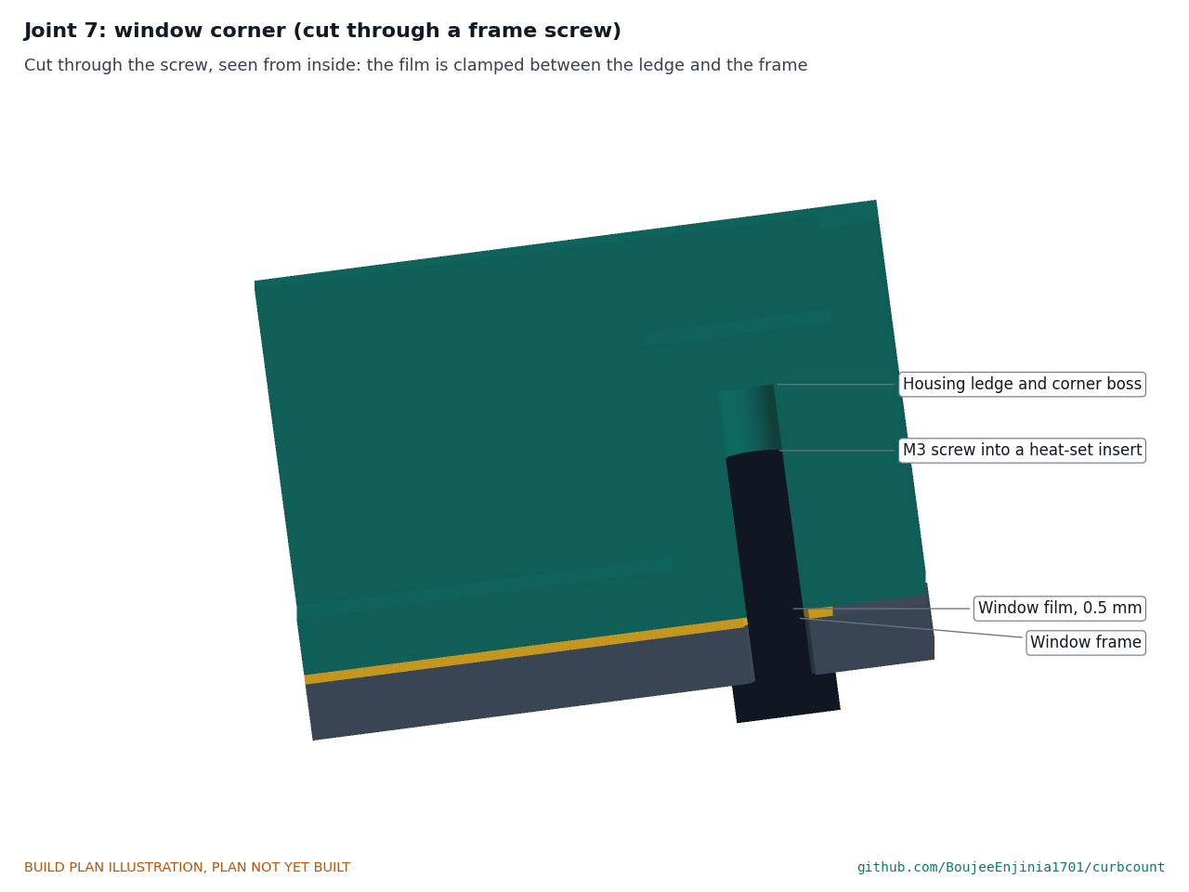
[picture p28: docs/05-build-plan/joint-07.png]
Figure 20. Joint 7: window corner


*Figure 20. Cut through a corner screw: the film is clamped between the housing's ledge and the frame; the M3 screw passes through the punched hole into the insert.*

The film lies on the ledge, the frame over it, and four M3 screws go up through the frame and film into the inserts, tightened evenly in a cross pattern until the film is flat. The array needs only about 30 x 20 mm of the 88 x 68 mm opening.

**Check before moving on.** The film is taut and flat, with no creases or marks in the opening.

### 3.9 Sleeve

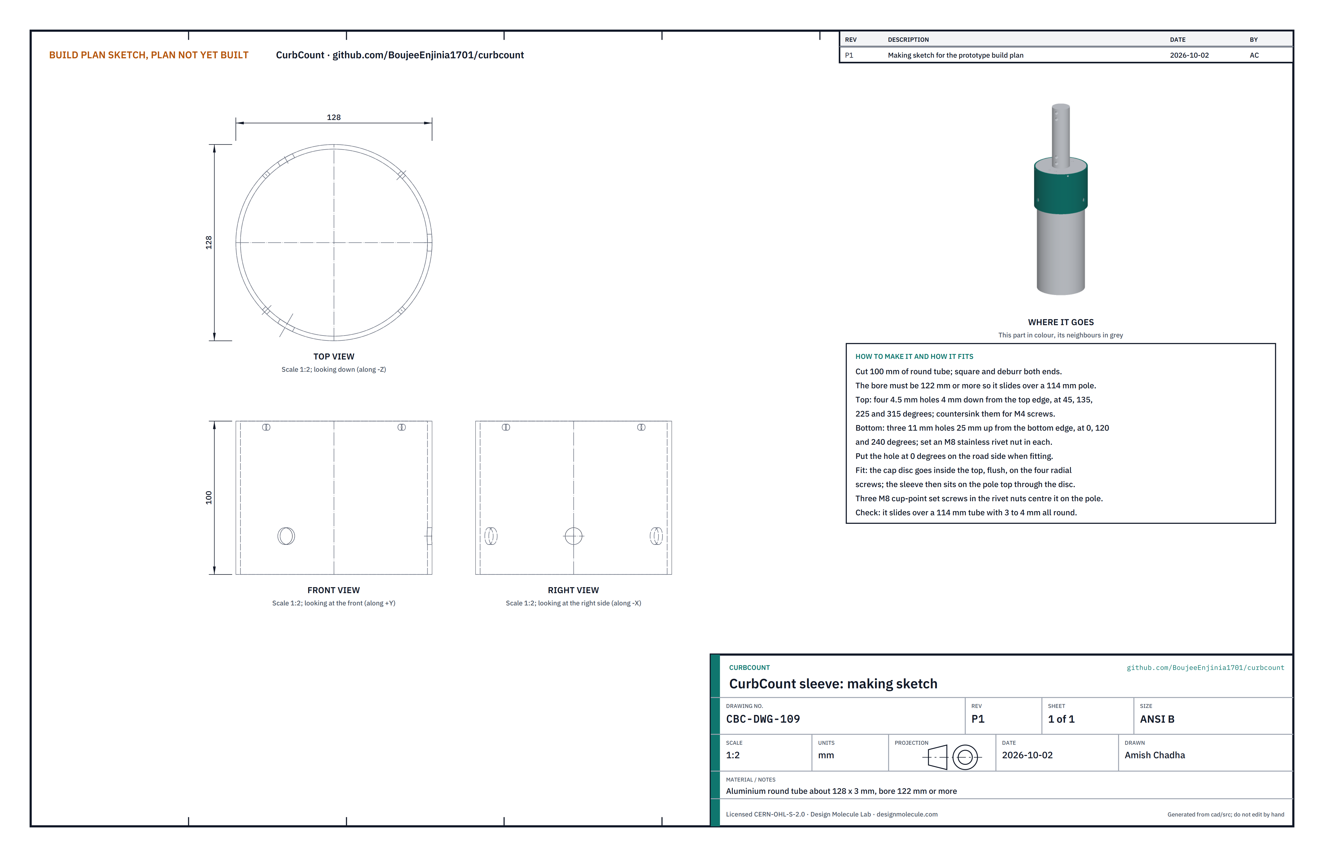
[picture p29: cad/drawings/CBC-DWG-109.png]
Figure 21. Making sketch of the sleeve


*Figure 21. Sleeve making sketch (CBC-DWG-109).*

**What it is and what it is made from.** The short tube that slips over the top of the pole and carries the panel mount. Aluminium round tube about 128 mm outside with a 3 mm wall; its bore must be 122 mm or more. Cut 100 mm long.

**How to make it.**

1. Cut 100 mm; square and deburr both ends.
2. Mark four points round the top edge at 45°, 135°, 225° and 315° (wrap a paper strip round the tube, mark it in quarters and offset by an eighth). Drill 4.5 mm, 4 mm down from the top edge, and countersink for M4.
3. Mark three points round the bottom at 0°, 120° and 240°, 25 mm up from the bottom edge. Drill 11 mm and set an M8 stainless rivet nut in each with a rivet nut tool.
4. Put a paint mark at 0°: it goes on the road side.

**How it fits the parts next to it.**

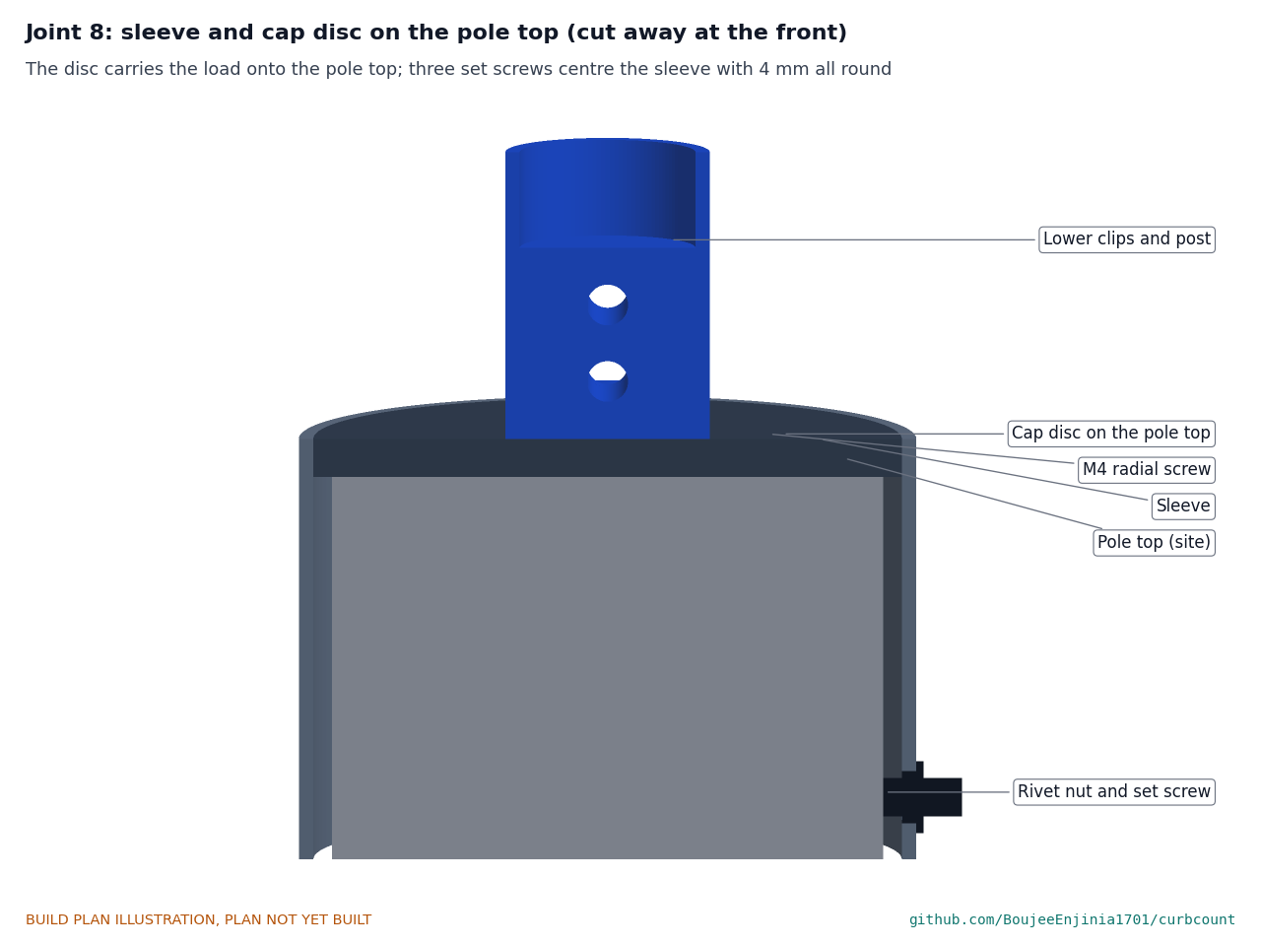
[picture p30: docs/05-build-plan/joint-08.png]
Figure 22. Joint 8: sleeve and cap disc on the pole top


*Figure 22. Cut away at the front: the cap disc sits on the pole top inside the sleeve; three set screws centre the sleeve with about 4 mm all round.*

The cap disc fits inside the sleeve's top, flush (section 3.10). On the pole, the disc carries the load onto the pole top and three M8 cup-point set screws in the rivet nuts centre the sleeve and stop it turning.

**Check before moving on.** The sleeve slides over a 114 mm tube with 3 to 4 mm all round, and each set screw turns freely in its rivet nut.

### 3.10 Cap disc

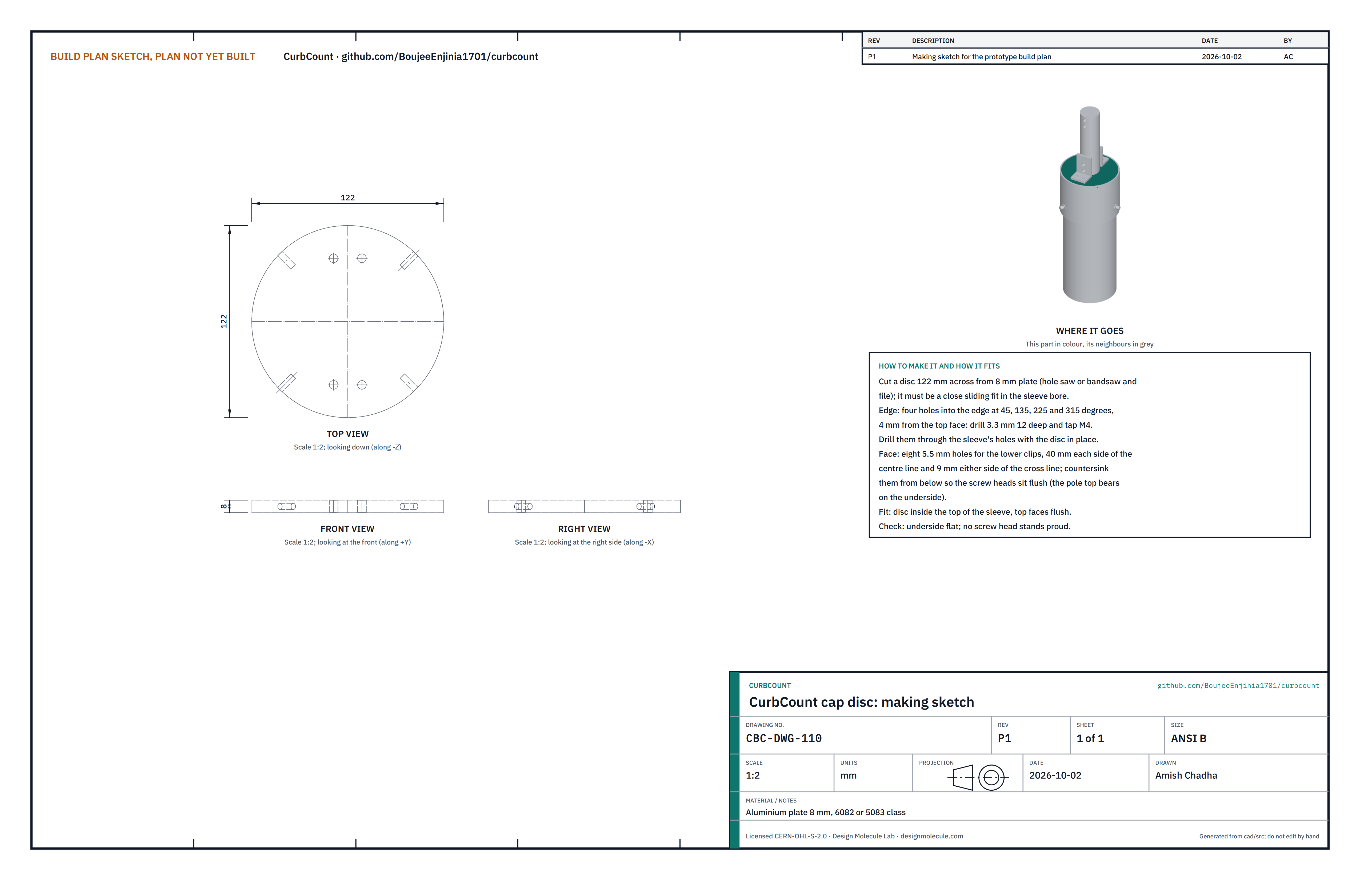
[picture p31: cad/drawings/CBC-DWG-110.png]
Figure 23. Making sketch of the cap disc


*Figure 23. Cap disc making sketch (CBC-DWG-110).*

**What it is and what it is made from.** The lid inside the sleeve top that rests on the pole top and carries the post. Aluminium plate 8 mm, 6082 or 5083 class, 122 mm across.

**How to make it.**

1. Cut a 122 mm disc (hole saw, or bandsaw and file); it must be a close sliding fit in the sleeve's bore.
2. Eight 5.5 mm holes for the lower clips: 40 mm each side of a centre line and 9 mm either side of the cross line. Countersink them from below so the screw heads sit flush: the pole top bears on the underside.
3. Push the disc into the sleeve's top, flush. Drill through the sleeve's four holes into the disc's edge, 3.3 mm and 12 deep, and tap M4. Fit four M4 countersunk screws.

**How it fits the parts next to it.** The disc's underside bears on the pole top; its top carries the two lower clips and the post's foot (Figure 26).

**Check before moving on.** The underside is flat and no screw head stands proud of it.

### 3.11 Post and post plugs (make 2 plugs)

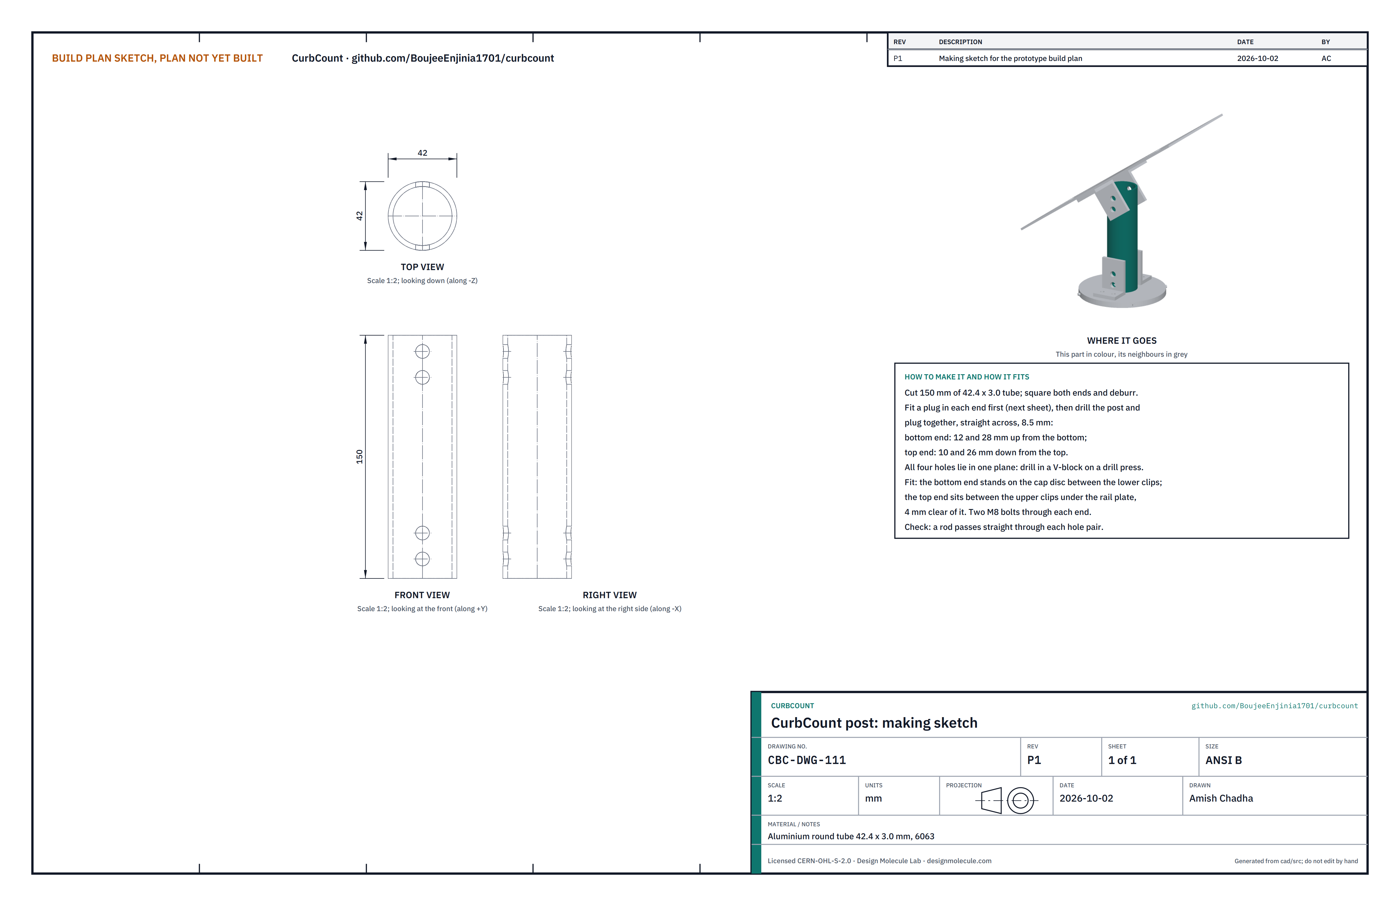
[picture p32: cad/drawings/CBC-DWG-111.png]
Figure 24. Making sketch of the post


*Figure 24. Post making sketch (CBC-DWG-111).*

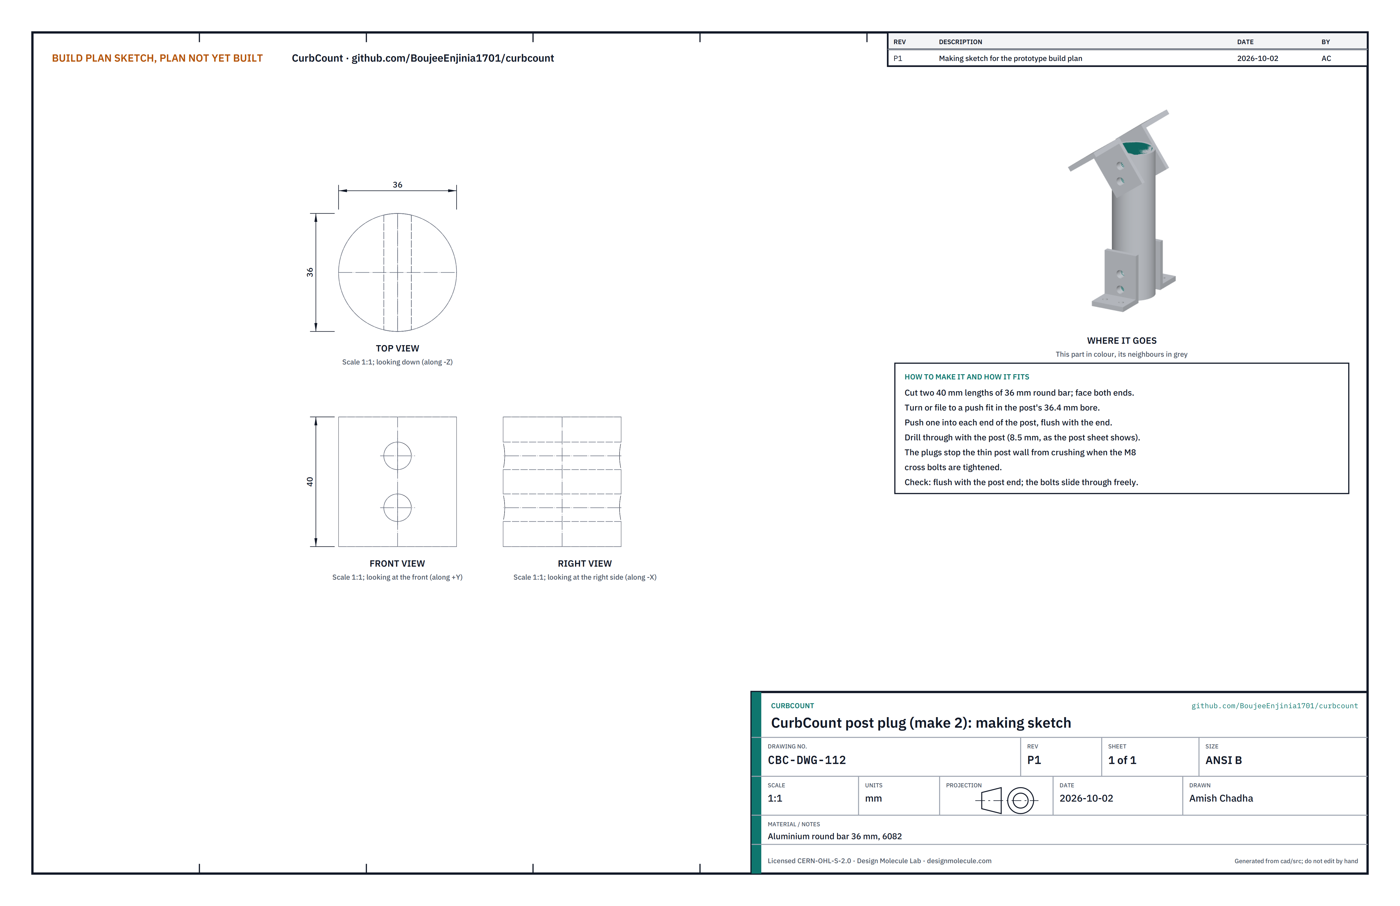
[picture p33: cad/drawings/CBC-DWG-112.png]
Figure 25. Making sketch of the post plug


*Figure 25. Post plug making sketch (CBC-DWG-112).*

**What it is and what it is made from.** The short column that lifts the panel above the pole top. Aluminium round tube 42.4 x 3.0 mm, 6063 class, 150 mm long, with a 40 mm plug of 36 mm aluminium round bar in each end so the thin wall does not crush under the bolts.

**How to make it.**

1. Cut the post 150 mm; square and deburr both ends.
2. Cut two plugs 40 mm long from 36 mm round bar; face both ends; file or turn to a push fit in the post's bore.
3. Push a plug into each end, flush.
4. With the post in a V-block on a drill press, drill straight across through post and plug, 8.5 mm: at the bottom end 12 and 28 up from the end; at the top end 10 and 26 down from the end. All four holes lie in one plane.

**How it fits the parts next to it.**

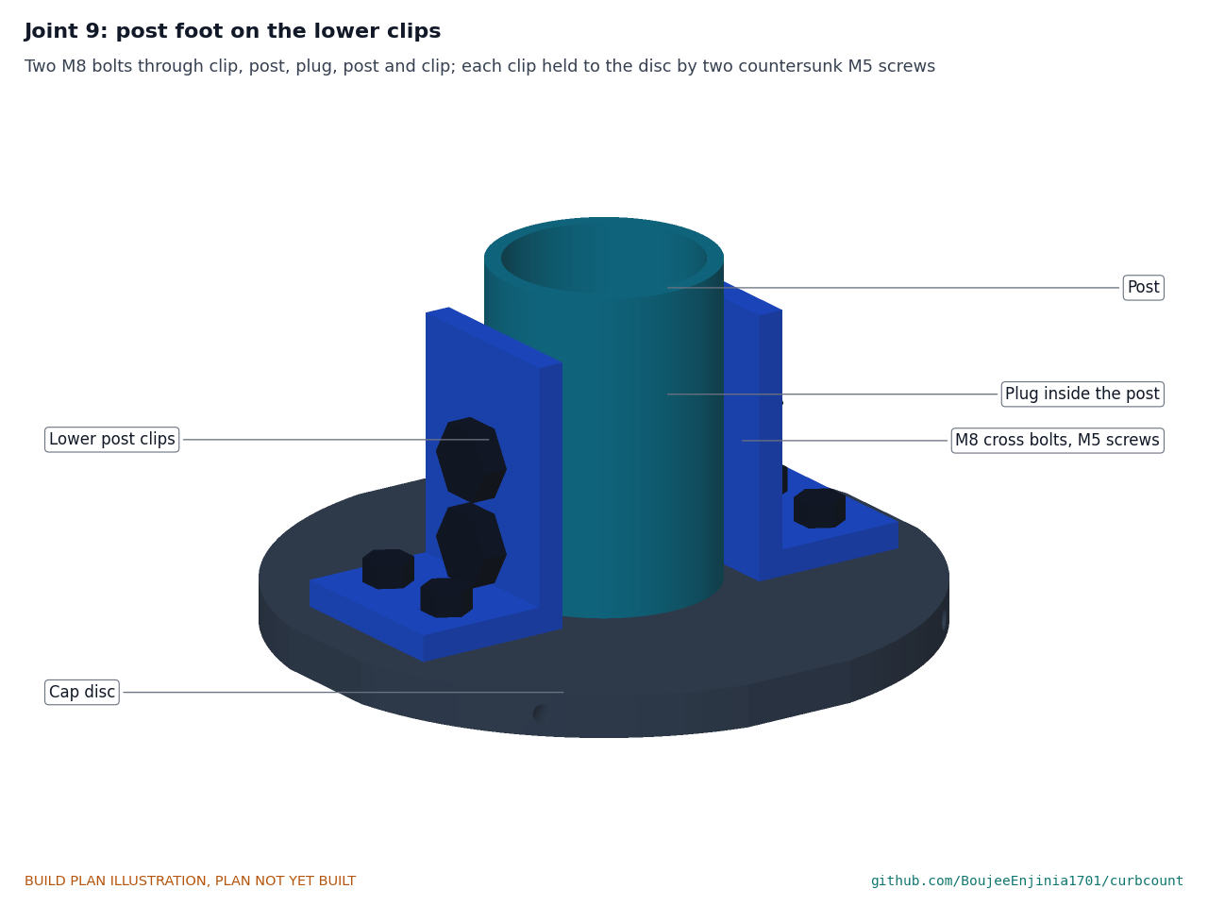
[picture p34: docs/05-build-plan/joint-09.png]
Figure 26. Joint 9: post foot on the lower clips


*Figure 26. The post stands on the cap disc between the two lower clips; two M8 bolts pass through clip, post, plug, post and clip.*

The foot stands on the cap disc between the lower clips (Figure 26); the head sits between the upper clips under the rail plate, 4 mm clear of it (Figure 30).

**Check before moving on.** A rod passes straight through each pair of holes.

### 3.12 Lower post clips (make 2)

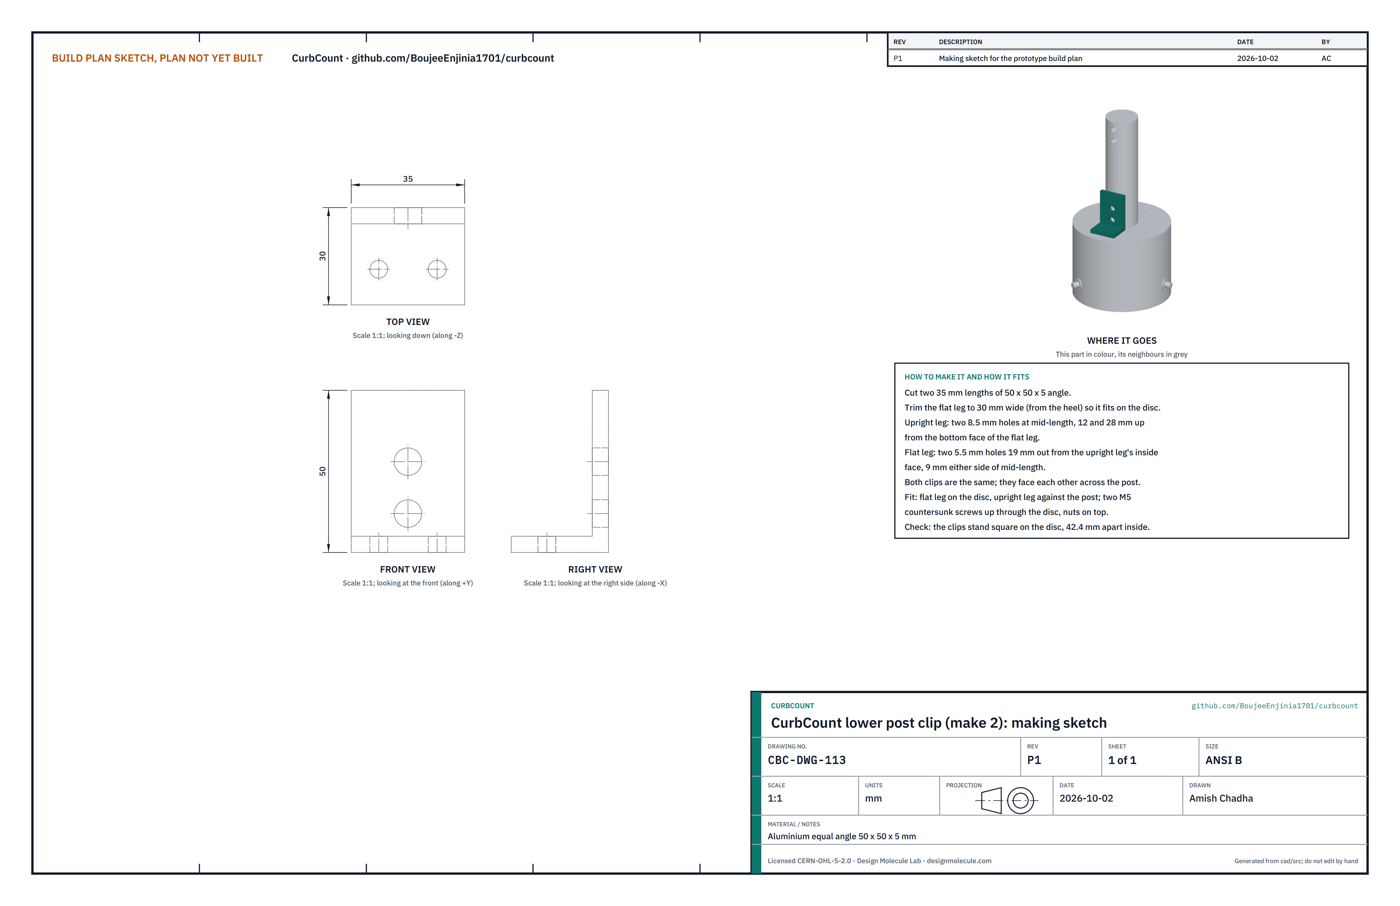
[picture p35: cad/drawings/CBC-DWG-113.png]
Figure 27. Making sketch of the lower post clip


*Figure 27. Lower post clip making sketch (CBC-DWG-113).*

**What it is and what it is made from.** A short angle that holds the post's foot on the cap disc. Aluminium equal angle 50 x 50 x 5 mm.

**How to make it.**

1. Cut two 35 mm lengths. Trim the flat leg of each to 30 mm wide from the heel so it fits inside the disc.
2. Upright leg: two 8.5 mm holes at mid-length, 12 and 28 up from the underside of the flat leg.
3. Flat leg: two 5.5 mm holes 19 out from the upright leg's inside face, 9 either side of mid-length.

**How it fits the parts next to it.** The flat leg lies on the cap disc, held by two M5 countersunk screws up through the disc with nyloc nuts on top; the upright leg stands against the post (Figure 26). The two clips face each other across the post.

**Check before moving on.** Both clips stand square to the disc, 42.4 mm apart inside.

### 3.13 Upper post clips (make 2) and rail plate

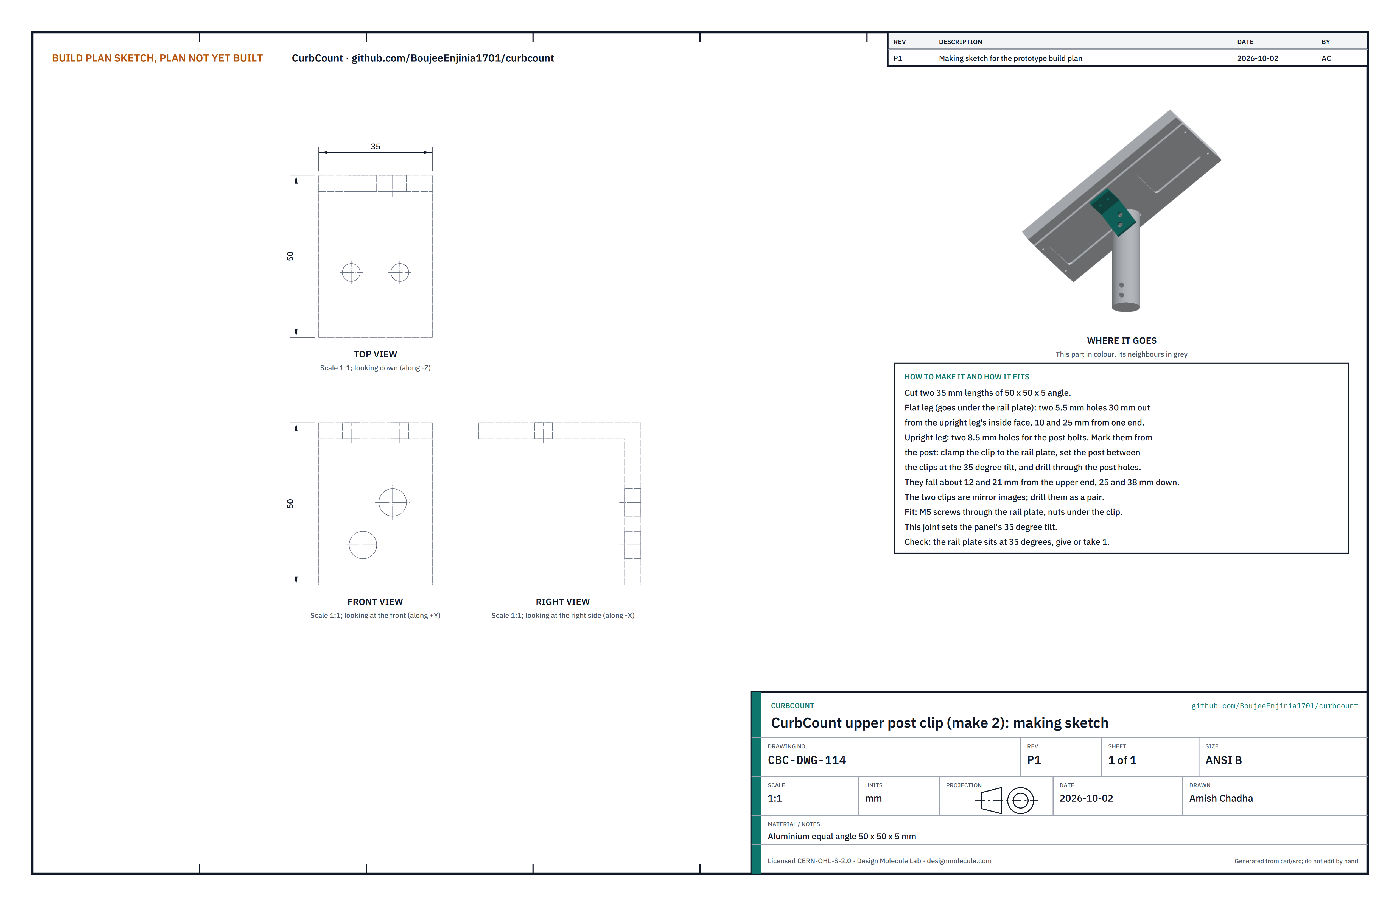
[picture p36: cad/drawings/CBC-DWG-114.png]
Figure 28. Making sketch of the upper post clip


*Figure 28. Upper post clip making sketch (CBC-DWG-114).*

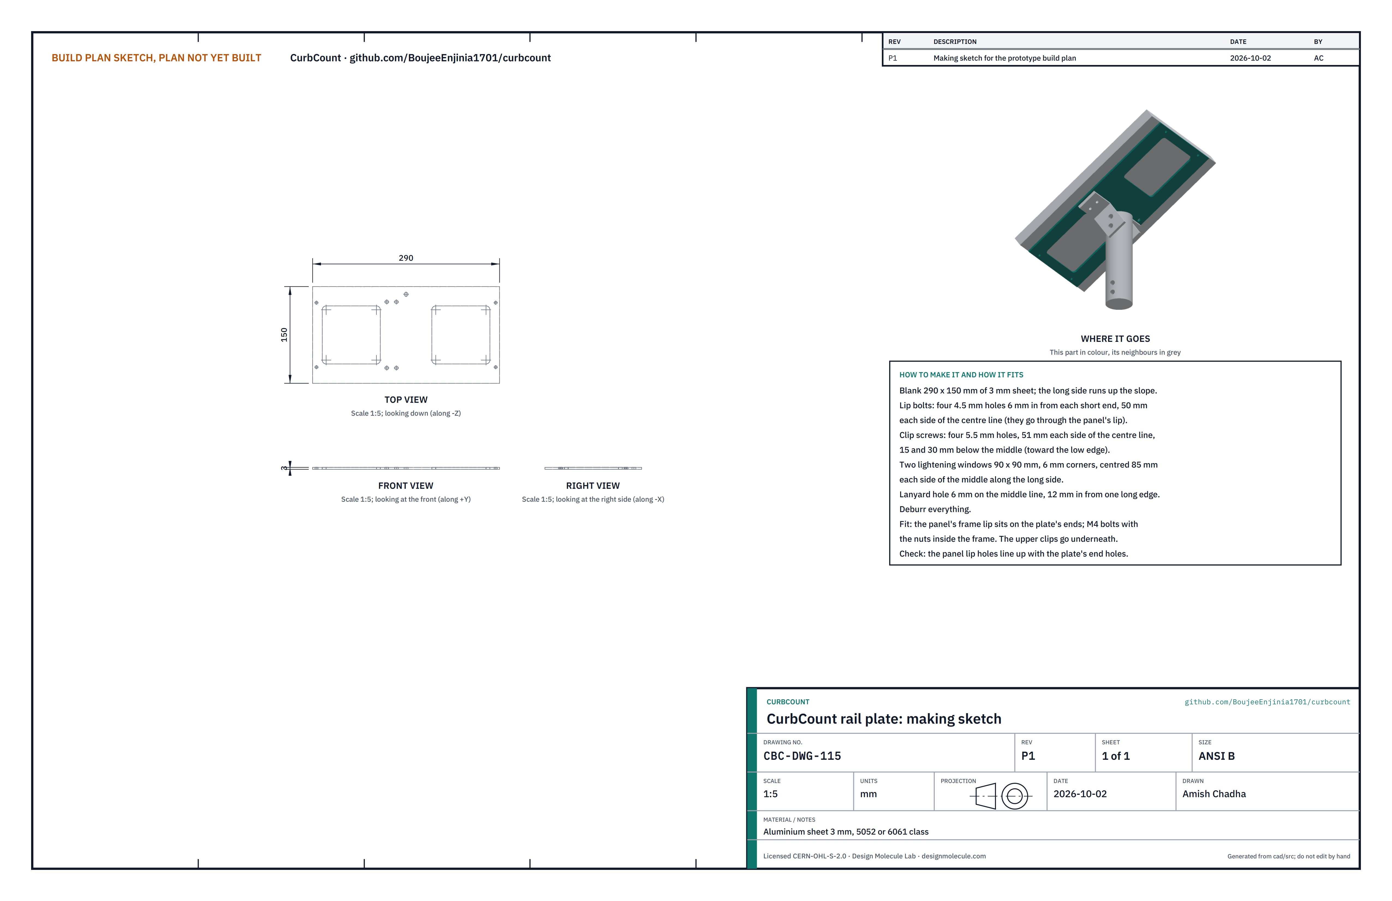
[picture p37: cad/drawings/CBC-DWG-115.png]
Figure 29. Making sketch of the rail plate


*Figure 29. Rail plate making sketch (CBC-DWG-115).*

**What they are and what they are made from.** The rail plate is the tilted plate the panel bolts to: aluminium sheet 3 mm, 290 x 150 mm, at 35° to level. The two upper clips hold it on the post's head and set the tilt: aluminium equal angle 50 x 50 x 5 mm.

**How to make them.**

1. Rail plate: cut 290 x 150 mm; the long side runs up the slope. Four 4.5 mm lip bolt holes 6 in from each short end, 50 each side of the centre line. Four 5.5 mm clip screw holes 51 each side of the centre line, 15 and 30 below the middle (toward the low edge). Two lightening windows 90 x 90 mm with 6 mm corners, centred 85 each side of the middle. A 6 mm lanyard hole on the middle line, 12 in from one long edge. Deburr.
2. Upper clips: cut two 35 mm lengths. In each flat leg, two 5.5 mm holes 30 out from the upright leg's inside face, 10 and 25 from one end. Screw both clips under the rail plate with M5 screws, nuts under the clips, upright legs 42.4 mm apart.
3. Set the drilled post between the clips with the rail plate at 35° (check with an angle finder) and the post's head 4 mm below the plate. Clamp, and drill the clips' upright legs 8.5 mm through the post's two top holes. The holes fall about 12 and 21 from the clips' upper ends, 25 and 38 down from the plate.

**How they fit the parts next to them.**

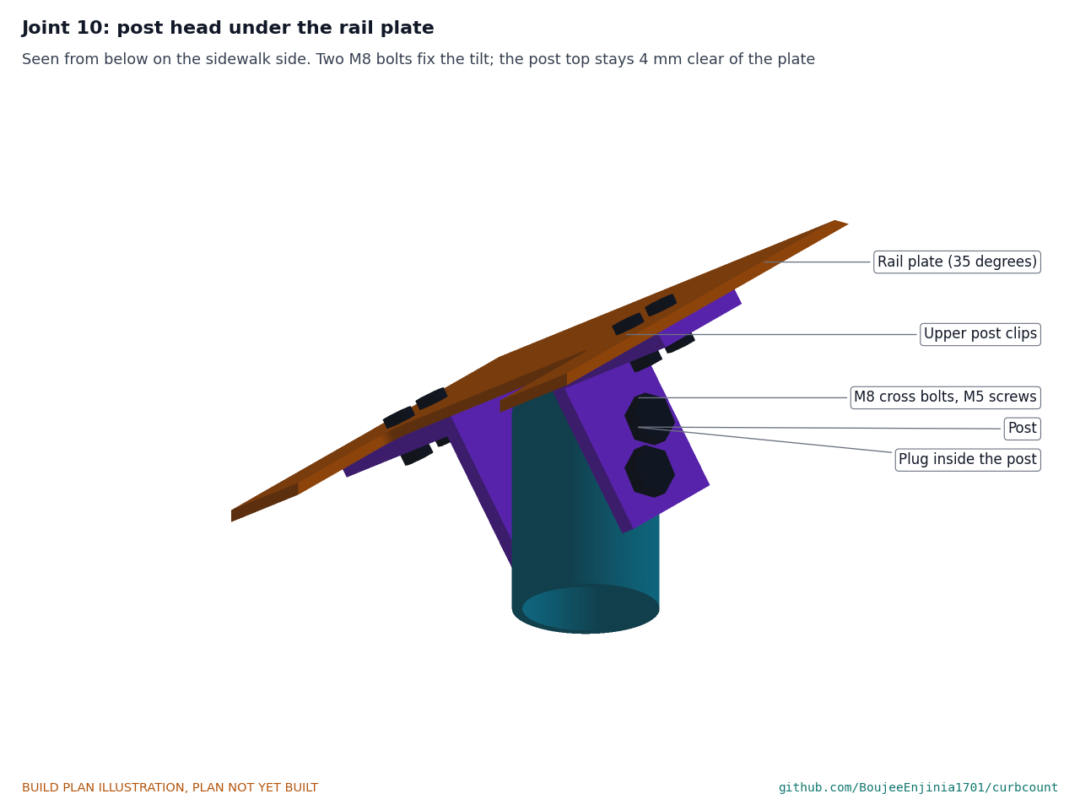
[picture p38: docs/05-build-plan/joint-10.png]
Figure 30. Joint 10: post head under the rail plate


*Figure 30. Seen from below: the upper clips are screwed under the rail plate and bolted through the post's head; the two bolts fix the 35° tilt.*

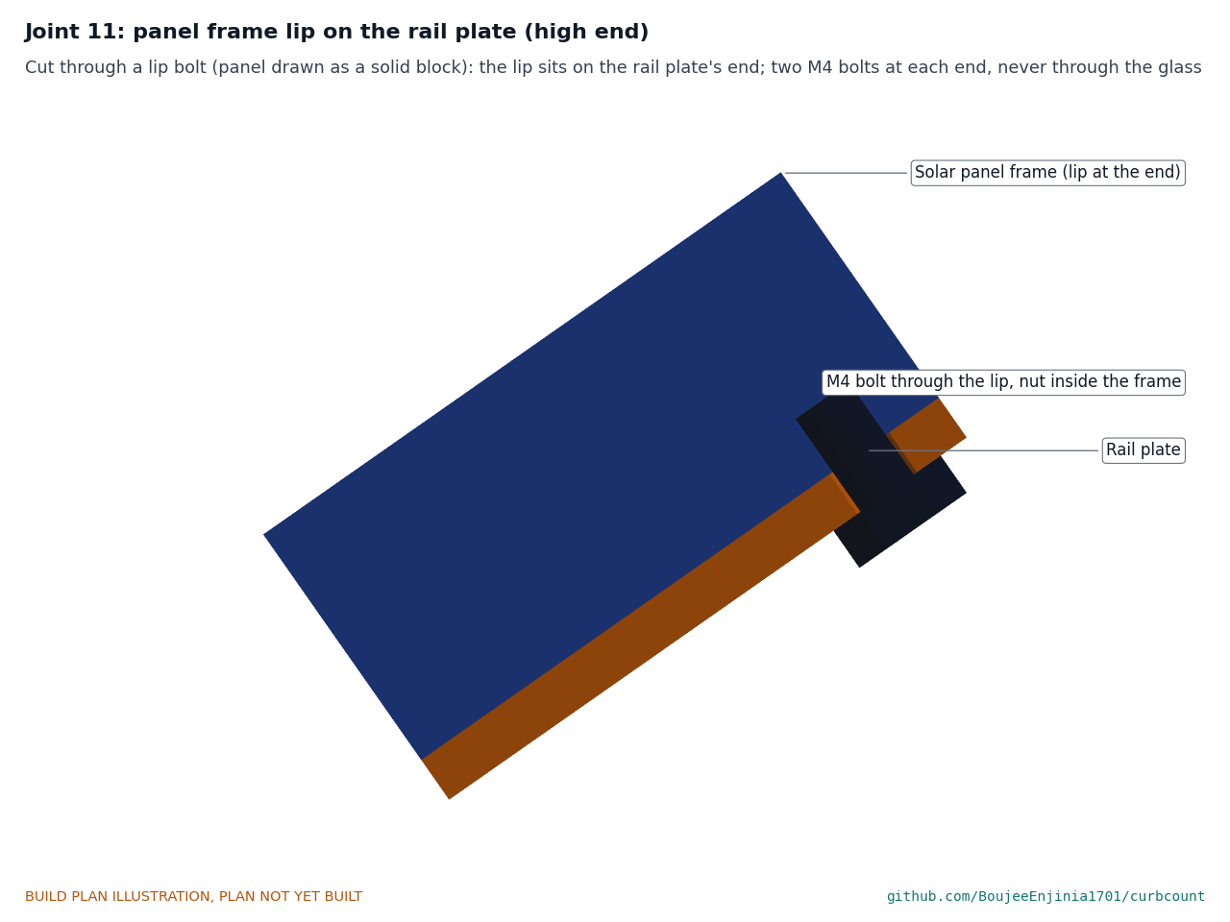
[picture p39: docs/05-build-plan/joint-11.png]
Figure 31. Joint 11: panel frame lip on the rail plate


*Figure 31. The panel frame's back lip sits on the end of the rail plate; two M4 bolts at each end, the nuts inside the frame, never through the glass.*

**Check before moving on.** The rail plate sits at 35°, give or take 1°, and the panel's lip holes line up with the plate's end holes.

### 3.14 Notice plate

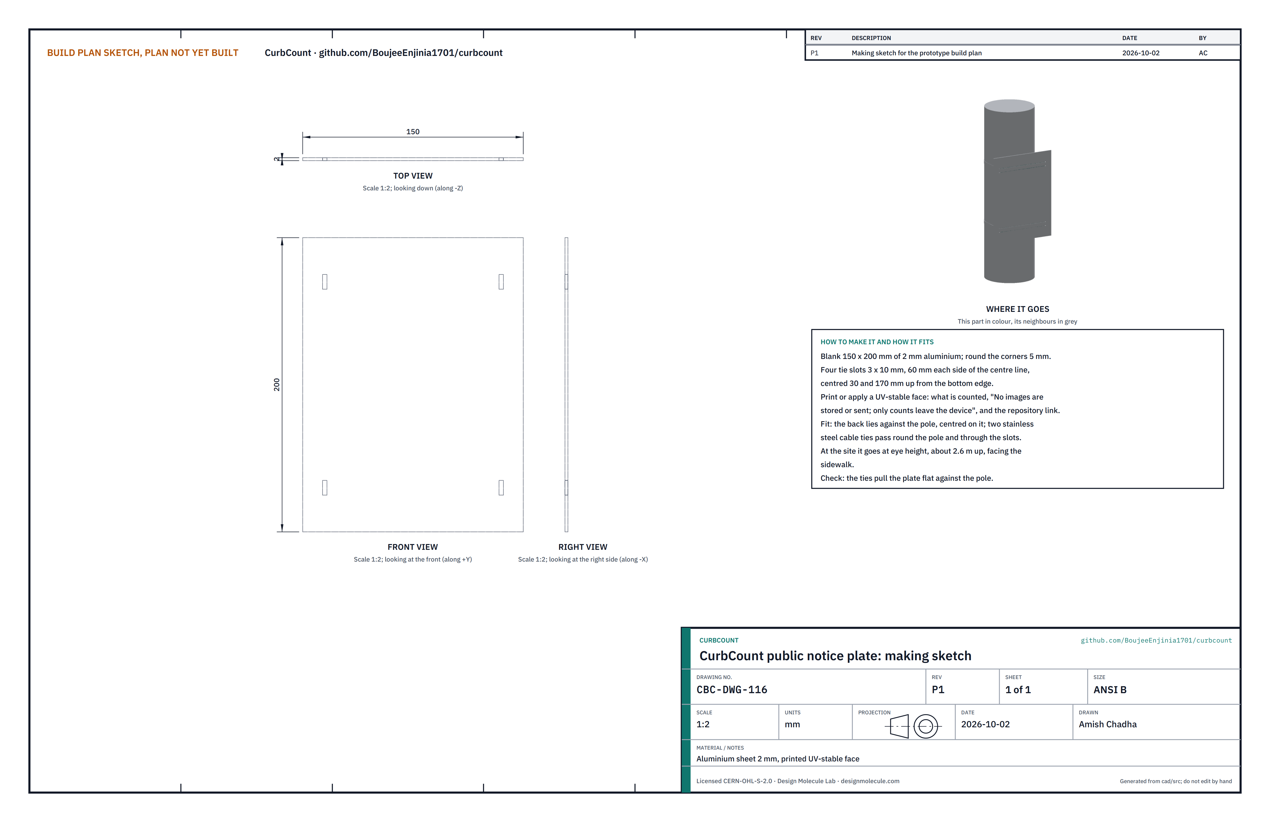
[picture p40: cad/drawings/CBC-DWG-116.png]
Figure 32. Making sketch of the notice plate


*Figure 32. Notice plate making sketch (CBC-DWG-116).*

**What it is and what it is made from.** The public notice: what is counted, "No images are stored or sent; only counts leave the device", and where the design is published. Aluminium sheet 2 mm, 150 x 200 mm, with a UV-stable printed face.

**How to make it.**

1. Cut 150 x 200 mm; round the corners 5 mm.
2. Four tie slots 3 x 10 mm, 60 each side of the centre line, centred 30 and 170 up from the bottom edge. Chain drill and file.
3. Print or apply the UV-stable face with the wording above.

**How it fits the parts next to it.**

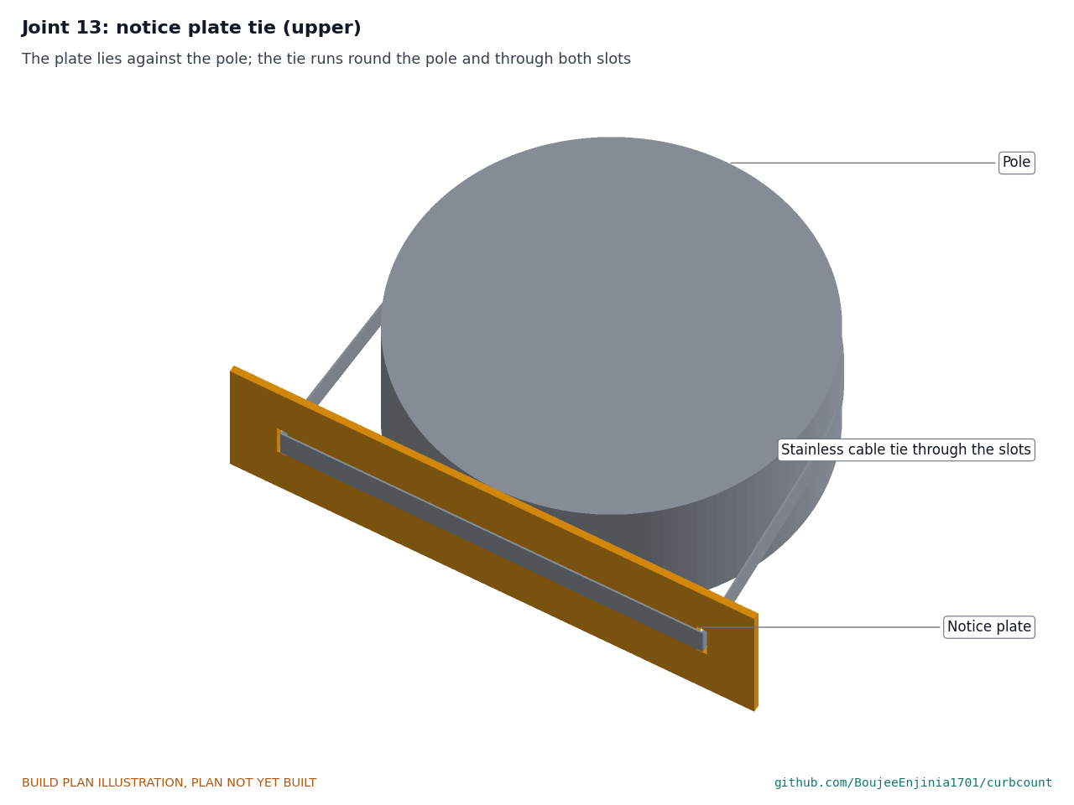
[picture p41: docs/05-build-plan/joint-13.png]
Figure 33. Joint 13: notice plate tie


*Figure 33. The plate lies against the pole; a stainless steel tie runs round the pole and through both slots.*

**Check before moving on.** The printed face reads correctly and is not scratched.

### 3.15 Cables

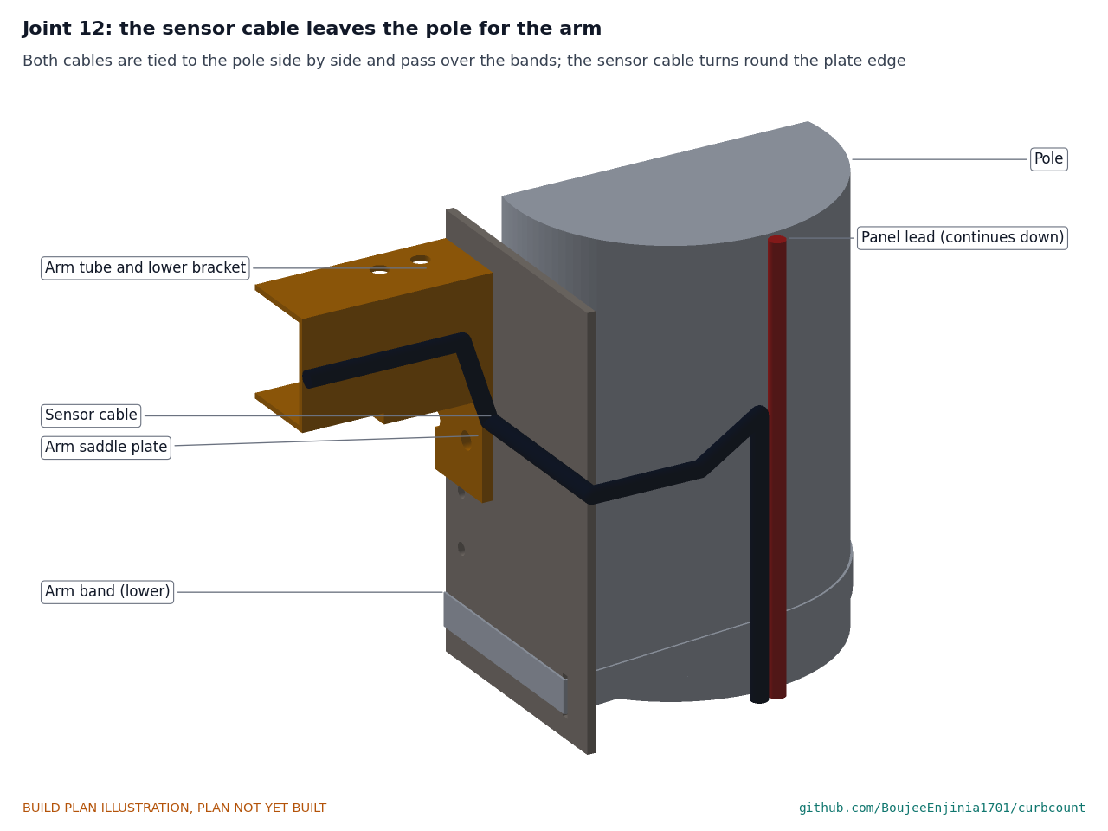
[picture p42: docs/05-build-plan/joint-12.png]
Figure 34. Joint 12: the sensor cable leaves the pole for the arm


*Figure 34. Both cables run up the pole's side, tied to it and over the bands; the sensor cable turns round the arm plate's edge, under the lower bracket and along the side of the arm.*

**What they are.** The sensor cable is a bought M12 5-pin cable, about 2 m, with a moulded plug at one end and open cores at the other; it runs from port A, up the pole, round the edge of the arm saddle plate, along the side of the arm, and into the head through the gland under the hood. The modelled run is 1.48 m. The panel extension lead is 1.5 m of two-core 0.75 mm² UV-rated cable with a sealed inline connector; it joins the panel's own 1 m lead at the post and runs down the pole into gland 1.

**What to do to them.** Pass the sensor cable's open end through the head gland, strip it back 30 mm, cut the fifth core back, and solder the other four to the array breakout's 3.3 V, ground, SDA and SCL pins as the port pinout gives them, with heat-shrink on every joint (Figure 11). Check each core with a meter from the plug's pins to the breakout's labels before soldering, not by wire colour. Fit the extension lead's inline connector to the panel lead, with the lead's other end stripped for the connector strip inside the enclosure.

**Check before moving on.** Every core continues end to end and no two cores touch.

### 3.16 Bought components

Buy to specification, not brand. Line numbers are those of the bill of materials.

- **FieldNode enclosure, glands, ports, vent, antenna and internal plate (line 1); power and radio modules (line 2); cell and fused holder (line 3); connector strip and rail fuses (line 14).** As FieldNode's build plan, section 3.10.
- **Solar panel (line 4).** 6 W monocrystalline, 9 V class, about 290 x 200 x 17 mm, aluminium frame with a flat back lip at least 12 mm wide at its short ends, 1 m lead.
- **Band clamps (line 6).** Four 12 mm stainless worm-drive band clamps that close on the loop for the site pole: about 470 mm on a 114 mm pole (about 330 mm on 60 mm, 545 mm on 140 mm).
- **Thermal array (line 10).** MLX90640 class, 32 x 24 pixels, 110 x 75° lens, on an I²C breakout with four mounting holes.
- **Window film (line 9).** 0.5 mm unpigmented HDPE sheet.
- **Sensor cable (line 11).** M12 5-pin A-coded, single-ended, about 2 m, PUR, 6 mm, IP67.
- **Notice plate ties (line 12).** Two stainless steel cable ties 8 mm wide, at least 500 mm long.
- **Fixings and sundries (line 13).** Stainless: 8 x M4 x 8 countersunk screws (V-saddles); 4 x M4 x 10 countersunk screws (cap disc); 6 x M6 x 20 hex bolts with nyloc nuts and 2 x M6 x 60 with nyloc nuts (arm); 2 x M5 x 50 hex bolts (head); 4 x M3 x 10 screws; 4 x M3 and 2 x M5 heat-set inserts; 4 x M2.5 x 6 screws (array); 3 x M8 rivet nuts and 3 x M8 x 25 cup-point set screws; 4 x M8 x 65 bolts with nyloc nuts (post); 4 x M5 x 20 countersunk screws and 4 x M5 x 16 screws with nyloc nuts (clips); 4 x M4 x 12 bolts with nuts (panel lip); four crush spacers (10 mm aluminium tube); an M16 cable gland for 4 to 8 mm cable; a 40 x 40 mm plastic end cap; the panel extension lead; two stainless wire-rope lanyards about 1 m long with ferrules; UV-stable cable ties; medium threadlocker; FieldNode's hardware set.

## 4. Putting it together

In each picture the parts already fitted are grey and the part being fitted is in colour, with an arrow showing the way it goes in. Steps 1 to 12 are done on the bench. Steps 13 to 17 are done on a 2 m length of 114.3 mm steel tube standing upright in a heavy base, which stands in for the street pole; measure the heights on it down from its top, which stands in for the pole top.

### Step 1: V-saddles onto the enclosure saddle plate

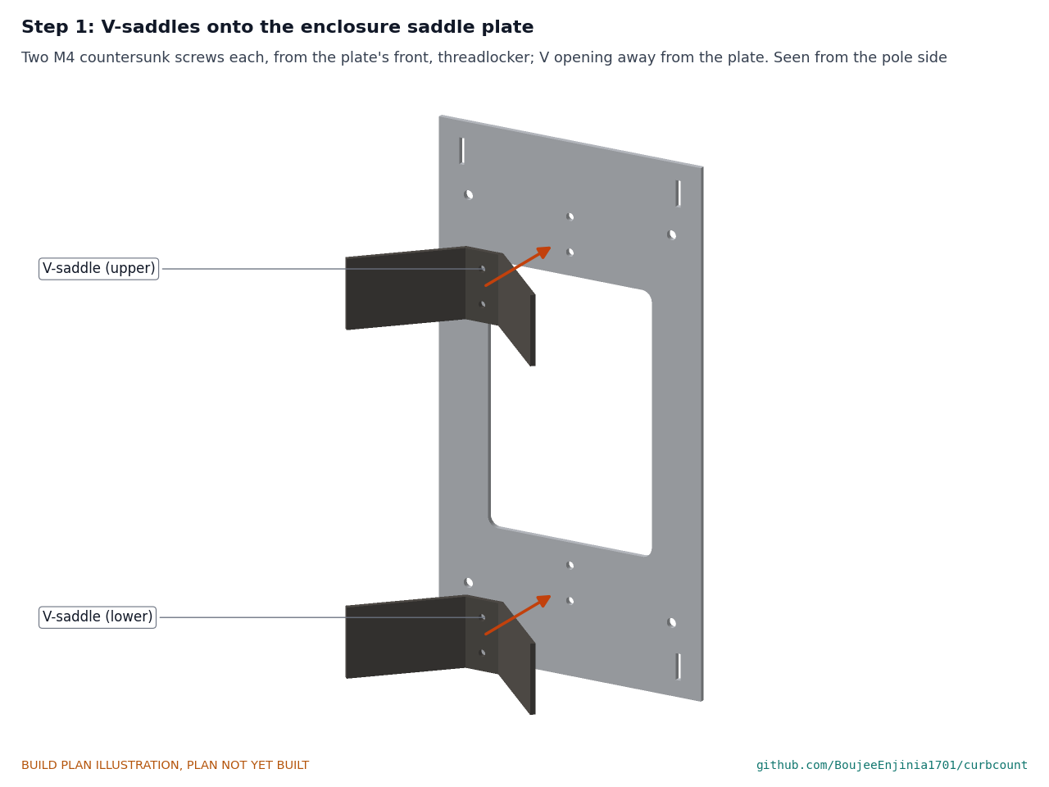
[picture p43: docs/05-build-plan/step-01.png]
Step 1


Two M4 countersunk screws each, from the plate's front, with medium threadlocker. The V opens away from the plate. File the screw tails flush with the saddle flats.

### Step 2: build the FieldNode core

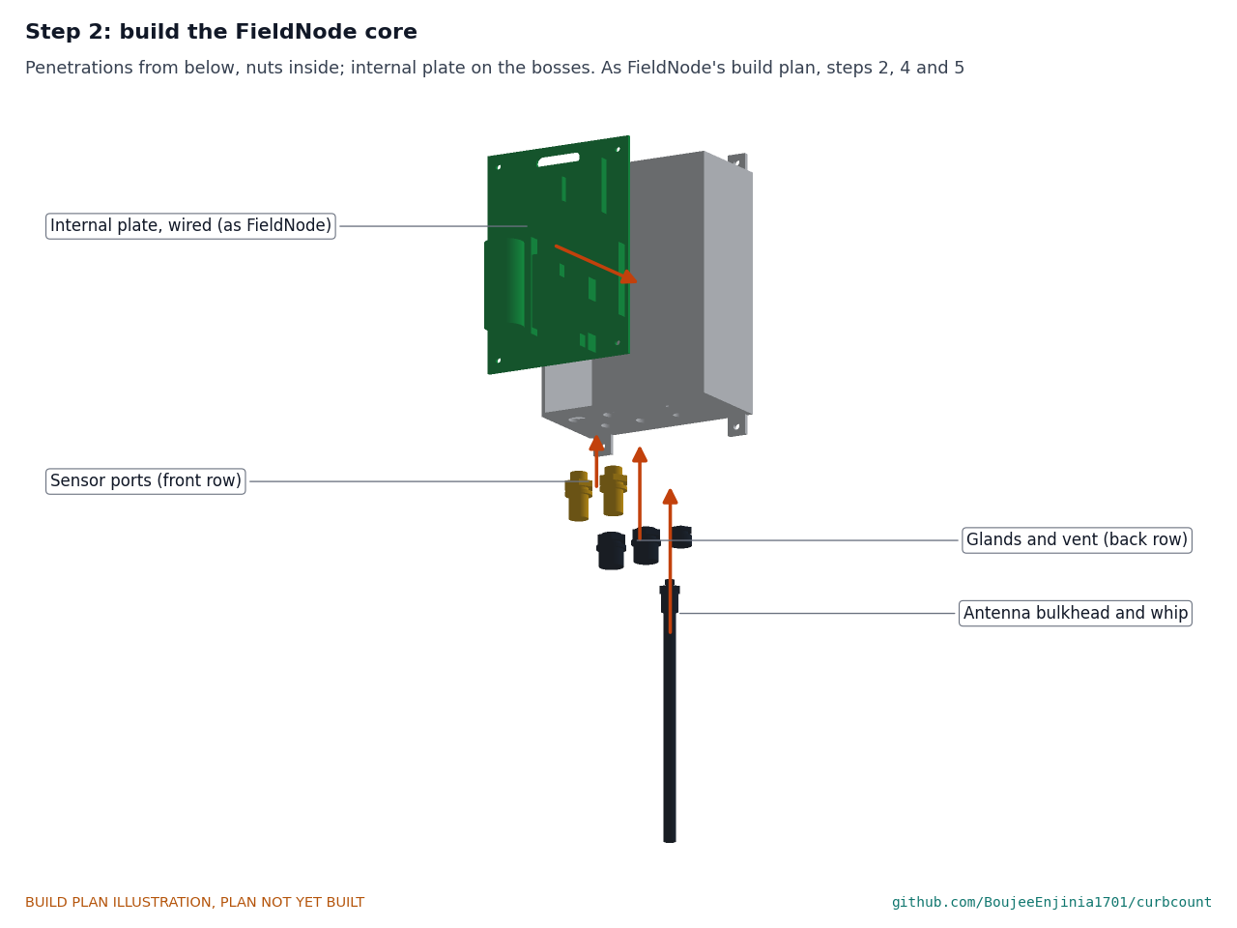
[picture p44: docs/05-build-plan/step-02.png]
Step 2


Glands, vent, ports and antenna into the bottom face, sealing washers outside and nuts inside; internal plate on its bosses, wired, cell out and fuse out; desiccant; lid closed. All as FieldNode's build plan, steps 2, 4, 5 and 6. **Hold point:** FieldNode's wiring checks pass.

### Step 3: enclosure onto the saddle plate

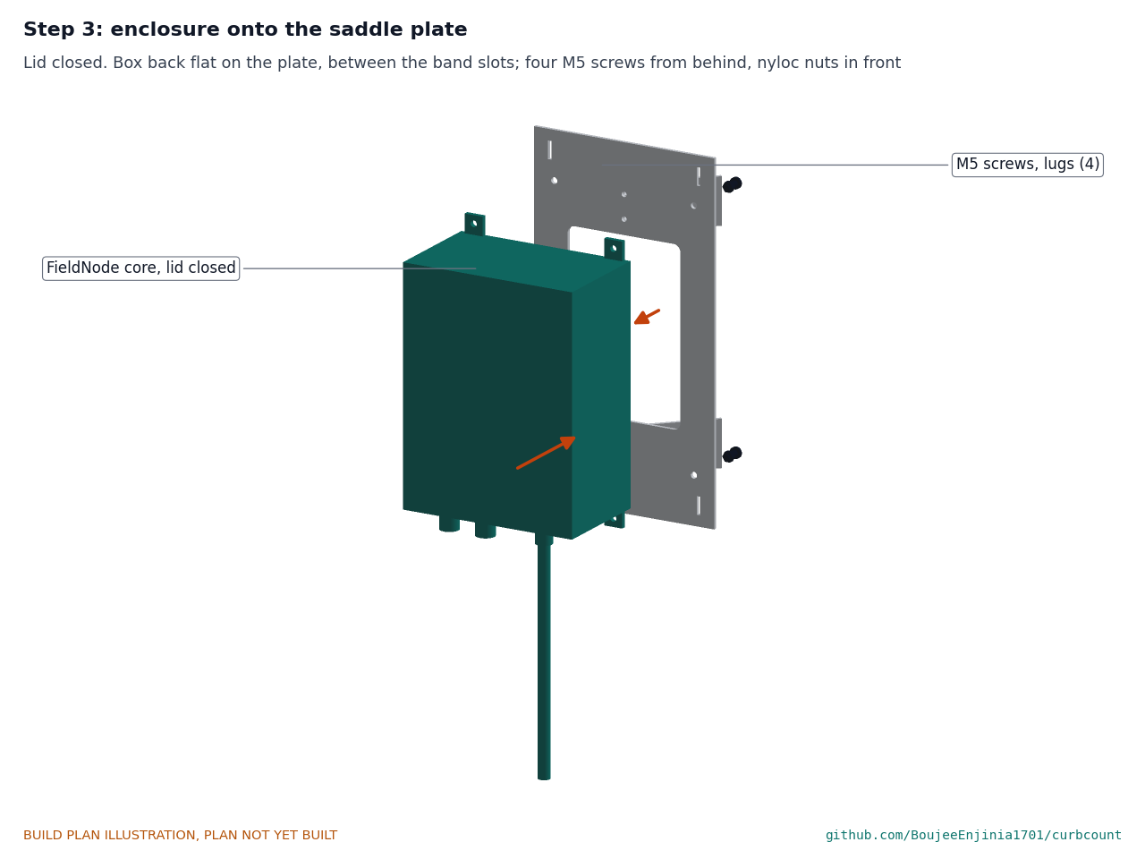
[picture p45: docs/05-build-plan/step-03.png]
Step 3


Hold the box's back flat on the plate's front, centred over the window and between the band slots, lid outward. Four M5 button-head screws through the lugs from behind the plate, nyloc nuts in front, snug.

### Step 4: V-saddles onto the arm saddle plate

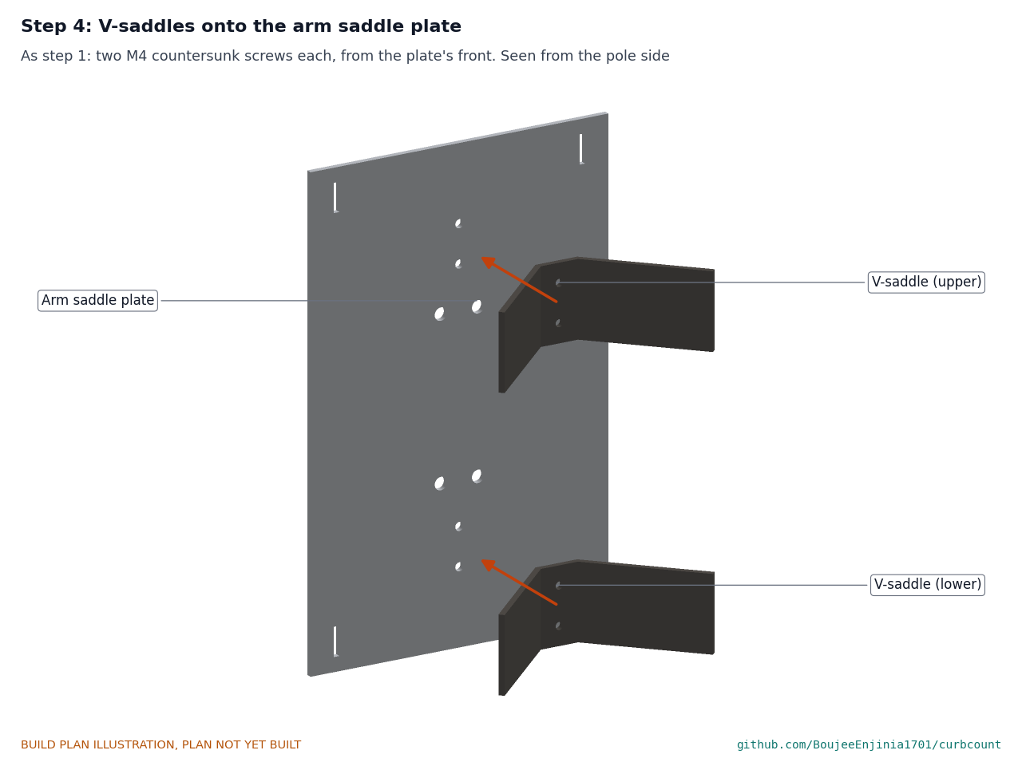
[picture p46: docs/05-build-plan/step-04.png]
Step 4


As step 1.

### Step 5: arm tube and brackets onto the arm plate

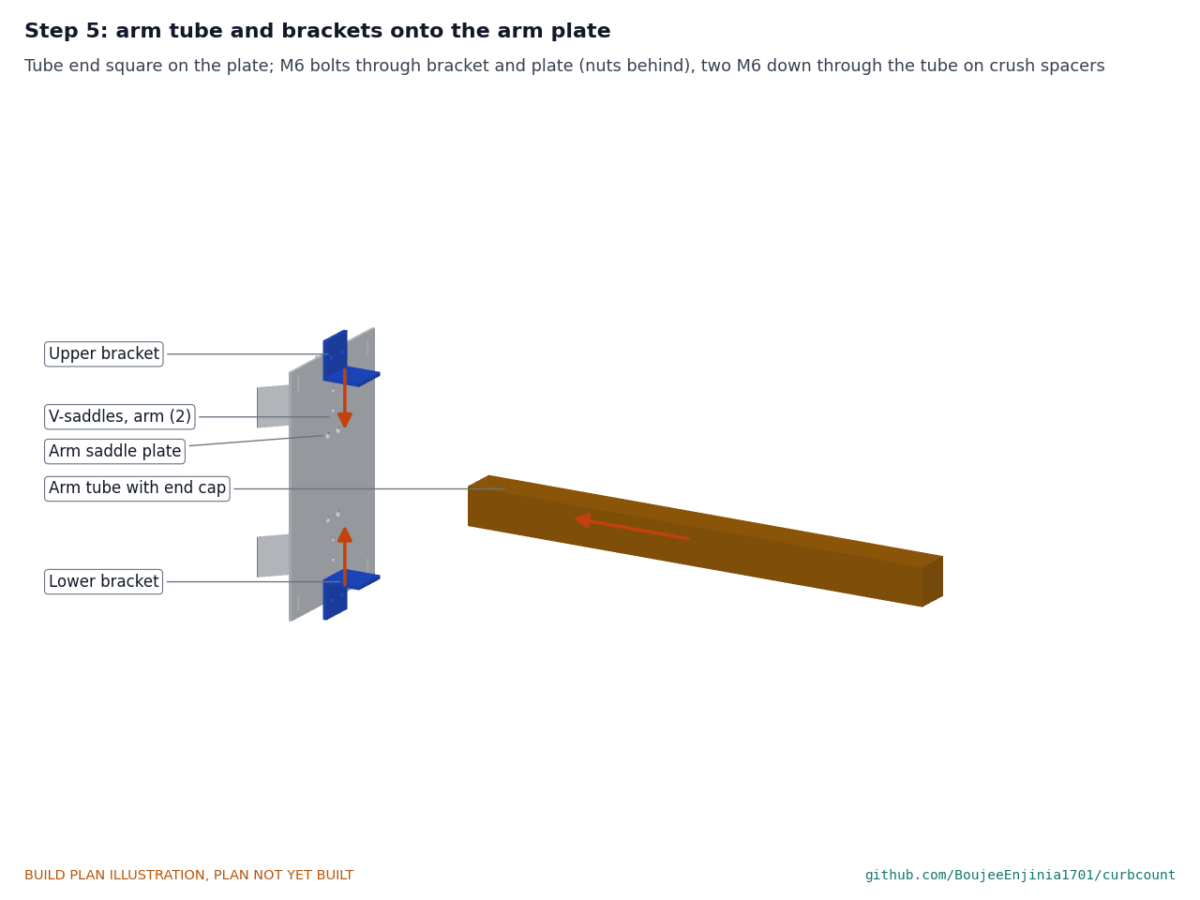
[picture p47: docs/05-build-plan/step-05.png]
Step 5


Stand the tube's square end on the plate's front at mid height. Upper bracket on top of the tube and lower bracket underneath, heels in the corners. Four M6 x 20 bolts through the brackets' upright legs and the plate, nuts behind; then two M6 x 60 bolts down through the upper bracket, the tube (with a crush spacer inside on each) and the lower bracket. Check the tube is square to the plate with a square, then tighten all six.

### Step 6: array and gland into the head

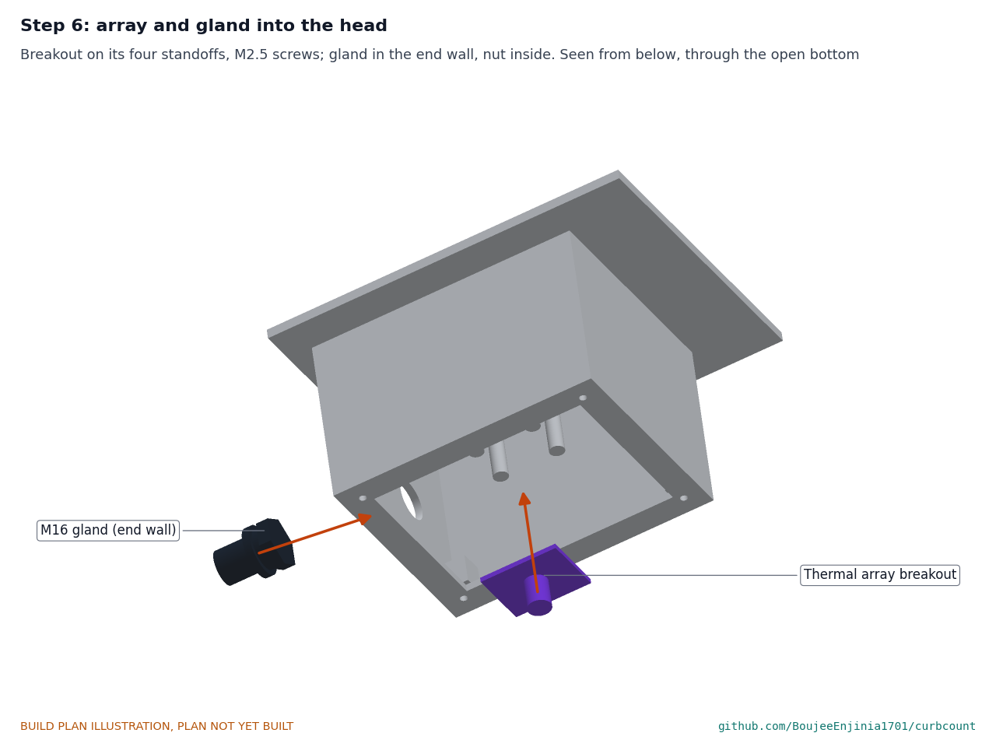
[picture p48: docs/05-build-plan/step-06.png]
Step 6


Array breakout on the four standoffs, lens down, on four M2.5 screws; gland into the end wall, nut inside. Pass the sensor cable's open end through the gland and solder it to the breakout (section 3.15) before step 7, then tighten the gland's dome on the cable.

### Step 7: window film and frame onto the head

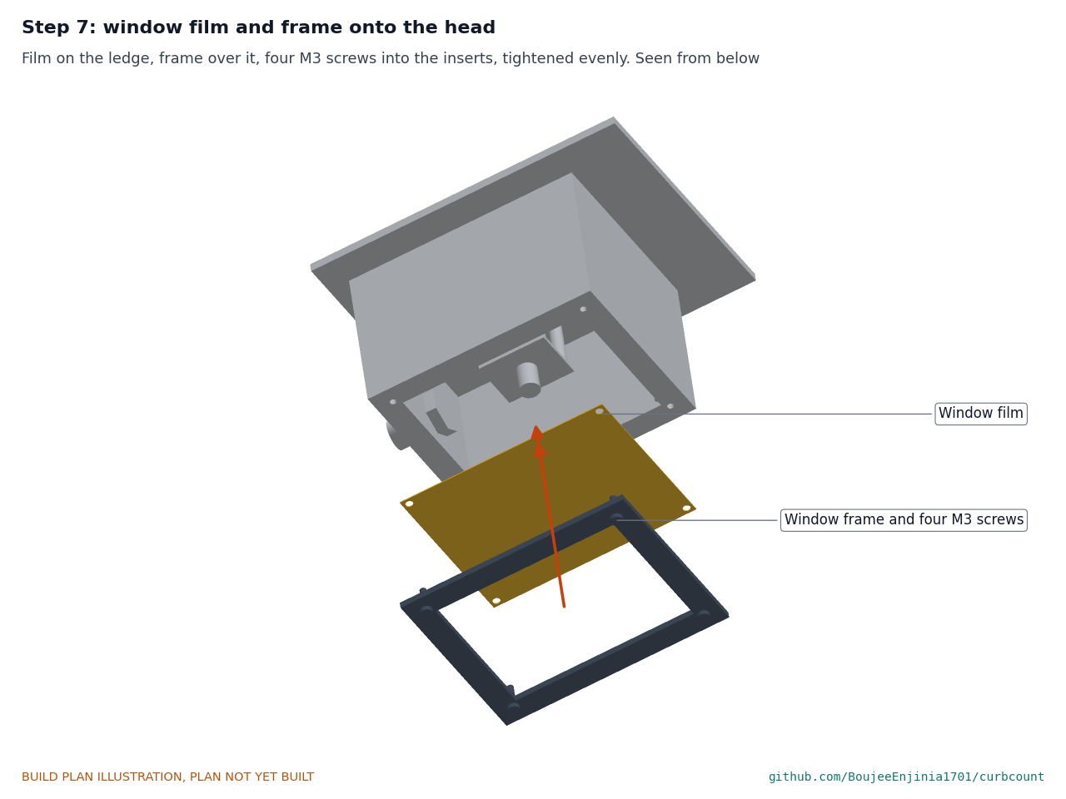
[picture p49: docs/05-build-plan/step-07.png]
Step 7


Film on the ledge, frame over it, four M3 screws into the inserts, tightened evenly in a cross pattern until the film is flat.

### Step 8: head onto the arm

Step 8

With the arm assembly on its back on the bench, hold the head's wedge pad up against the underside of the arm's far end, end cap toward the road. Put the two crush spacers into the tube at the head-end holes, then two M5 x 50 bolts down through the arm into the inserts, snug: the inserts are in plastic, so do not overtighten. Clip the head lanyard through the hood's hole now; it is tied to the pole in step 16.

### Step 9: cap disc into the sleeve

Step 9

Rivet nuts already set. Disc into the top of the sleeve, flush; four M4 countersunk screws through the sleeve into the disc's edge.

### Step 10: lower clips and post onto the disc

Step 10

Each clip on two M5 countersunk screws up through the disc, nyloc nuts on top. Stand the post between the clips and fit two M8 bolts through clip, post and clip, nyloc nuts, tight.

### Step 11: rail plate onto the post

Step 11

The upper clips are already screwed under the rail plate (section 3.13). Lower the clips over the post's head and fit two M8 bolts, nyloc nuts, tight. The rail plate leans 35°, its low edge on the sidewalk side, away from the sleeve's paint mark.

### Step 12: panel onto the rail plate

Step 12

Lay the panel's frame lip on the rail plate's ends, panel face up, junction box clear of the clips. Drill the lip through the plate's end holes if it is not already drilled, keeping well clear of the glass, and fit four M4 bolts with the nuts inside the frame. Tie the panel's lead down the post with UV-stable ties.

### Step 13: enclosure assembly onto the pole

Step 13

On the stub, the plate's centre goes 1,300 mm below the top. Hold the plate with both saddles against the pole. Pass each band round the pole, through its two slots and across the plate's front (the upper band above the box, the lower band below it), worm drive on the road side of the pole where a screwdriver reaches it. Tighten both to the band maker's torque and record it.

### Step 14: arm assembly onto the pole

Step 14

On the stub, the arm's axis goes 747 mm below the top, on the side opposite the enclosure. Band it as step 13. Before the final tightening, turn the arm square to the street (at the site) or square to the enclosure (on the stub), and level it within 1° with a spirit level on the tube.

### Step 15: pole-top mount onto the pole top

Step 15

With a helper, lower the mount over the pole top until the disc sits on it. Turn the panel toward the equator (on the stub, toward the enclosure side). Tighten the three set screws evenly with a hex key so the sleeve sits centred, then add threadlocker. Pass the panel lanyard through the rail plate's hole and round the pole below the sleeve; close it with a ferrule.

### Step 16: sensor cable and panel lead

Step 16

Seen from the street. Plug the sensor cable into port A. Run it under the enclosure plate to the pole's side, up the pole, round the edge of the arm plate, under the lower bracket and along the side of the arm to the head (Figure 34). Run the panel extension lead from the panel's inline connector down the same side of the pole, beside the sensor cable, to gland 1, and into the connector strip. Tie both to the pole every 150 mm with UV-stable ties, over the bands, never under them. Leave a drip loop below each entry. Tie the head lanyard round the pole above the arm plate.

### Step 17: public notice plate

Step 17

Back of the plate against the pole, face outward (at the site, at eye height, about 2.6 m up, facing the sidewalk; on the stub, below the enclosure). Pass each tie round the pole and through its two slots, pull tight and cut the tail flush.

## 5. First checks

These are the checks a TRL 4 test report would record; this plan only lists them. Requirement numbers are those of CBC-REQ-001.

*Table 2. First checks.*

| Check | Requirement | How | Pass when |
| --- | --- | --- | --- |
| Saddles seat on the pole | R12 | Fit each saddle plate to 60, 114 and 140 mm tubes before banding | Both wings of both saddles touch the tube; the plate does not rock |
| Band torque | R12 | Torque screwdriver on each band | The maker's torque is reached without the band slipping; value recorded |
| Arm level and square | R6 | Spirit level and square on the arm | Level and square within 1°; the window is 4.3 m above the road when installed |
| Head and window | R4, R10 | Look at the film and frame; shine a lamp from inside | Film taut and flat; light shows only through the opening, not at the frame edges |
| FieldNode core | R8, R9 | FieldNode's first checks: charge voltage, charge stops, rail switching | All pass as FieldNode's build plan states |
| Array over the cable | R1, R4 | Controller reads frames over the 2 m cable at 16 subpages a second with the calibration jumper fitted, shown on a laptop through the service port only | Frames read without errors for 10 minutes; nothing is stored or sent by radio |
| Count record and uplink | R5, R15 | Run the counting firmware sketch; watch the gateway | One 10-byte record every 15 minutes, no frame data |
| Sealing | R10 | Look at every gland, the gasket and the window seal under a lamp | Washers evenly squeezed; gland domes tight on their cables (the spray test comes later) |
| Mass | R11 | Weigh each group before it goes on the stub | 5.3 kg or less in all (5.26 kg estimated) |
| Mount and wind | R12 | Push on the panel corners and the head by hand | Nothing moves at any joint; lanyards fitted |
| Install time | R12 | Time steps 13 to 17 with two people | 60 minutes or less |

## 6. Safety stops

Stop at each point. Carry on only when everything listed is true.

- **S1. Before the cell comes into the workshop.** FieldNode's stops S1 to S5 apply in full: cell voltage and condition checked, a datasheet, fuse out, a charging spot on a non-combustible surface with an extinguisher for electrical fires.
- **S2. Before the cell goes in.** The core's wiring checks pass with the cell out and the fuse out; the sensor cable's cores are checked to the breakout's labels; nothing on the port A rail is shorted to ground.
- **S3. Before the radio transmits.** The antenna is connected and matches the region's band.
- **S4. Before anything goes on the stub.** The stub stands in a base that cannot tip under 5.3 kg at 2 m with a 0.06 m² panel at the top (a steel base plate at least 600 x 600 mm bolted to the floor, or two wall clamps). Work from a stable step platform, not a ladder leaning on the stub. Every bolt has a nyloc nut or threadlocker; the panel glass is whole; all edges are deburred.
- **S5. Before any frame is looked at.** Frames are shown only on a laptop through the calibration jumper on FieldNode's service header, never stored and never sent by radio. Do not point the head at people who have not been told what it is for.
- **S6. Before any installation on a street pole (outside this plan).** The pole owner's written permission and a check that the pole can carry about 52 N of wind load at 5.3 m (279 N·m at its base); a trained crew with fall protection and traffic management as local rules require; clear of overhead power lines and street-light wiring; the pole's electrical hatch never opened; both lanyards fitted; the notice plate fitted at the same visit; bands and set screws checked after the first storm.

## 7. Tools, skills and workspace

**Tools.** Hacksaw with a 24 teeth per inch blade (or a bandsaw); bench vice with soft jaws; bench drill or a drill in a stand, with a V-block; drills 2.5 to 12 mm; step drill to 20 mm; countersink; M4 tap and tap drill; jigsaw with a metal blade; flat and half-round files; deburring tool; scriber, engineer's square, combination square with a 45° face, protractor, steel rule and calipers; digital angle finder; spirit level; rivet nut tool for M8; hole saw about 122 mm (or bandsaw) for the cap disc; 3D printer with an enclosure and a 160 x 130 mm bed that prints ASA; heat-set insert tool or a soldering iron with insert tips; soldering iron; ferrule crimper and wire strippers; multimeter; bench power supply with an adjustable current limit; torque screwdriver about 1 to 6 N·m; hex keys; scale to 10 kg; stopwatch; laptop with the calibration viewer.

**Skills.** No certified trade is needed. Basic metalwork (marking out, sawing, drilling, filing, tapping, bending thin sheet, setting rivet nuts), 3D printing in ASA, through-hole soldering and crimping, safe use of a bench power supply and care with lithium cells. All circuits are extra-low voltage: 3.6 V at the cell, 3.3 V on the sensor rail, under about 15 V from the panel. No mains wiring is part of this build.

**Workspace.** A bench about 1.5 x 0.6 m; a metalwork corner kept apart from the electronics; a ventilated place for the printer; the charging spot of S1; floor space about 1.5 x 1.5 m for the stub in its base, with 2.5 m of headroom.

**Personal protective equipment.** Safety glasses for cutting, drilling, bending and soldering; cut-resistant gloves for sheet, bar and the panel; hearing protection when sawing; no gloves near a turning drill.

## 8. Where the numbers come from

- Model and constructability checks: `cad/src/model.py` (`python cad/src/model.py --check`, 106 checks); STEP and STL exports in `cad/step/` and `cad/stl/`.
- Pictures: `cad/src/build_plan_media.py`, using `.kit/build_views.py`; written to `docs/05-build-plan/` and `cad/drawings/CBC-DWG-101` to `CBC-DWG-116`.
- General arrangement: `cad/drawings/CBC-DWG-001.pdf`, Rev P4.
- Calculations: `docs/04-calcs/01-sizing.md` (CBC-CAL-001 v0.4) and `docs/04-calcs/sizing.py`; wind and mount [H1] to [H4], mass [H5], install time [H6], cost [J1].
- Bill of materials: `bom/bom.csv`.
- FieldNode core: FieldNode's build plan FND-BLD-001 and decision record FND-DDR-003.
- Decisions: `docs/decisions/0003-design-for-construction.md` (CBC-DDR-003), with CBC-DDR-001 and CBC-DDR-002; open decisions in `docs/06-design-decisions.md` (CBC-DEC-001).
- Requirements: `docs/03-requirements.md` (CBC-REQ-001 v0.6).

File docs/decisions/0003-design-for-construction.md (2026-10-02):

---
doc_id: CBC-DDR-003
title: CurbCount design for construction
project: CurbCount
doc_type: Design decision record
version: "0.3"
status: Draft
date: '2026-10-02'
author: Amish Chadha
license: CERN-OHL-S-2.0
revisions:
- version: "0.1"
  date: '2026-09-30'
  author: Amish Chadha
  change: Changes that make the concept physically buildable, with the reason for each; made under Amish's 2026-09-30 instruction to make the design physically buildable; open for his review
- version: "0.2"
  date: '2026-10-01'
  author: Amish Chadha
  change: Budget treated as a value-engineering target
- version: "0.3"
  date: '2026-10-02'
  author: Amish Chadha
  change: "Accepted by Amish on 2026-10-02 (Tables 1 to 3); record stays Draft"
---

# 0003: Design for construction

- **Date:** 2026-09-30
- **Status:** accepted. Amish, 2026-10-02: "i approve your recommendations for all 555 open decisions." This covers every change in Tables 1 and 2 and the recommendation in Table 3 (A2), recorded in the design decisions register (CBC-DEC-001). The record stays Draft.

## Context

On 2026-09-30 Amish approved the illustrated build plan format for the portfolio and wrote: "If you are realising that the design cannot be built as per concept - fix the design assumptions to match and be physically feasible as you draw the illustrations." He also asked that outstanding decisions go in a separate design decisions register, not in the build plan.

The TRL 3 model of CurbCount (CBC-DDR-002) showed what the counter does and where its parts sit, but as a massing model: flat plates against a round pole, band clamps drawn as rings that held nothing, a head that floated under its arm, a pole-top mount that could only be made by welding, and parts with no fixing at all. Checking the model with build123d found seven problems (P1 to P7 below).

The changes keep what the counter does: the same thermal array, window height (4.3 m), tilt (7.5 degrees), reach (530 mm from the pole axis) and sensing footprint; the same FieldNode core, cell, 6 W panel at 35 degrees on the pole top; the same four band clamps, no drilling of the pole, the same public notice plate. Nothing here changes the pitch, the privacy case or the safety case. Every change is in `cad/src/model.py`, which now runs 106 constructability checks (`python cad/src/model.py --check`): parts that must touch do touch, and parts that must stay apart are apart by at least the stated clearance. All 106 pass.

## Decision

*Table 1. Changes made to the model, the BOM and the calculations.*

| # | Problem in the concept | Change made | Why this way |
| --- | --- | --- | --- |
| P1 | The enclosure saddle plate was a flat plate against a round 114 mm pole (a line contact that can rock), and the bands were rings round the pole with no path to the plate, so nothing held the plate. The model's plate (140 x 260 x 3 mm) did not match the BOM (160 x 300 x 4 mm). | Plate 160 x 300 x 3 mm with a 100 x 150 mm lightening window behind the box. Two V-saddles bent from 3 mm sheet (20 mm flat, two 65 mm wings at 90 degrees, 40 mm tall) on its back, each on two M4 countersunk screws from the front. Each band passes round the pole, through two 3 x 15 mm slots 66 mm each side of the centre line, and across the plate front above or below the box. | The pole now seats on the faces of a true 90 degree V; 60 to 140 mm poles all seat on both wings. The saddles sit 35 mm inboard of the bands so the band path is clear of the wings on any pole in the range. A bent saddle is lighter and easier to make than a machined block for a pole this large. |
| P2 | The FieldNode enclosure had no fixing to the plate; the board, controller and cell floated inside; the ports and antenna were drawn without glands, vent or nuts. | The FieldNode constructable core of FND-DDR-003: the maker's four lugs at the box's back corners, one M5 screw each through the plate; the internal plate on the four moulded bosses; the six penetrations in two rows on the bottom face; a plug-in connector strip and rail fuses (new BOM line 14). Port A takes the sensor cable, gland 1 the panel lead; port B and gland 2 are capped. Port A's supply is 3.3 V for the array: a load switch from the 3.3 V converter replaces FieldNode's port A boost converter. | CurbCount uses FieldNode's core unchanged, so it takes FieldNode's constructable version rather than inventing its own. |
| P3 | The arm saddle plate (6 x 90 x 160 mm) was too narrow for band slots and sat flat on the pole; the bands were rings; the arm tube butted the plate with no fixing ("welded or bolted"). | Arm saddle plate 160 x 250 x 3 mm with two V-saddles and four band slots, as P1. The tube butts the plate's front and is held by two angle brackets (40 x 40 x 4 mm, 40 mm long), one on top and one underneath: four M6 bolts through the plate (nuts behind it) and two M6 bolts down through both brackets and the tube on crush spacers. The arm is 498 mm long (was 512 mm); the reach is unchanged. | Every joint is face to face and bolted; no welding. The crush spacers stop the 2 mm tube walls from collapsing under the bolts. The brackets carry the head's weight as tension and compression in their legs. |
| P4 | The head floated under the arm (the 7.5 degree tilt left a wedge-shaped gap and overlap) with no fixing; the window film floated inside an opening larger than the film; the array floated; the cable had no way in. | A printed wedge pad on the hood top fills the tilt; two M5 bolts pass down through the arm (on crush spacers) into heat-set inserts in the pad. The housing has an 8 mm ledge inside its open bottom; the film is clamped to it by a printed window frame and four M3 screws into heat-set inserts in four corner bosses. The array breakout sits on four standoffs from the roof. An M16 gland in the pole-side end wall, under the hood, takes the cable. The arm axis rises 8.5 mm to sit on the pad. | The window height, tilt and field of view are unchanged; the frame's 88 x 68 mm opening is far larger than the 30 x 20 mm the lens needs. The gland under the hood is sheltered from rain. |
| P5 | The pole-top mount could only be made by welding (a cap on the sleeve, a post standing on the cap); the hinge plate floated above the post; the panel floated above the hinge plate, which was smaller than the panel and could not reach the frame's lip; three M10 set screws in a 4 mm wall would have under three threads each. | All bolted, no welding. Sleeve 128 x 3 mm tube, 100 mm long, with three M8 rivet nuts and cup-point set screws. An 8 mm cap disc inside the sleeve top on four radial M4 screws; the disc bears on the pole top. The post stands on the disc between two lower clips (50 x 50 x 5 mm angle) on two M8 cross bolts, with a round bar plug in each end of the post. A rail plate 290 x 150 x 3 mm at 35 degrees sits on two upper clips over the post head, on two M8 cross bolts that fix the tilt. The panel is bolted through its frame's back lip to the rail plate's ends. The panel is now centred over the post (it was 40 mm toward the sidewalk); its top is 5.43 m above the road (was about 5.50 m). | Bolted joints a home workshop can make. Rivet nuts give the set screws full thread in a thin wall. The lip is the only part of a framed panel that can carry a bolt. Centring the panel shortens the wind lever. |
| P6 | The sensor cable floated 5 mm off the pole and, where it met the bands, would have been crushed under them; it had no way into the head. There was no panel lead: the panel's 1 m lead cannot reach the enclosure 1.4 m below. | Both cables run up the pole's side, tied every 150 mm, passing over the bands, never under them. The sensor cable leaves port A, runs up the pole, round the arm plate's edge and along the side of the arm, and into the head gland: 1.48 m modelled. It is single-ended (M12 plug at the port, open end into the head). A 1.5 m panel extension lead with a sealed inline connector runs from the panel's own lead down to gland 1 (BOM line 13). | Nothing clamps a cable. The route keeps both cables clear of the V-saddles and bands; the model checks every clearance. |
| P7 | The notice plate had no fixing, and the model's plate (1.5 mm) did not match the BOM (2 mm). | 2 mm plate with four 3 x 10 mm slots; two stainless steel cable ties round the pole and through the slots. | The usual way to fix a small sign to a pole; nothing is drilled. |

*Table 2. Knock-on changes.*

| Item | Change | Reason |
| --- | --- | --- |
| Mass | 5.26 kg on the pole (was 4.44 kg) [H5]; R11 (6 kg) still met on paper. | Saddles, brackets, clips, plugs, rail plate, fixings and the extension lead. Lightening windows in the enclosure plate and rail plate, 3 mm plates, a 100 mm sleeve and an 8 mm disc keep the rise to 0.8 kg. |
| Cost | $274.00 (was $253.00) against the unchanged $275 value-engineering target (`budget_usd`) [J1]: $1.00 under. BOM lines 1, 5, 6, 7, 8, 12 and 13 respecified, 1, 5, 7, 8, 12 and 13 repriced, line 14 added. | Parts added for construction and FieldNode's own repricing of its core ($47 to $49, plus the $5 connector strip). |
| Wind and structure | Post factor 55 (was 38) and 169 N on the pole top (was 192 N) [H1, H2]; pole base moment 279 N·m (was 283 N·m); twist factor 3.3 (was 3.2) [H3]. | The panel now sits over the post and slightly lower. |
| Drawings | CBC-DWG-001 Rev P4; making sketches CBC-DWG-101 to 116 added. | Follows the model. |
| Documents | CBC-CAL-001 v0.4, CBC-PRC-001 v0.6, CBC-REQ-001 v0.6: mass, cost, wind and arm figures updated. No requirement changed status. | Follows the model. |
| Sensing | Unchanged: the window, tilt and camera model are the same, so the footprint (-4.45 to 8.34 m) and resolution (7.6 px/m) stand. | |

*Table 3. Proposed, then accepted by Amish as recommended on 2026-10-02.*

| # | Question | Options | Recommendation |
| --- | --- | --- | --- |
| A2 | Accept the design for construction as a whole (this record). | Accept; or change individual items. | Accept. Accepted by Amish, 2026-10-02. |

## Consequences

- `design_state: constructable` in `project.yaml`. The build plan CBC-BLD-001 shows every component and step in pictures generated from the model (`cad/src/build_plan_media.py`); decisions are recorded in the design decisions register CBC-DEC-001, which accepted this record on 2026-10-02.
- Cost is reported against the value-engineering target: USD 275 (a hypothetical control target, not a limit) against an estimated USD 274.00 for the constructable design, USD 1.00 under; the register lists cost drivers and savings worth trying.
- Requirement status is unchanged: none not met, 3 at risk (R1, R2, R7), 7 met on paper, 1 met by design, 4 not verifiable at TRL 3 (CBC-CAL-001 v0.4).
- The photoreal renders (`media/render-*.png`), `media/card.png`, `media/social-preview.png` and the appearance model `cad/src/product_model.py` still show the concept saddles, arm joint, head fixing and pole-top mount; they need updating on Amish's Mac, where Blender is, to the window frame and M5 bolts of P4 (register item 9), with the notice plate at its installed 2.6 m (item 5) and without the head status light (item 7).
- The enclosure part, its boss spacing and lug kit, the panel's frame lip, the band size for the site pole and the sleeve tube's bore are to be confirmed when parts are bought (CBC-DEC-001).

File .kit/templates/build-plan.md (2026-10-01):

---
doc_id: PRJ-BLD-001
title: Project prototype build plan
project: Project name
doc_type: Build plan
version: "0.1"
status: Draft
date: YYYY-MM-DD
author: Amish Chadha
license: CERN-OHL-S-2.0
revisions:
  - version: "0.1"
    date: YYYY-MM-DD
    author: Amish Chadha
    change: First build plan; design made constructable
---

# Project prototype build plan

**Plan, not yet built.** How to build the first proof-of-concept prototype, component by component. Building and testing to it is TRL 4 work. Decisions still to be made are kept in the design decisions register (`docs/06-design-decisions.md`), not here.

## 1. What you are building

Every component, pulled apart and numbered in build order

One short paragraph: what the prototype is, how many components, which are made and which are bought, and the main ways they are made.

## 2. What changed to make it buildable

| Component | The concept had | The buildable design has | Why |
| --- | --- | --- | --- |

## 3. Making the components

### 3.1 Component name

Making sketch

**What it is and what it is made from.**

**How to make it.**

1. Mark out ...
2. Cut ...

**How it fits the parts next to it.**

Close-up of the joint

**Check before moving on.**

## 4. Putting it together

### Step 1: ...

Step 1

## 5. First checks

| Check | Requirement | How | Pass when |
| --- | --- | --- | --- |

## 6. Safety stops

## 7. Tools, skills and workspace

## 8. Where the numbers come from

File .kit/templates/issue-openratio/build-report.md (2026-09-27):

---
name: Build report
about: Tell us what happened when you built, printed or tested part of this design
title: "Build report: "
labels: build-report
---

This is a research and educational prototype, not a medical device. It is a TRL 3 concept and is not released for fabrication. If you build any part of it, you do so at your own risk. Reports help everyone.

**What you built** (part, sub-assembly or test)

**Materials, tools and settings**

**What worked**

**What did not work, with photos or measurements if you have them**

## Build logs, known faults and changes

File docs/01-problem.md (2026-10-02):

---
doc_id: CBC-PRB-001
title: CurbCount problem statement
project: CurbCount
doc_type: Problem statement
version: "0.8"
status: Draft
date: '2026-10-02'
author: Amish Chadha
license: CERN-OHL-S-2.0
revisions:
- version: "0.1"
  date: '2026-09-25'
  author: Amish Chadha
  change: Initial scaffold
- version: "0.2"
  date: '2026-09-25'
  author: Amish Chadha
  change: Populate to TRL 2 (problem, users, context, constraints, prior work, open questions)
- version: "0.3"
  date: '2026-09-25'
  author: Amish Chadha
  change: TRL 3 update; cost constraint and open questions reflect CBC-CAL-001 and CBC-DDR-001
- version: "0.4"
  date: '2026-09-25'
  author: Amish Chadha
  change: Recommendations accepted by Amish (DDR-002)
- version: "0.5"
  date: '2026-09-26'
  author: Amish Chadha
  change: Stronger sources
- version: "0.6"
  date: '2026-09-30'
  author: Amish Chadha
  change: Parts cost updated to the design for construction (CBC-DDR-003, CBC-CAL-001 v0.3)
- version: "0.7"
  date: '2026-10-01'
  author: Amish Chadha
  change: Budget treated as a value-engineering target
- version: "0.8"
  date: '2026-10-02'
  author: Amish Chadha
  change: "First partner question answered by Amish's 2026-10-02 decision (first candidate to approach: City of Toronto transportation services)"
---

# CurbCount problem statement

Cities decide how to share street space with little evidence of how many people walk and cycle there, and the tools that could supply that evidence either cost too much to deploy widely or rely on cameras that residents reasonably distrust.

## The problem

Walking and cycling carry a large share of trips and a large share of road deaths, yet they are the least counted modes. More than half of the 1.19 million road deaths each year are pedestrians, cyclists and motorcyclists; pedestrians alone account for 23 % and cyclists for 6 % ([WHO, 2023](https://www.who.int/news/item/13-12-2023-despite-notable-progress-road-safety-remains-urgent-global-issue)). In England, walking makes up 29 % of all trips ([Department for Transport, 2024](https://www.gov.uk/government/statistics/walking-and-cycling-statistics-england-2023)). In Africa, more than a billion people walk or cycle every day, yet most countries still lack policies, infrastructure and budgets for these users ([UNEP](https://www.unep.org/resources/report/walking-and-cycling-africa-evidence-and-good-practice-inspire-action)).

Motor traffic is counted routinely with loops and tubes. People on foot and on bicycles are usually counted by hand for a few hours a year, or not at all. Without continuous counts a city cannot show whether a new bike lane or a wider sidewalk changed anything, cannot compute crash exposure at a crossing, and cannot defend a street redesign against the claim that "nobody walks here."

Video analytics can count all modes, but a camera on a pole captures faces, number plates and behavior. Even when the vendor processes video on the device, residents cannot inspect that claim, and a firmware change can turn a counter into a surveillance camera. In the European Union, data protection law requires data protection by design and by default ([Regulation (EU) 2016/679, Article 25](https://eur-lex.europa.eu/eli/reg/2016/679/oj); [text of Article 25](https://gdpr-info.eu/art-25-gdpr/)), and the AI Act prohibits real-time remote biometric identification in publicly accessible spaces for law enforcement except in narrow cases ([Regulation (EU) 2024/1689](https://eur-lex.europa.eu/eli/reg/2024/1689/oj); [text of Article 5](https://artificialintelligenceact.eu/article/5/)). Public tolerance for image capture on streets is low and falling.

The gap is a counter that sees too little to identify anyone, by physics rather than by policy, that is cheap enough to deploy on many poles, and that is open so a city or a residents' group can check exactly what it does.

## Users and context

| User | Need | Context |
| --- | --- | --- |
| City transport planner | Continuous counts by mode and direction, before and after a change | Main streets, school routes, new bike lanes |
| Road safety engineer | Exposure (people per hour) at crossings and junctions to turn crash counts into rates | Crossings, often paired with CrossSafe |
| Residents' group or NGO | Independent evidence to bring to a council meeting, from a device they can inspect | Neighborhood streets, community-led audits |
| Business district or market manager | Footfall by hour and day | High streets, markets |
| Researcher or student | Open, documented count data and a device they can reproduce | Universities, active travel research |
| Asset owner (pole, utility) | A light, clamp-on device that needs no drilling or wiring changes | Street lighting and signal poles |

Operating context: mounted on an existing street pole at 4 to 5 m, outdoors for years, in sun, rain, dust and temperatures from about -20 °C to +50 °C (estimate of the design range), often with no power available at the pole during the day (street lights switch off).

## Constraints

- Garage-buildable prototype, a value-engineering target of $275 USD in parts (a hypothetical control target, not a limit), set by Amish on 2026-09-25 (CBC-DDR-002). The estimated cost of the constructable design is $274.00, $1.00 under the target (CBC-CAL-001 v0.4).
- Built on the lab's shared **FieldNode** power and radio core, as the FieldNode README lists CurbCount among its intended users.
- Privacy by design: no images, audio recordings or personal identifiers leave the device; only aggregate counts are stored or sent.
- Clamp-on mounting with no drilling, welding or electrical connection to the pole.
- Open hardware (CERN-OHL-S-2.0) and open firmware (MIT), so any city or group can audit the device.

## Prior work

- **Commercial counters.** Inductive loops, pneumatic tubes, passive infrared beams and camera analytics are all in service. Loops and tubes count vehicles and bicycles well but not people on foot; infrared beams count people but not direction or mode reliably; cameras count everything but capture images. Most commercial units are closed and priced for city procurement.
- **Low-resolution thermal arrays.** Parts such as the Melexis MLX90640 give a 32 x 24 pixel far-infrared image with a 110 x 75 degree wide-angle option ([Melexis](https://www.melexis.com/en/product/MLX90640/Far-Infrared-Thermal-Sensor-Array)). At pole height each pixel covers roughly 0.3 m of ground, too coarse to show a face.
- **mmWave radar.** Single-chip 60 GHz radars such as the TI IWR6843 are offered with a people counting and tracking reference design for indoor and outdoor use ([Texas Instruments](https://www.ti.com/product/IWR6843)). Radar works in darkness and heat but costs more and draws more power.

No open, auditable, pole-mounted counter combining these parts with a solar-powered LoRaWAN core was found.

## Out of scope

- Identifying, re-identifying or tracking individuals across sensors.
- Speed enforcement or any enforcement use.
- Counting more than the nearest traffic lane of motor vehicles.
- Occupancy of parking or loading bays (see LoadZone).

## User research and co-design

This design is for communities the author is not part of, so requirements come from the people who will use it.

- [ ] Identify a local partner organization (Helpful Engineering network, NGO or university)
- [ ] Run co-design sessions with intended users; record who, where and what was learned
- [ ] Validate load, distance, terrain and cost assumptions in the field
- [ ] Revise requirements (REQ) from findings before freezing the design

## Open questions

- Which partner and street first: a city transport department, a residents' group or a university? Decided by Amish, 2026-10-02 (CBC-DDR-002, O1): a city transport department that already runs manual or loop counts on a street with a bike lane and 60 to 140 mm poles, so its counts can check the counter, with the first trial in a season with air under 20 °C. The first candidate to approach is the City of Toronto's transportation services, which publishes its traffic count data; nothing is agreed.
- Count interval: 15-minute bins, decided by Amish on 2026-09-25 (CBC-DDR-001 D5). A partner should confirm planners do not need a finer interval.
- Public notice: a plate on each pole with a link to this repository, decided by Amish on 2026-09-25 (CBC-DDR-001 D7).
- Hot climates: CBC-CAL-001 shows a thermal-only counter goes blind for much of a hot day. Amish decided on 2026-09-25 that the thermal build is for temperate sites and that the radar variant is brought forward for any hot partner city (CBC-DDR-002). Which partner cities are hot enough to need it depends on the partner choice above.

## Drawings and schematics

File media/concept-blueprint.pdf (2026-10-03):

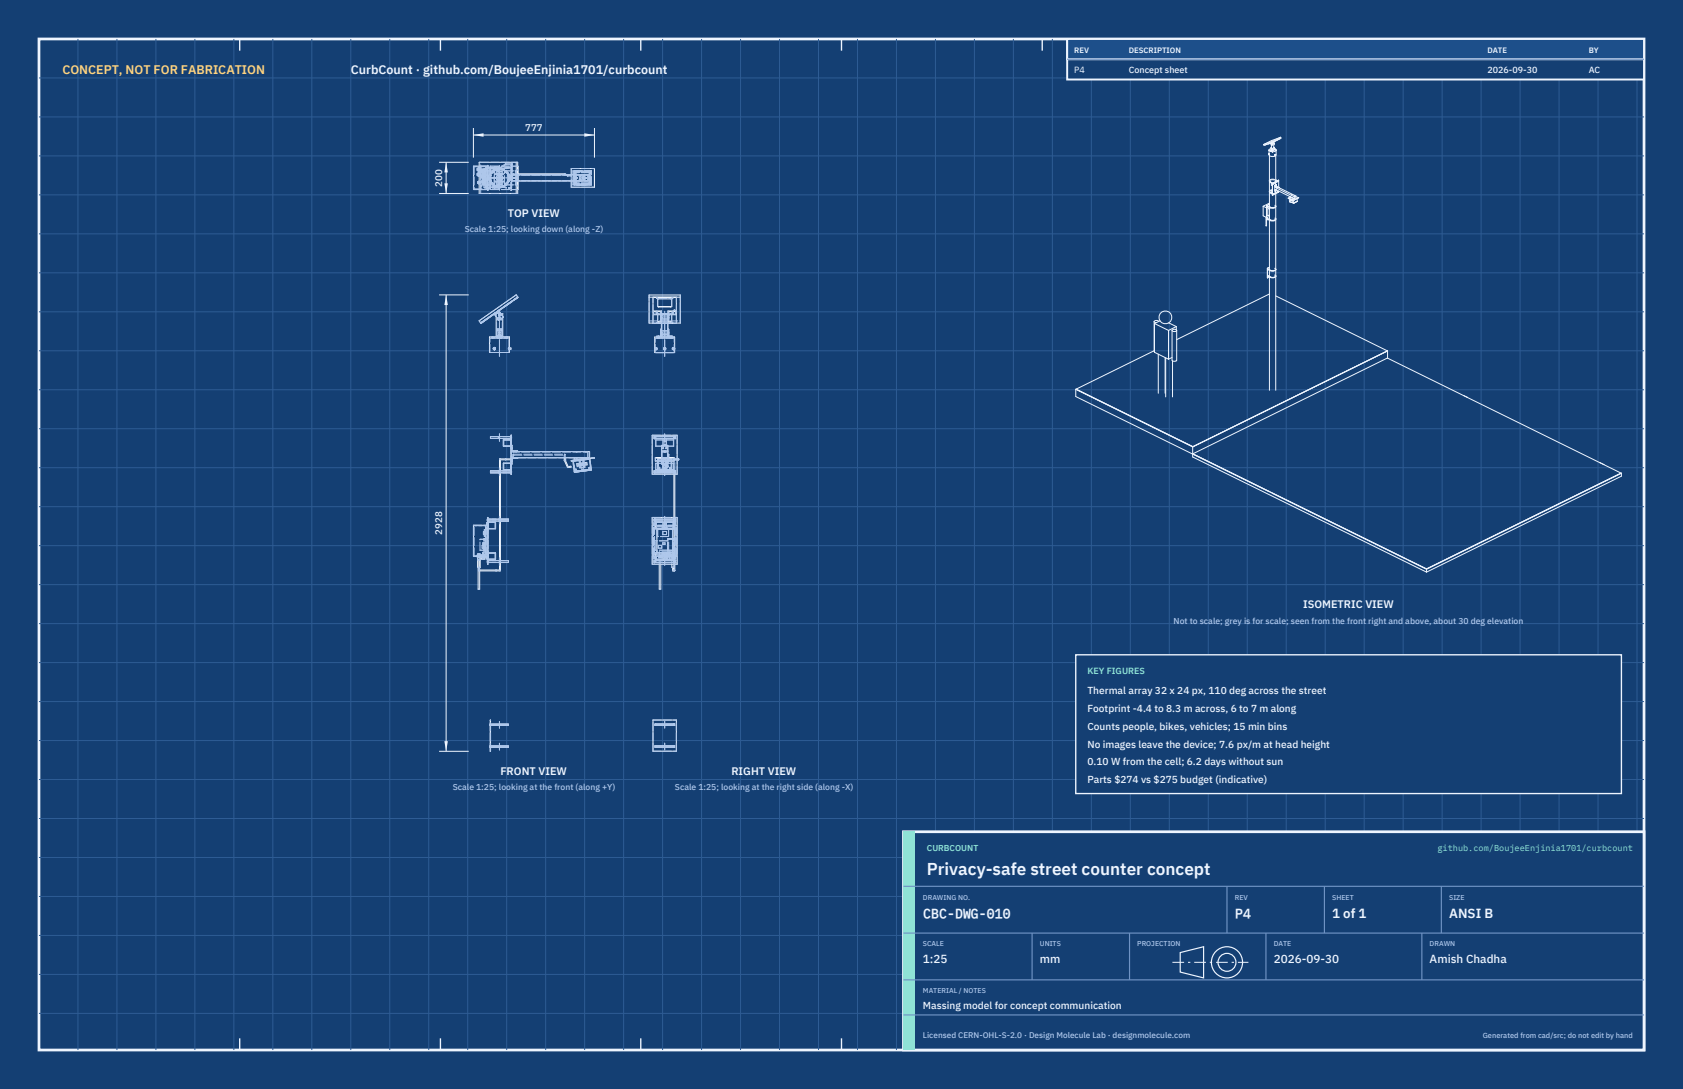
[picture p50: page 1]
CONCEPT, NOT FOR FABRICATION; CurbCount · github.com/BoujeeEnjinia1701/curbcount; FRONT VIEW; TOP VIEW; RIGHT VIEW; ISOMETRIC VIEW; REV; DESCRIPTION; DATE; Concept sheet; CURBCOUNT; github.com/BoujeeEnjinia1701/curbcount; DRAWING NO. CBC-DWG-010; REV P4; SHEET 1 of 1; SIZE ANSI B; SCALE 1:25; UNITS mm; PROJECTION; DRAWN Amish Chadha; Licensed CERN-OHL-S-2.0 · Design Molecule Lab · designmolecule.com; Generated from cad/src; do not edit by hand

Scale 1:25; looking down (along -Z)

Not to scale; grey is for scale; seen from the front right and above, about 30 deg elevation

KEY FIGURES
Thermal array 32 x 24 px, 110 deg across the street
Footprint -4.4 to 8.3 m across, 6 to 7 m along
Counts people, bikes, vehicles; 15 min bins
No images leave the device; 7.6 px/m at head height
0.10 W from the cell; 6.2 days without sun
Parts $274 vs $275 budget (indicative)

Scale 1:25; looking at the front (along +Y)

Scale 1:25; looking at the right side (along -X)

Privacy-safe street counter concept

MATERIAL / NOTES
Massing model for concept communication

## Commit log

2026-09-25 Initial scaffold: standard open hardware layout, CERN-OHL-S v2 + MIT licenses
    Claude-Session: https://claude.ai/code/session_01XuhhSU4W6fYhgCfURbrkut
    [bom.csv]
2026-09-26 Populate to TRL 2: problem, requirements, precis, concept media, BOM and README use cases
    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
    [bom.csv]
2026-09-26 Advance to TRL 3: DDR-001, CAL-001 sizing, parametric model with STEP/STL, GA drawing, priced BOM; TRL 4 on hold
    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
    [bom.csv, curbcount-assembly.step, curbcount-assembly.stl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]
2026-09-26 Accept all recommendations (DDR-002), switch footer to designmolecule.com, add README write-up with new inspiration point
    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
    [bom.csv, curbcount-assembly.step, curbcount-assembly.stl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]
2026-09-27 Product appearance model and photoreal renders
    Adds cad/src/product_model.py (appearance model for renders only, all main
    dimensions from model.py) and Blender renders in media/render-*.png,
    captioned with the project, repository and viewing direction. README leads
    with the product render; trl stays 3.
    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
2026-10-01 Image quality pass: legible exploded views, flow diagrams and drawing sheets
    Kit 1.6.1 image layout: the parts list sits in its own column, number bubbles sit on visible parts and never overlap, small parts get a leader, pictures are cropped to the subject, flow labels keep numbers with their units, and sheet captions and the revision table no longer overprint. Concept images, blueprint and general arrangement sheet regenerated; repo-specific labels moved clear of other text and lines.
2026-10-01 Kit 1.7.0: constructable design, illustrated build plan and design decisions register
    The design is now constructable: every part can be made and fits its neighbours, with each change recorded in a Design for construction decision record (made under Amish's 2026-09-30 instruction; ope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
    [bom.csv, curbcount-assembly.step, curbcount-assembly.stl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]
2026-10-01 Budget treated as a value-engineering target
    Amish, 2026-10-01: the budget is a hypothetical control target that keeps the design on a value-engineering lens, not a spending limit. Documents now state the value-engineering target and the estima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
2026-10-02 Record Amish's approval of the open-decision recommendations
    Amish approved the recommendation on every open decision in the design decisions register ("i approve your recommendations for all 555 open decisions.", 2026-10-02). Each decision is moved to Decisio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
2026-10-03 Carry approved follow-ups into the design and redo photoreal renders
    Amish approved the follow-up actions from the open-decision sign-off ("APPROVED CHANGES, COMPLETE THESE", 2026-10-02), the design-for-construction change tables in ten repos, the last wave's open dec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
    [bom.csv, curbcount-assembly.step, curbcount-assembly.stl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]
2026-11-01 Kit 1.9.1 upgrade: pipeline documents and detailed CAD for every option
    STEM check with fixes under the standing instruction and an independent
    review, concept options scored against the user requirements, URS, PRS,
    RTM, REG, FEA, RSK, MKT, PLN and DDR, every option modelled at D3 with
    cad/fidelity.json passing, and the concept options picture rendered with
    Blender Cycles on Amish's Mac. Concept choices stay proposed, awaiting
    Amish.
    Claude-Session: https://claude.ai/code/session_01LppsZSzPTJWTBAV5wh1Goq
